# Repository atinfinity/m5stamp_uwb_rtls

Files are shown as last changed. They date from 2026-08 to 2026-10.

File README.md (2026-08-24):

# M5Stamp UWB RTLS



M5Stack Stamp UWB (Qorvo QM33120W) + Stamp C5による屋内2D RTLS(リアルタイム測位システム)。

> [!CAUTION]
> 本プロジェクトは**実機での動作確認をまだ行っていません**。データシート・公式ドキュメント・公式サンプルコードなどの公開情報をもとに実装しており、実機では動作しない・調整が必要となる可能性があります(ファームウェア、3Dプリントモデルの寸法などを含む)。

> [!NOTE]
> 本プロジェクトは**非公式の個人プロジェクト**です。M5Stack社・Qorvo社およびその関連企業とは一切関係ありません。

屋内UWB測位のイメージ(アンカー設置とタグ測位)

*屋内にアンカーを設置してタグを測位するイメージ。壁面・柱(高さ1.8〜2.5 m)の四隅にアンカーを設置し、タグが各アンカーへ順次[DS-TWR](docs/ds-twr-design.md)測距 → 得られた距離セットから最小二乗法で2D座標を推定する。配置設計の詳細は[docs/rtls-design.md](docs/rtls-design.md) §3.3を参照。*

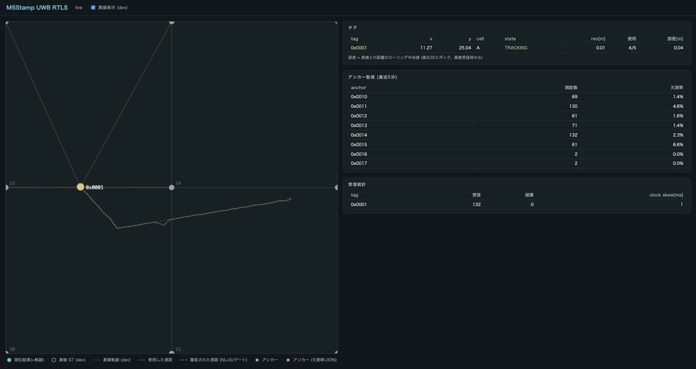
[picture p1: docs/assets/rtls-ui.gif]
RTLSフロアマップUI(仮想タグによるライブ動作)


*可視化UIの動作例(実機レス: 仮想タグ + シミュレータ)。**●** = 測位結果(実線 = 推定軌跡)、**○** = 真値GT(点線 = 真値軌跡、開発モード)、細実線 = 解算に使用した測距、**赤破線** = 外れ値除去/ゲートで棄却された測距(NLoS)。右側は監視パネル(アンカー別欠測率・受信統計)。凡例は画面下部に常時表示される。*

- 設計書: [docs/rtls-design.md](docs/rtls-design.md)(基本設計)ほか[docs/](docs/)配下
  - 測位サーバー(A案): [server-design.md](docs/server-design.md) / タグ上計算(B案): [tag-design.md](docs/tag-design.md)
  - 測距方式: [DS-TWR](docs/ds-twr-design.md)(採用)/ [SS-TWR](docs/ss-twr-design.md)(予備)/ [TDoA](docs/tdoa-design.md)(将来)
- ハードウェア: [docs/hardware.md](docs/hardware.md)(想定ハードウェアリスト・組み立て図)/ [hardware/cad/](hardware/cad/README.md)(アンカー取付具・タグ用ケースの3Dプリントモデル)
- ファームウェア: [firmware/](firmware/)(Step 1: DS-TWR 1対1計測 — Issue [#1](https://github.com/atinfinity/m5stamp_uwb_rtls/issues/1))
- 測位サーバー: [server/](server/)(実機レスで開発可能 — Issue [#3](https://github.com/atinfinity/m5stamp_uwb_rtls/issues/3))
- 開発ガイド: [環境構築](docs/development.md) / [構成カスタマイズ(アンカー・タグ)](docs/configuration.md) / [測位アルゴリズム開発](docs/algorithm-guide.md) / [アプリケーション開発](docs/application-guide.md)([examples/](examples/)にサンプルあり)

## クイックスタート(実機不要)

パッケージ管理は[uv](https://docs.astral.sh/uv/)を使用(`brew install uv`)。詳細な環境構築手順は **[docs/development.md](docs/development.md)** を参照。

```bash
uv sync --all-extras   # .venv 作成 + 依存インストール (dev グループ含む)

# テスト (解算・セル・e2e 回帰: シミュレータ→リプレイで CEP50 ≤ 0.30 m を検証)
uv run pytest

# 合成データ生成 → リプレイ
uv run python tools/simulate.py --config server/config.yaml --duration-s 120 \
    --out logs/sim_ranges.jsonl --truth logs/sim_truth.jsonl
uv run python -m server.replay logs/sim_ranges.jsonl --out logs/positions.jsonl
```

## ライブ実行(仮想タグでend-to-end)

サーバーと仮想タグは起動したまま動き続けるので、ターミナルを分けて実行する([docs/development.md](docs/development.md) §4):

```bash
mosquitto &                                          # MQTT ブローカー (brew install mosquitto)
uv run python -m server.app --config server/config.yaml   # 測位サーバー + Web UI (ターミナル 1)
uv run python tools/virtual_tag.py                        # 仮想タグ 3 台 (ターミナル 2)
```

ブラウザでhttp://localhost:8000 — フロアマップにタグ位置・軌跡・セルハンドオーバーがリアルタイム表示される。実機タグが用意できたらvirtual_tagを実機に差し替えるだけで同じ経路が動く。

## 実機作業(要ハードウェア)

Step 1のDS-TWR実測手順は[firmware/README.md](firmware/README.md)を参照。実測値の反映先はIssue [#1](https://github.com/atinfinity/m5stamp_uwb_rtls/issues/1)のチェックリストにまとめてある。

## 用語集(ドキュメント頻出の略語)

| 用語 | 意味 |
|---|---|
| CEP50 / CEP95 | 測位誤差の中央値 / 95パーセンタイル(Circular Error Probable)。「CEP50 ≤ 0.30 m」= 半数の測位が誤差30 cm以内 |
| LoS / NLoS | 見通しあり / 見通し外(Line of Sight)。遮蔽があるとUWBの測距値は伸びる方向に狂う |
| TWR(SS- / DS-) | Two-Way Ranging。電波の往復時間から1対1の距離を測る方式。SS = 片側往復、DS = 両側往復 |
| TDoA | Time Difference of Arrival。複数アンカーの受信時刻差から測位する方式(将来方式) |
| TDMA | 時分割多元接続。タグごとに送信時間帯(スロット)を割り当てて衝突を防ぐ |
| DOP | 精度劣化指数(Dilution of Precision)。アンカー配置の幾何が悪いほど誤差が拡大する |
| CFO | キャリア周波数オフセット(クロックずれ)。SS-TWRの成否を左右する([ss-twr-design.md](docs/ss-twr-design.md) §2.2) |
| GT | Ground Truth(真値)。シミュレータが出力する正解位置。UIでは ○ と点線で表示 |
| IRLS | 反復再重み付け最小二乗。C++ ソルバーがscipyの代わりに使う近似解法 |

## ライセンス

[Apache License 2.0](LICENSE)

ファームウェアのビルド時に取得される[M5Stamp-UWBライブラリ](https://github.com/m5stack/M5Stamp-UWB)(MIT。同梱のQorvo QM33120WドライバはQorvo独自ライセンス)など、依存ライブラリはそれぞれのライセンスに従う。

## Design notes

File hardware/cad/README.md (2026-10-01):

# 3D CADモデル(アンカー取付具・タグ用ケース)

[docs/hardware.md](../../docs/hardware.md)のハードウェアリストにある「アンカー取付具」「タグ用ケース」の3Dプリント用モデル。OpenSCADのパラメトリックソースと、書き出し済みSTLを置いている。

> **注意**: ボード寸法・背面FPCコネクタ/IPEXの位置は公式ドキュメントの寸法図([Stamp-C5 DIP](https://docs.m5stack.com/en/core/Stamp-C5_DIP) / [Stamp UWB F](https://docs.m5stack.com/en/stamp/stamp_uwb_f)の Model Size)から読み取った値(C5: 17.6×19.06×3.36 mm、うちUSB-C突き出し1.06 mm / UWB F: 幅12.02×長さ11.53×2.82 mm)。**実機でのフィット確認は未実施**。C5はDIP版付属のピンヘッダを**はんだ付けしない**前提(付けると収まらない)。印刷後に合わなければ`common.scad`の`tol`(片側クリアランス)や各パラメータを調整すること。

## ファイル

| ファイル | 内容 |
|---|---|
| `common.scad` | ボード公称寸法・公差などの共通パラメータ |
| `anchor_mount.scad` | アンカー取付具(壁面・柱用Lブラケット) |
| `tag_case.scad` | タグ用ケース(本体 + フタ。`part`で切替) |
| `stl/*.stl` | 書き出し済みSTL(`anchor_mount` / `tag_case_body` / `tag_case_lid`) |
| `Makefile` | STLとdocs用プレビューPNGの再生成 |

## 設計の要点

**アンカー取付具**(`anchor_mount.scad`)

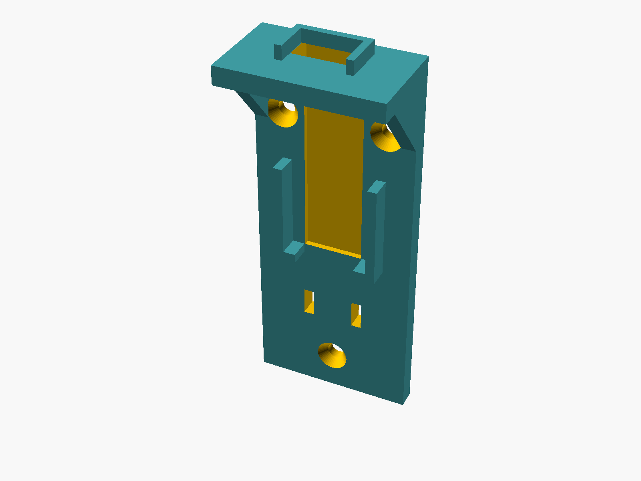
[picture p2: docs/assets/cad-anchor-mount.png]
アンカー取付具3Dモデル


- 垂直プレートを皿ネジM3×3本で壁・柱に固定。プレート前面のポケットにC5、上部棚の上面ポケットにUWB Fを置く(固定は薄手の両面テープを想定)
- アンカーはWi-Fiを使わないため、C5付属のWi-Fiアンテナは取り付けなくてよい(取付具にも収納場所はない)
- UWB Fの**アンテナ端は棚の前縁(壁と反対側)を向き、周囲に樹脂・壁が無い**(基本設計 §3.3の「金属・壁から離して突き出す」要求に対応)
- FPCはプレート前面の溝 → 棚のスリット経由で両ボードの背面コネクタへ(ボードは部品面が表)
- USB給電ケーブルは下方へ引き出し、ケーブルタイ用スリットで張力止め

**タグ用ケース**(`tag_case.scad`)

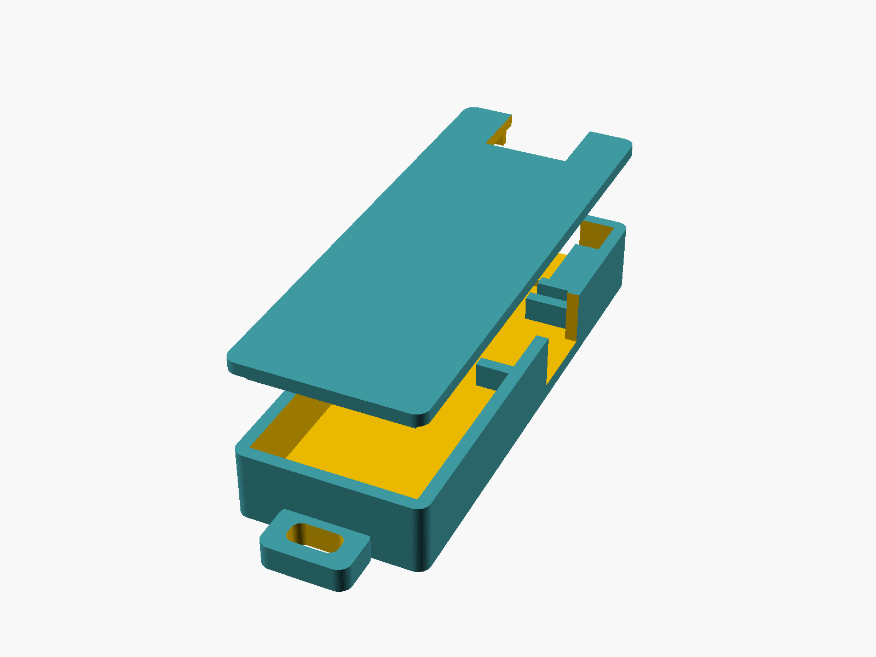
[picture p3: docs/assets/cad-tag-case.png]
タグ用ケース3Dモデル(本体とフタ)


- 内部は長手方向にLiPo | C5 | FPC折り返し部 | UWB F。両ボードとも部品面を上にして置き、背面FPCコネクタは床の凹みに収まる
- C5はUSB-Cを+x側壁に突き当てて置く(VBAT/GNDパッドの列がバッテリー側を向く)。C5の背面FPCコネクタはUSB-Cと反対の端寄りにあり、ケーブルはその端へ出るため、-x側の空きで立ち上げてC5の上を渡し、折り返し部で床に下ろしてUWB Fのコネクタへ差す
- UWB F側の床溝はアンテナ部の下まで延ばさない(公式の注意: FPCをPCBアンテナの下に通さない)
- UWB Fの**アンテナ端はケース端・フタの開口(アンテナ窓)で樹脂に覆われない**
- C5のUSB-Cは側壁スロットから充電・書き込み可能。バッテリー端にストラップループ
- C5同梱のWi-Fi用FPCアンテナ(14.3×5.3 mm、IPEX-1)は**フタ裏の凹み(C5の上、+x寄り)に貼る**。C5の上を渡るFPCケーブル・UWB F・LiPoから離して配置し、ケーブル(50 mm)はキャビティ内で余らせる
- フタはスカートによる摩擦嵌合。LiPo寸法は`bat`パラメータ(既定25.5×37×5.2 mm = [docs/hardware.md](../../docs/hardware.md) §1.4の候補例 DPTL-DTP502535 400 mAh)で変更

## 印刷設定の目安

- PLA / PETG、レイヤー0.2 mm、インフィル20% 程度
- 向き: 取付具は背面(壁側)をベッドへ、ケース本体は底面、フタは天面をベッドへ → **いずれもサポート不要**

## 再生成

macOSで[OpenSCAD](https://openscad.org/)をインストール(`brew install --cask openscad`)して:

```bash
cd hardware/cad
make          # stl/ と docs/assets/cad-*.png を再生成
# OpenSCAD のパスが違う場合: make OPENSCAD=/path/to/OpenSCAD
```

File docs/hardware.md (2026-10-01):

# ハードウェアガイド(想定ハードウェアリスト・組み立て)

本システムで想定しているハードウェアの一覧と、ノード(アンカー・タグ)の組み立て方をまとめる。設計上の根拠(選定理由・BOM概算・配置設計)は基本設計[rtls-design.md](rtls-design.md) §3を参照。

数量は**タグ1台 + アンカー1台**の最小構成(DS-TWR 1対1測距 = [firmware/README.md](../firmware/README.md) Step 1相当)で記載する。2D測位では1セルあたりアンカー4台が標準(解算だけなら3台が下限)。実運用の数量(アンカー8〜12 + タグ2〜5)と価格概算は[rtls-design.md](rtls-design.md) §3.1〜3.3を参照。

## 1. 想定ハードウェアリスト

アンカー・タグはどちらも**M5Stamp C5 + M5Stamp UWB F**の同一ユニットで、ファームウェアと電源だけが異なる。

### 1.1 アンカー用(1台分)

| 品目 | 用途 | 数量 | 備考 |
|---|---|---|---|
| [M5Stamp C5](https://shop.m5stack.com/products/m5stampc5-module-esp32-c5)(ESP32-C5) | メインMCU | 1 | アンカーはWi-Fi接続不要(UWB応答専用) |
| [M5Stamp UWB F](https://shop.m5stack.com/products/m5stamp-uwb-module-with-fpc-qm33120w)(Qorvo QM33120W、FPC版) | UWB測距モジュール | 1 | 0.5mm-12P FPCケーブル付属。[無印版](https://shop.m5stack.com/products/m5stamp-uwb-module-qm33120w)(キャスタレーション実装)は量産フェーズ向けで、プロトタイプはFPC版を推奨 |
| USB ACアダプタ + USB-Cケーブル | 常時給電 | 1 | モバイルバッテリーでも可 |
| アンカー取付具 | 壁面・柱への設置 | 1 | 3Dプリント(モデルは[hardware/cad/](../hardware/cad/)、§4参照)。アンテナ部を遮らない形状 |

### 1.2 タグ用(1台分)

| 品目 | 用途 | 数量 | 備考 |
|---|---|---|---|
| [M5Stamp C5](https://shop.m5stack.com/products/m5stampc5-module-esp32-c5)(ESP32-C5) | メインMCU + Wi-Fiテレメトリ | 1 | Wi-Fi 6(2.4/5 GHz)対応。SGM40567充電IC・電池端子内蔵 |
| [M5Stamp UWB F](https://shop.m5stack.com/products/m5stamp-uwb-module-with-fpc-qm33120w)(Qorvo QM33120W、FPC版) | UWB測距モジュール | 1 | 同上(FPCケーブル付属) |
| LiPoバッテリー3.7 V 400〜1000 mAh | 電源 | 1 | Stamp C5のVBAT/GNDパッドにはんだ付け。充電はUSB-C経由 |
| タグ用ケース | 装着用筐体 | 1 | 3Dプリント(モデルは[hardware/cad/](../hardware/cad/)、§4参照)。アンテナ部を遮らない形状 |

### 1.3 共通(システム全体で)

| 品目 | 用途 | 数量 | 備考 |
|---|---|---|---|
| PC(常設ならRaspberry Piも可) | 測位サーバー(Mosquitto + Python解算/可視化) | 1 | |
| Wi-Fi AP(2.4/5 GHz) | タグ→サーバーのテレメトリ経路 | 1 | 既設流用可。アンカーはWi-Fi不要 |
| レーザー距離計 | アンカー座標の測量・校正 | 1 | 推奨(±3 cm以内で座標登録するため) |

### 1.4 購入時の注意

- **国内での入手先**: スイッチサイエンスで[M5Stamp UWBモジュール(FPCコネクタ、FPCケーブル付き)M5STACK-S017-F](https://www.switch-science.com/products/11375)と[M5StampC5 DIP M5STACK-S016-DIP](https://www.switch-science.com/products/11352)が扱われており、本ドキュメントの想定構成と一致する。アンカー・タグとも同一ユニットなので、両方をノード台数分そろえる。
- **Stamp C5「DIP」版のピンヘッダ**: DIP版には2.54mm-7Pピンヘッダ2本が付属するが、UWB FとはFPCで直結するため**はんだ付けは不要**。§4の3Dプリントモデルはヘッダなしの公称寸法で作っているので、ヘッダを付けるとケース・取付具に収まらない可能性がある。
- **Wi-Fi用外付けアンテナ**: Stamp C5のWi-Fiは付属アンテナ(FPCアンテナ、2.4/5 GHz、IPEX-1、14.3×5.3 mm、ケーブル長50 mm。[公式ドキュメント](https://docs.m5stack.com/en/core/Stamp-C5)参照)をIPEX-1コネクタにつないで使う。Stamp C5に同梱されているので別途購入は不要。タグはWi-Fiテレメトリに必須(アンカーはWi-Fi不要)。タグ用ケースではフタ裏の凹みに貼る(§4.2)。
- **LiPoバッテリーは別途必要**(タグのみ)。Stamp C5の充電電流は約200 mAなので、1C充電で200 mA以上を受け入れられる容量(目安400 mAh以上)を選ぶ。候補例(いずれもDATA POWER TECHNOLOGY製、JST PH 2ピン、保護回路付き。2026年10月時点で千石電商に在庫あり。購入時に在庫を確認):
  - [DTP502535(PHR) 400mAh](https://www.sengoku.co.jp/mod/sgk_cart/detail.php?code=EEHD-4YZL)(25×36×5 mm、10 g以下)— §4のタグ用ケースの既定寸法(`bat`)で収まる。推奨
  - [DTP603048(PHR) 860mAh](https://www.sengoku.co.jp/mod/sgk_cart/detail.php?code=EEHD-4YZM)(30×49×6 mm、18 g以下)— 長時間向け。タグ用ケースは`bat`を変更して再生成する(幅約5 mm・長さ約12 mm大きくなる)

  スイッチサイエンスの同型400mAh品([3118](https://www.switch-science.com/products/3118))は2026年10月時点で品切れ。

  Stamp C5にバッテリー用コネクタはなく、2.54 mmピッチのパッド列の**VBAT(+)とGND(−)**に配線する([公式ピン配置図](https://docs.m5stack.com/en/core/Stamp-C5_DIP)。部品面を上・USB-Cを手前にして左列の上から3V3 / G1 / G2 / G3 / **VBAT** / USB_5V / **GND**)。JST PHコネクタ付きの電池をそのまま使うなら、[JST PH 2ピン付きワイヤ](https://switch-science.com/catalog/2215)をパッドにはんだ付けして中継する。電池側の極性(赤=+)も挿す前に確認すること。§4のタグ用ケースはLiPo寸法を`bat`パラメータで変更できる。

## 2. 組み立て図

Stamp C5とStamp UWB Fは、UWB F付属の**0.5mm-12P FPCケーブル1本**で直結する。FPCにSPI 5線+制御2線+電源がまとまっており、Stamp C5背面FPCコネクタのピン割当が公式サンプルの想定(SCK=G12, MISO=G26, MOSI=G27, CS=G11, RST=G25, IRQ=G0, WAKEUP=G24, GP7=G23)と一致しているため、**はんだ付け・配線作業は不要**。

### 2.1 アンカーノード

アンカーノード組み立て図(1台分)

### 2.2 タグノード

タグノード組み立て図(1台分)

## 3. 組み立て手順

1. **FPC接続**: Stamp C5背面とStamp UWB FのFPCコネクタに付属ケーブルを挿し、コネクタのロックを閉じる(アンカー・タグ共通)。**ケーブルの向きを誤るとモジュールを破損するおそれがある**(製品ページの注意事項)ため、公式の接続図で向きを確認してから挿す。なお、UWB FのFPCピン配置はStamp-S3/S3Aとは互換性がない(Stamp C5とは一致する)。
2. **Wi-Fiアンテナ接続**(タグ): Stamp C5のIPEX-1コネクタに付属アンテナを接続する。
3. **電源接続**:
   - アンカー: USB ACアダプタまたはモバイルバッテリーからUSB Type-Cで常時給電。
   - タグ: LiPoバッテリーをStamp C5のVBAT/GNDパッドへ接続(§1.4。充電はUSB-C経由)。開発初期はUSB給電でよい(下記「開発初期の給電」参照)。
4. **ファームウェア書き込み**: USB-CでPCに接続し、[firmware/](../firmware/)の手順でanchor / tagを書き込む。
5. **筐体・設置**: ケース・取付具(§4の3Dプリントモデル)に収める。以下のアンテナ取り扱いに注意する。

### 開発初期の給電

ケースに組み込む前の開発初期は、アンカー・タグともUSB Type-Cから給電すればよい。LiPoのはんだ付けはケースへの組み込み時([#49](https://github.com/atinfinity/m5stamp_uwb_rtls/issues/49))まで後回しにできる。

- **PCのUSB**: 給電とシリアルログ取得を兼ねられる。[firmware/README.md](../firmware/README.md) Step 1のDS-TWR 1対1測距では、ログを取る側をPCにつなぐ。
- **モバイルバッテリー**: PCから離して置くノード(アンカーや、距離を変えながら測るタグ)に使う。
  - **低電流での自動電源オフに注意**。多くの製品は出力がおおむね50〜100 mA以下になると数十秒〜数分で給電を止める。UWB Fの消費電流は公式値で受信側(アンカー)約58 mA、発信側(タグ)約5 mA(C5側は未確認)のため、省電力設定次第では自動オフの条件に入りうる。「低電流モード」「IoTモード」付きの製品を選ぶか、アンカーのように据え置くノードはUSB ACアダプタにする。測距が途中で止まったら、まず給電断を疑う。
- **電源ノイズ**: UWB Fは公式に「高PSRRのLDO、またはリップル12 mVpp以内の電源」を求めている。USBの5VはC5上で3.3Vに変換してからUWB Fに供給されるが、その変換回路の特性は未確認。測距値のばらつきが大きいときは、USB ACアダプタやPCのUSBに替えて比べ、電源が原因かを切り分ける。
- LiPoを取り付けた後は、USBとLiPoを同時につないでよい(C5の充電IC SGM40567がUSB接続時にLiPoを充電する)。

### アンテナ取り扱いの注意(重要)

- **アンテナ端が金属・壁から離れるよう突き出して取り付ける。金属板への直付けは禁止**(公式ドキュメントの要求)。
- 机上での実験時も、アンテナ端が金属・机面に近づかないよう治具等で浮かせる([firmware/README.md](../firmware/README.md) Step 1参照)。
- アンカーの設置高さ・配置(高さ1.8〜2.5 m、セル四隅、座標測量)は[rtls-design.md](rtls-design.md) §3.3を参照。

## 4. 3Dプリントモデル(アンカー取付具・タグ用ケース)

OpenSCADソースとSTLを **[hardware/cad/](../hardware/cad/)** に置いている(パラメータ調整・再生成の方法は同ディレクトリの[README](../hardware/cad/README.md)を参照)。公称寸法ベースのv1モデルのため、印刷後に実機でフィット確認し`tol`等を調整すること。

### 4.1 アンカー取付具

アンカー取付具3Dモデル

壁面・柱用のLブラケット([anchor_mount.scad](../hardware/cad/anchor_mount.scad) / [STL](../hardware/cad/stl/anchor_mount.stl))。皿ネジM3×3本で固定し、前面ポケットにC5、上部棚にUWB Fを置く。UWB Fのアンテナ端は棚の前縁(壁と反対側)を向き、「金属・壁から離して突き出す」要求(§3アンテナ注意・[rtls-design.md](rtls-design.md) §3.3)を満たす。FPCはプレート前面の溝と棚のスリットを通す。

### 4.2 タグ用ケース

タグ用ケース3Dモデル(本体とフタ)

本体 + 摩擦嵌合フタの2部品([tag_case.scad](../hardware/cad/tag_case.scad) / STL: [本体](../hardware/cad/stl/tag_case_body.stl)・[フタ](../hardware/cad/stl/tag_case_lid.stl))。内部はLiPo | C5 | FPC折り返し部 | UWB Fの順で、アンテナ端はケース端とフタの開口(アンテナ窓)により樹脂で覆われない。FPCケーブルはC5の上を渡して折り返し部で床に下ろす(経路の詳細は[hardware/cad/README.md](../hardware/cad/README.md))。USB-Cは側壁スロットから充電・書き込み可能で、バッテリー端にストラップループ付き。C5のWi-Fi用FPCアンテナはフタ裏の凹み(C5の上、+x寄り)に貼る。LiPo寸法は`bat`パラメータで変更できる(既定は§1.4の400 mAh品)。

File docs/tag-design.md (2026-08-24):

# タグ上測位詳細設計書(B案: タグ上計算)

- 作成日: 2026-08-15
- ステータス: ドラフト(実装前レビュー用)
- 上位文書: [rtls-design.md](rtls-design.md)(基本設計 §5の「B案: タグ上計算」の詳細設計)
- 関連文書: [server-design.md](server-design.md)(A案。解算アルゴリズムは本書と共通仕様)

## 1. スコープと位置づけ

本書は、**タグ(ESP32-C5)上で測距から座標解算までを完結**させる構成の詳細設計を定める。基本設計 §5の比較で標準構成はA案(サーバー計算)としたため、B案は次の用途を主対象とする。

| 想定用途 | 説明 |
|---|---|
| **自律移動体搭載** | ロボット・AGVがタグを搭載し、自己位置を低レイテンシで直接利用する(サーバー往復 +20〜100 msを排除) |
| サーバーレス運用 | 可視化・記録が不要で、座標を外部システム(ROS等)へ直接渡すだけの構成 |
| ネットワーク断耐性 | Wi-Fiが不安定な環境でも測位自体は継続する必要がある場合 |

**設計方針: A案と同一の解算仕様(§4)をC++ に移植し、A案に劣る点(デバッグ性・チューニング性)を「生距離の並行送信」と「OTA更新」で緩和する。** 解算アルゴリズムの仕様はserver-design.md §5を正とし、本書ではESP32実装に固有の差分のみ規定する。

## 2. システム構成と動作モード

```mermaid
flowchart LR
    subgraph tag["タグ (Stamp C5 + UWB F)"]
        RNG["ranging<br/>TDMA スロット測距"]
        SOL["solver<br/>補正→LSQ→外れ値除去→カルマン"]
        CFG["config_store<br/>アンカー座標・セル表 (NVS)"]
        OUT["output<br/>座標出力の抽象層"]
        RNG --> SOL
        CFG --> SOL
        SOL --> OUT
    end
    OUT -- "① MQTT position" --> BR["MQTT ブローカー"]
    OUT -- "② UART (ROS 等)" --> HOST["搭載ホスト<br/>(ロボット制御器)"]
    RNG -. "生距離も並行 publish<br/>(debug_ranges 有効時)" .-> BR
    BR -- "config/anchors (retained)" --> CFG
    BR -- "OTA 通知" --> tag
```

| モード | 出力 | 用途 |
|---|---|---|
| `HYBRID`(既定) | MQTTへposition **と生距離の両方**をpublish | 開発・チューニング期。サーバー側リプレイ(A案 §8)をそのまま使える |
| `STANDALONE` | UART(またはUDPユニキャスト)へpositionのみ | ロボット搭載。Wi-Fiなしでも測位継続 |
| `QUIET` | MQTTへpositionのみ | 帯域・電力を絞る本番運用 |

モードはNVS設定で切替(ビルド不要)。**HYBRIDを既定とし、B案の最大の弱点「座標しか見えず誤差原因を追えない」を運用で回避する。**

## 3. ファームウェア構成(PlatformIO)

```
firmware/tag/
├── platformio.ini           # env:tag (esp32-c5) / env:native (ホストテスト用)
├── src/
│   ├── main.cpp             # 起動・タスク生成
│   ├── ranging.cpp/.h       # TDMA スロット管理・アンカー巡回測距
│   ├── net.cpp/.h           # Wi-Fi / SNTP / MQTT / OTA
│   ├── config_store.cpp/.h  # NVS 永続化と config/anchors 受信反映
│   └── output.cpp/.h        # position の出力先抽象化 (MQTT/UART/UDP)
├── lib/rtls_solver/         # ★解算ライブラリ(ハード非依存・ヘッダオンリー)
│   ├── geometry.hpp         # 高低差補正・線形化LSQ・Gauss-Newton
│   ├── outlier.hpp          # ゲーティング・leave-one-out
│   ├── kalman.hpp           # CV モデル 2D カルマン (4状態、固定サイズ行列)
│   └── pipeline.hpp         # §4 のパイプライン統合
└── test/                    # env:native で動く solver 単体テスト
```

**`rtls_solver`はArduino APIに依存させない**(素のC++17、`float`固定サイズ配列のみ)。これにより:

- PlatformIOの`env:native`でホストPC上の単体テストが回る(実機不要)
- A案のシミュレータ出力(ranges JSONL)をホストで流し込み、**Python実装との解算結果一致試験**ができる(§8)

### FreeRTOSタスク構成

| タスク | 優先度 | 周期/契機 | 役割 |
|---|---|---|---|
| `ranging_task` | 高 | TDMAスロット到来 | アンカー巡回DS-TWR → RangeSet生成 → solver呼出し → outputへ渡す |
| `net_task` | 中 | イベント駆動 | MQTT送受信、SNTP再同期(**5分毎・スルー補正+ドリフト率補正**、rtls-design.md §4.9)、OTA受付 |
| `monitor_task` | 低 | 1 s | ヒープ・測距成功率・スロットずれの統計、LED表示 |

solverは`ranging_task`内で同期実行する(実測目標 < 5 ms、§7)。キュー渡しにしないことでスロット内で解算まで完結し、座標のタイムスタンプが単純になる。

## 4. 解算パイプライン(C++ 移植仕様)

処理段構成・パラメータ・状態機械(INIT/TRACKING/COASTING/STALE/LOST)は**server-design.md §5と同一**。ESP32実装での差分のみ示す。

| 段 | A案(Python) | B案(C++)の実装 |
|---|---|---|
| ① 検証 | pydantic | 不要(自プロセス内でRangeSetを生成するため。okフラグ確認のみ) |
| ② 高低差補正 | 同一式 | 同一式(`sqrtf`) |
| ③ ゲーティング | 同一 | 同一 |
| ④ 線形化LSQ | `numpy.linalg.lstsq` | 正規方程式`AᵀA x = Aᵀb`を**2×2の手解き**(逆行列公式)。条件数チェック(detが小さい=共線配置なら解算失敗扱い) |
| ⑤ リファイン | `scipy.least_squares` (soft_l1) | **Gauss-Newton最大5反復** + Huber重み(δ=0.3 m)。2×2正規方程式の反復なので軽量。発散(ステップ > 1 m)時は線形解を採用 |
| ⑥ 外れ値除去 | 最悪1距離除外・1回 | 同一 |
| ⑦ カルマン | numpy | 4×4固定サイズ行列をベタ書き(行列ライブラリ不使用)。`float`で十分(座標50 m / 分解能cm) |

**数値仕様**: 全計算`float`(単精度)。距離二乗の桁(最大55² ≈ 3000)でもfloatの7桁精度でcm分解能を維持できるが、線形化LSQの右辺`(x_i²−x_1²)`等は**座標をフロア中心原点に平行移動してから計算**し桁落ちを防ぐ。

## 5. アンカー座標・セル表の配布(config_store)

B案固有の課題: A案ではサーバーだけが持っていたアンカー座標・セル定義を**全タグが持つ**必要がある。

- サーバー(または管理PCの配布スクリプト)が`rtls/config/anchors`に**retained + version付き**で全体設定をpublishする:

```json
{"version": 3,
 "tag_height_m": 1.0,
 "anchors": {"0x0010": {"x": 0.0, "y": 0.0, "z": 2.2, "bias_mm": -35}, "...": {}},
 "cells":   {"A": {"rect": [0,0,25,25], "anchors": ["0x0010","0x0011","0x0013","0x0014"]}}}
```

- タグは起動時と受信時にversionを比較し、新しければ**NVSに保存して即反映**。以後はWi-Fi断でもNVSの設定で動作継続(STANDALONEモードの前提)。
- 12アンカー + 8セルでJSON約2 KB、NVS使用量は問題にならない。パース失敗時は旧設定を維持。
- **セル判定・ハンドオーバーはタグ自身が実行**(アルゴリズムはserver-design.md §6と同一のヒステリシス)。サーバーからのアンカーリスト配信(`rtls/tag/{id}/anchors`)は不要になり、A案とのトピック互換のため受信しても無視する。

## 6. TDMAスロット内の処理シーケンス

基本設計 §4.4のスーパーフレーム(500 ms、スロット90 ms)の中で解算まで行う。

```mermaid
sequenceDiagram
    participant S as ranging_task
    participant U as UWB (QM33120W)
    participant K as solver
    participant O as output
    Note over S: SNTP 時刻で自スロット開始を検出
    loop 担当アンカー 4 台
        S->>U: requestDSRange(anchor_i)
        U-->>S: 距離 or タイムアウト(必要なら1回リトライ)
    end
    S->>K: RangeSet(4距離, t_ms)
    K->>K: 補正→ゲート→LSQ→GN→外れ値→カルマン
    K-->>S: Position (x, y, state, residual)
    S->>K: セル判定(ヒステリシス)→次スロットの巡回リスト更新
    S->>O: Position 出力
    par HYBRID モード時
        O->>O: MQTT: position + ranges を publish(net_task キュー経由)
    and STANDALONE モード時
        O->>O: UART: バイナリフレーム送出 (< 1 ms)
    end
```

### スロット内時間予算(90 ms、実測で確定させる)

| 処理 | 予算 |
|---|---|
| DS-TWR × 4(リトライ1回込み) | ~60 ms(1回5〜10 ms想定 — 基本設計ロードマップStep 1で実測) |
| アンカー間ギャップ × 3 | ~6 ms(`kDsInterAnchorGapMs` = 2 ms。Step 1で最小値を実測) |
| 解算(§4パイプライン) | < 5 ms(目標。240 MHzで数十 µsオーダーの見込み) |
| 出力(UART即時 / MQTTはキュー投入のみ) | < 1 ms |
| ガード余裕 | 残り ~25 ms |

MQTTの実送信は`net_task`が非同期に行い、**スロット時間をWi-Fiの遅延で食わない**。

## 7. UART出力仕様(STANDALONE / ロボット搭載向け)

115200 bps、バイナリフレーム(リトルエンディアン):

| オフセット | 型 | 内容 |
|---|---|---|
| 0 | uint8×2 | ヘッダ`0xB5 0x50` |
| 2 | uint8 | tag_id |
| 3 | uint8 | state (0=INIT,1=TRACKING,2=COASTING,3=STALE,4=LOST) |
| 4 | uint32 | t_ms(SNTP同期時刻の下位32bit) |
| 8 | float×4 | x_m, y_m, vx_ms, vy_ms |
| 24 | float | residual_m |
| 28 | uint8 | n_used |
| 29 | uint8 | checksum(0〜28のXOR) |

30バイト固定。2 Hzなら帯域は無視できる。ROS側はシリアルノードでこのフレームを`PoseWithCovarianceStamped`に変換する想定(residualから共分散を組み立てる)。

## 8. チューニング・デバッグ戦略(B案の弱点への対策)

| A案に劣る点 | 本設計での緩和策 |
|---|---|
| アルゴリズム変更のたびに書き込みが必要 | **OTA更新**(`esp_https_ota`、`net_task`がMQTTの更新通知で起動)。全タグへ一括配信 |
| 誤差原因(どの距離が狂ったか)を追えない | **HYBRIDモード**で生距離を並行publish → A案のrecorder/replayがそのまま使える |
| パラメータ試行錯誤が遅い | `tuning`パラメータ(gate、residual_gate、σ 類)を**NVS + MQTT `rtls/config/tuning`(retained, version付き)** で配布し、書き込み不要で変更 |
| 解算実装がPythonと乖離するリスク | `rtls_solver`を`env:native`でビルドし、**同一ranges入力に対するPython実装との一致試験**(許容差1 cm)をCI的に実行 |

## 9. リソース見積もり

| 項目 | 見積もり | 備考 |
|---|---|---|
| solverコード + 状態 | < 10 KB RAM | 4×4行列float数個 + 履歴なし |
| config(12アンカー + セル表) | ~4 KB RAM / ~2 KB NVS | |
| Wi-Fi + MQTT + TLSなし | ~50 KB RAM | ESP32標準スタック |
| 合計 | 384 KB SRAMに対し余裕 | PSRAM不要 |
| 解算CPU時間 | 数十 µs〜1 ms /エポック | 240 MHz、FPUあり |
| 消費電力への影響 | 解算分は無視できる(支配項はUWB測距とWi-Fi) | 基本設計 §7のタグ電池リスクと同じ |

## 10. テスト計画

1. **ホスト単体テスト(`env:native`、実機不要)**: server-design.md §13の1. と同一ケース(合成ジオメトリ、NLoS注入、軌跡追従、縮退配置)をC++ 側でも実行。
2. **Python一致試験**: A案シミュレータのranges JSONLをホストビルドのsolverに入力し、Python実装のpositionsと突き合わせる。許容差: **中央値 ≤ 1 cm・p99 ≤ 2 cm・最大 ≤ 10 cm**(外れ値除去が発火するエポックはscipy soft_l1とIRLS Gauss-Newtonの反復差がcm級で現れるため。実測: 中央値0.0 mm / p99 0.34 mm / 最大16.9 mm、状態一致100%)。**以後、アルゴリズム変更は必ず両実装同時に行う**ことをルール化。
3. **実機タイミング試験**: スロット内の各処理時間(測距×4、解算、出力)を`esp_timer`で計測し、§6の時間予算表を実測値で更新。90 msに収まらない場合はリトライ回数かアンカー数を調整。
4. **断線試験**: Wi-Fi AP停止 → STANDALONE動作(UART出力継続)→ 復帰後のMQTT再接続とconfig version追従を確認。
5. **受入基準**: A案と同一(CEP50 ≤ 0.30 m等)+ UART出力レイテンシ(測距完了→フレーム送出)p95 < 10 ms。

## 11. A案との使い分け・移行

- **開発は常にA案の環境(シミュレータ・リプレイ・可視化)で先行**し、確定したアルゴリズム・パラメータをB案へ移植する流れとする(§8の一致試験が橋渡し)。
- タグFWはA案構成でもB案構成でも**測距・TDMA部分(`ranging.cpp`)は共通**。差分は「solverを積むか」「何をpublishするか」のみで、ビルドフラグ`-DENABLE_ONBOARD_SOLVER`で切り替える。
- 運用上の推奨: 人・資産の追跡はA案、ロボット搭載タグのみB案(HYBRIDモード)、という**混在構成**が可能。B案タグの生距離もサーバーに届くため、フロア全体の監視・記録はA案側に一元化できる。

## 12. 実装順序

1. `rtls_solver`(ヘッダオンリー)+ `env:native`単体テスト — A案 §15の2. のPython実装と並走
2. Python一致試験(§10の2.)の整備
3. `ranging.cpp`のTDMA化(基本設計Step 3と共通作業)
4. `config_store` + `rtls/config/#`配布フロー
5. `output`(MQTT HYBRID → UART)+ 実機タイミング試験
6. OTA・`rtls/config/tuning`反映 — 運用開始後のチューニングループ確立

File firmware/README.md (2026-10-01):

# ファームウェア

| 対象 | env | 内容 |
|---|---|---|
| `tag`(本番) | `tag` | アンカー巡回 + TDMA + Wi-Fi/MQTT(Step 2/3、Issue [#6](https://github.com/atinfinity/m5stamp_uwb_rtls/issues/6)) |
| `tag`(計測) | `tag_step1` | 1対1 DS-TWR + CSV出力(Step 1、Issue [#1](https://github.com/atinfinity/m5stamp_uwb_rtls/issues/1)) |
| `tag`(計測・SS) | `tag_step1_ss` | 1対1 SS-TWR検証(Issue [#14](https://github.com/atinfinity/m5stamp_uwb_rtls/issues/14)) |
| `anchor` | `anchor` | DS-TWR応答専用 |
| `anchor`(SS) | `anchor_ss` | SS-TWR応答(検証用) |
| `tdoa_poc` | `blink_tx` / `listener` | TDoA PoC: 周期ブリンク送信 / RXタイムスタンプ計測(Issue [#16](https://github.com/atinfinity/m5stamp_uwb_rtls/issues/16)) |

Arduino非依存ロジック(TDMAスロット判定・MQTTペイロード生成/解析)は`lib/rtls_common/`にあり、
`./test_native/run.sh`でホスト上の単体テストが実行できる(CIでも実行)。

## 本番モード(env:tag)

Wi-Fi / MQTT / SNTPの接続先は`firmware/tag/platformio.ini`の`build_flags`で指定する
(`WIFI_SSID` / `WIFI_PASS` / `MQTT_HOST`。SNTPは既定でMQTT_HOSTのchronyを使用 — 基本設計 §4.9)。

```bash
cd firmware/tag
pio run -e tag -t upload          # 本番モード
pio run -e tag_step1 -t upload    # Step 1 計測モード
```

動作: SNTP同期後、自スロット(アドレスから決まる90 ms窓、スーパーフレーム500 ms)で
担当アンカー4台へ順次DS-TWR → `rtls/tag/{addr}/ranges`へpublish。
`rtls/tag/{addr}/anchors`(retained)を受信すると担当リストを差し替える(セルハンドオーバー)。

---

# Step 1: DS-TWR 1対1実測

Issue [#1](https://github.com/atinfinity/m5stamp_uwb_rtls/issues/1) / 設計: [ds-twr-design.md](../docs/ds-twr-design.md) §6

## ハードウェア準備

- M5Stamp C5 + Stamp UWB Fを**2セット**。各セットは付属の0.5mm-12P FPCケーブルで直結(ピン割当は自動で`rtls_common.h`と一致)。組み立ての詳細は[docs/hardware.md](../docs/hardware.md)を参照
- 両ノードUSB-CでPCへ接続(タグ側は計測ログの採取にシリアルを使う)
- アンテナ端が金属・机面に近づかないよう治具等で浮かせる(基本設計 §3.3)

## ビルドと書き込み

ESP32-C5のArduinoサポートはpioarduino版platformを使用(platformio.ini設定済み)。

platformとライブラリはバージョンを固定している(platform 55.03.311 = Arduino core 3.3.11、M5Stamp-UWB v0.1.1)。`stable`の最新版はPlatformIO Core 6.2.0以上が必要なため、更新する場合はCoreも上げてから全envのビルドとStep 1の再計測で確認すること。

```bash
# アンカー (addr 0x0010)
cd firmware/anchor
pio run -t upload

# タグ計測モード (addr 0x0001 → anchor 0x0010 へ 50ms 間隔で測距)
cd ../tag
pio run -e tag_step1 -t upload
```

アドレス・測距間隔は各`platformio.ini`の`build_flags`(`NODE_ADDR` / `TARGET_ANCHOR` / `RANGE_INTERVAL_MS`)で変更する。

> **注**: board定義は汎用の`esp32-c5-devkitc-1`を使用している。書き込みに失敗する場合は
> `pio device list`でポートを確認し、`upload_port`を明示すること。

## 計測手順(ds-twr-design.md §6の1. と2.)

1. 既知距離(レーザー距離計で測定)にタグ・アンカーを設置(高さを揃える)
2. タグのシリアルをcapture.pyで採取:

```bash
uv run --with pyserial python tools/step1/capture.py --port /dev/tty.usbmodemXXXX \
    --true-dist-m 5.000 --count 1000 --out logs/dist5m.csv
```

3. 距離を変えて繰り返し(1 / 5 / 10 / 20 / 40 m)
4. 解析:

```bash
uv run python tools/step1/analyze.py logs/dist*.csv
```

出力(成功率、bias、σ、交換時間p50/p95/p99)をIssue [#1](https://github.com/atinfinity/m5stamp_uwb_rtls/issues/1)に記録し、以下を更新する:

- `bias_mm`校正値 → server設計 §10のconfig.yamlへ
- 交換時間p95 → 基本設計 §4.4のTDMAスロット幅
- `rtls_common.h`のタイミング定数 — アンカーの応答遅延はライブラリ設定`responseTxDelayUus`に
  代入される定数`kDsResponseTxDelayUus`で決まる。3000→1500 µsに詰める実験は、この定数を
  変更して同手順で比較する

### アンカー間ギャップの計測(4アンカー巡回、Issue [#43](https://github.com/atinfinity/m5stamp_uwb_rtls/issues/43))

アンカーを4台(`0x0010`〜`0x0013`)起動し、タグの`platformio.ini`で`TARGET_ANCHOR`の代わりに
`-DTARGET_ANCHORS=0x0010,0x0011,0x0012,0x0013 -DRANGE_INTERVAL_MS=200 -DINTER_ANCHOR_GAP_MS=<ms>`
を指定してビルド・書き込む。ギャップを0 / 2 / 5 / 20 msで振り、同じcapture.pyで採取する:

```bash
uv run --with pyserial python tools/step1/capture.py --port /dev/tty.usbmodemXXXX \
    --true-dist-m 5.000 --count 2000 --out logs/gap2ms.csv    # 4アンカー × 500サイクル
uv run python tools/step1/analyze.py logs/gap*.csv            # アンカー別成功率 + サイクル時間p50/p95
```

成功率を落とさない最小ギャップを`rtls_common.h`の`kDsInterAnchorGapMs`に反映する
(`docs/reports/step1-ds-twr-report.md` §2b)。アンカー側シリアルの`ignored=`は他アンカー宛Pollの
受信数で、4台構成では`ok`の約3倍になるのが正常。

## SS-TWR検証(Issue [#14](https://github.com/atinfinity/m5stamp_uwb_rtls/issues/14)、ss-twr-design.md §4/§6)

DS-TWRの対照試験として、**同じ設置・同じ距離**でenvをSSに替えて同手順を繰り返す:

```bash
cd firmware/anchor && pio run -e anchor_ss -t upload      # アンカーを SS 応答に
cd ../tag && pio run -e tag_step1_ss -t upload            # タグを SS 計測に
# capture.py / analyze.py は共通 (mode は CSV メタデータから自動判別)
uv run python tools/step1/analyze.py logs/ds_dist5m.csv logs/ss_dist5m.csv   # DS/SS を並べて比較
```

判定(3条件すべて満たしたらSS-TWRを予備方式として有効化):

| # | 条件 | 見方 |
|---|---|---|
| ① | σ ≤ 15 cm・バイアス ≤ 10 cm | **CFO補償の有無がここで判明**。補償なしならm級誤差が出て即不成立(ss-twr-design.md §2.2) |
| ② | 交換時間がDS比30% 以上短い | analyze.pyのp50を比較 |
| ③ | リプレイでCEP50 ≤ 30 cm維持 | Step 2以降のログで確認 |

- biasは方式ごとに異なりうるため、**DS/SS別々に校正値を記録**する
- 温度依存(始動直後vs 30分後)もss-twr-design.md §6の1. に従い両方式で採取する
- 不成立の場合は実測値をss-twr-design.mdに追記してIssue [#14](https://github.com/atinfinity/m5stamp_uwb_rtls/issues/14)をclose

## TDoA PoC(Issue [#16](https://github.com/atinfinity/m5stamp_uwb_rtls/issues/16)、tdoa-design.md §6)

将来方式TDoAのゲート条件を検証する。公開APIにRXタイムスタンプが無いため、
listener FWは同梱`qm33120w_sdk`の`dwt_readrxtimestamp()`を直叩きする
(40 bit、1 tick ≈ 15.65 ps、~17.2 sで周回)。

**PoC-1(2ノード): タイムスタンプ取得可否**

```bash
cd firmware/tdoa_poc
pio run -e blink_tx -t upload    # ノード1: 100ms 毎にブリンク送信 (addr 0x00F0)
pio run -e listener -t upload    # ノード2: 受信 + "src,seq,rx_ticks" を CSV 出力
```

判定: listenerの`rx_ticks`がブリンクごとに**単調増加**していれば取得成功
(増加しない/常に同値なら`receiveFrame()`実装がレジスタを上書きしており、ライブラリ改造が必要)。

**PoC-2(3ノード): 2アンカー無線同期**

blink_tx 1台 + listener 2台(それぞれPCにシリアル接続しCSVを採取)で:

```bash
uv run python tools/tdoa/sync_analysis.py anchorA.csv anchorB.csv
# → クロック offset/drift 推定と残留 σ。判定: σ < 2 ns (≈ 60 cm 相当, tdoa-design.md §6 の 2.)
# タグ模擬の blink_tx (addr を 0x0001 に変更) を追加した場合:
uv run python tools/tdoa/sync_analysis.py anchorA.csv anchorB.csv --tag-src 0x0001
```

解析ロジックは`--selftest`(合成クロック)で実機なしで検証済み。
結果は成立/不成立にかかわらず[tdoa-design.md](../docs/tdoa-design.md) §3に実測値を記録する。

## タグCSV出力仕様

```
seq,anchor,ok,d_mm,elapsed_ms,exchange_us,cycle_us,err
```

- `seq`: サイクル通し番号(複数アンカー巡回では同一サイクルの全行で共通)
- `anchor`: 相手アンカーのショートアドレス
- `exchange_us`: `requestDSRange()`呼出し全体の実測時間(ホストSPI処理込み)。スロット設計はこちらを使う
- `elapsed_ms`: ライブラリが報告する所要時間
- `cycle_us`: サイクル全体(全アンカー + ギャップ)の所要時間。サイクル最後のアンカー行にのみ入る
- `#`で始まる行はメタデータ/サマリ

旧形式(`seq,ok,d_mm,elapsed_ms,exchange_us,err`、1対1のみ)のCSVもanalyze.pyはそのまま読める。

## 実測レポートテンプレート

各検証の記録様式は[docs/reports/](../docs/reports/)にある(コピーして記入):
[Step 1 DS-TWR](../docs/reports/step1-ds-twr-report.md) /
[SS-TWR対照](../docs/reports/ss-twr-report.md) /
[TDoA PoC](../docs/reports/tdoa-poc-report.md)

## B案: タグ上計算(env:tagに統合, Issue [#28](https://github.com/atinfinity/m5stamp_uwb_rtls/issues/28))

本番モードのタグは`rtls/config/anchors`・`rtls/config/tuning`を受信すると
**タグ上解算(rtls_solver)とオンボードセル選択**が有効になる。設定はNVSに
永続化され、Wi-Fi断・再起動後も解算を継続する。設定未受信の間はranges送信のみ
(A案互換)で動作する。

**設定の配布** (サーバー側PCから):

```bash
uv run python tools/publish_config.py    # server/config.yaml → rtls/config/# へ retained 配布
```

**動作モード** (NVS永続。タグのUSBシリアルにコマンドを送って切替):

| コマンド | モード | 出力 |
|---|---|---|
| `mode HYBRID` | 既定 | ranges + positionをMQTT (A案サーバーと併用可、リプレイ資産も残る) |
| `mode QUIET` | 本番 | positionのみMQTT |
| `mode STANDALONE` | ロボット搭載 | UART (Serial1, 115200)へ30 byteバイナリフレームのみ(tag-design.md §7) |
| `status` | — | 現在のモード・設定バージョン・ソルバー状態を表示 |

- タグ側positionには`"src":"tag"`が付く(サーバー解算のpositionと区別)
- SNTP未同期時は500 ms周期のフリーランで測距する(単一タグ前提のフォールバック)
- UARTピンは`RTLS_UART_TX/RX`ビルドフラグで変更可

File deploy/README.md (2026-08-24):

# 常設デプロイ(Docker Compose)

MQTTブローカー(Mosquitto)と測位サーバー + Web UIを一括起動する。
Raspberry Pi等での常設運用を想定(server-design.md §2)。

```bash
cd deploy
docker compose up -d --build
```

- Web UI: http://localhost:8000
- MQTT: ホストの1883番(アンカー/タグ/仮想タグはここへ接続)
- 設定: `server/config.yaml`を読み取り専用でマウント(`mqtt.host`はコンテナ内で
  `--mqtt-host mosquitto`により自動上書き)。変更後は`docker compose restart server`
- 生距離ログ: named volume `rtls-logs`に日次JSONLで蓄積
  (`docker compose cp server:/app/logs ./logs-export`で取り出し)

動作確認(ホスト側から仮想タグを流す):

```bash
uv run python tools/virtual_tag.py     # localhost:1883 → コンテナ内サーバーが解算
```

停止: `docker compose down`(ログvolumeは保持。消す場合は`down -v`)

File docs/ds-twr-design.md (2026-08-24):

# DS-TWR測距方式詳細設計書

- 作成日: 2026-08-15
- ステータス: ドラフト(実装前レビュー用)
- 上位文書: [rtls-design.md](rtls-design.md) §2(**採用方式**)
- 関連文書: [ss-twr-design.md](ss-twr-design.md)(予備方式)、[tdoa-design.md](tdoa-design.md)(将来方式)

## 1. 位置づけ

DS-TWR(Double-Sided Two-Way Ranging)は本システムの**標準測距方式**。本書はその原理、公式ライブラリでの実装仕様、タイミング設計、誤差予算を定める。

## 2. 測距原理

### 2.1 メッセージ交換(4メッセージ方式: Poll / Response / Final / Result)

```mermaid
sequenceDiagram
    participant T as タグ (Initiator)
    participant A as アンカー (Responder)
    Note over T: t1: Poll 送信
    T->>A: ① Poll
    Note over A: t2: Poll 受信
    Note over A: t3: Response 送信(遅延 T_reply1)
    A->>T: ② Response
    Note over T: t4: Response 受信
    Note over T: t5: Final 送信(遅延 T_reply2)
    T->>A: ③ Final(t1, t4, t5 を搭載)
    Note over A: t6: Final 受信
    Note over A: 全タイムスタンプが揃い ToF → 距離を計算
    A->>T: ④ Result(距離 mm を搭載)
    Note over T: Result 受信で requestDSRange() が返る
```

ToFの計算は**アンカー側**で行い、距離はResultフレームでタグへ返す。公式ライブラリの`requestDSRange()`はResultを受信して初めて成功を返すため、1交換の所要時間・エアタイムにはResultの送受信も含まれる(§3.3の`resultRxAfterFinalTxDelayUus`、`resultRepeatCount`)。

### 2.2 ToF計算式

タグ側往復`T_round1 = t4 − t1`、アンカー側応答遅延`T_reply1 = t3 − t2`、アンカー側往復`T_round2 = t6 − t3`、タグ側応答遅延`T_reply2 = t5 − t4`として:

```
ToF = (T_round1 × T_round2 − T_reply1 × T_reply2)
      ─────────────────────────────────────────────
      (T_round1 + T_round2 + T_reply1 + T_reply2)

距離 d = c × ToF   (c = 299,792,458 m/s。1 ns ≈ 30 cm)
```

この計算はアンカーが行い(t1, t4, t5はFinalで受け取る)、得られた距離をResultでタグへ通知する。

### 2.3 クロックドリフト誤差の相殺(DS-TWRを採用する理由)

タグ・アンカーの水晶に周波数偏差e_T, e_A(各 ±20 ppm程度)があっても、上式は**両側の往復を掛け合わせる対称形**のため、1次のドリフト誤差が相殺される。残留誤差は近似的に

```
err ≈ ToF × (e_T + e_A) / 2      (例: ToF 100 ns × 40 ppm / 2 = 2 ps → 距離換算 ≈ 0.6 mm)
```

と無視できる。SS-TWRと違って応答遅延T_replyにドリフトが乗らないため、**µs級のホスト処理遅延があっても精度が保たれる**。これがホストMCU(Arduinoループ)経由で制御する本構成にDS-TWRが適する本質的な理由である。

## 3. ライブラリ実装仕様

### 3.1 使用API

| 役割 | API | 備考 |
|---|---|---|
| タグ | `requestDSRange(M5Stamp_UWBDSRangeConfig)` → `M5Stamp_UWBDSRangeResult` | ブロッキング呼出し(Poll送信 → Result受信まで)。結果に距離(mm/m、Resultフレーム経由)・シーケンス番号・成否 |
| アンカー | `respondDSRange(M5Stamp_UWBDSRangeConfig)` → `M5Stamp_UWBDSResponderResult` | ループで呼び続け、自局宛Pollに応答。ToF計算とResult送信まで担当し、結果にも距離が入る |

### 3.2 フレーム・アドレス設定

- PAN ID `0xDECA`、アドレス体系は基本設計 §4.2(アンカー`0x0010`〜、タグ`0x0001`〜)。
- タグは測距のたびに`DSRangeConfig`の相手アドレスを巡回リストの次のアンカーに差し替えて`requestDSRange()`を呼ぶ(基本設計 §4.4)。
- PHY設定は既定(Channel 9、BPRF)。全ノードで統一し、変更時は全ノード一斉更新とする。

### 3.3 タイミングパラメータ(公式サンプル準拠 → Step 1実測で確定)

| パラメータ(ライブラリ設定名 / 本プロジェクトの定数名) | 初期値 | 説明 |
|---|---|---|
| `responseTxDelayUus` / `kDsResponseTxDelayUus`(アンカー) | 3000 µs | Poll受信 → Response送信の遅延。ホストSPI往復を吸収できる下限を実測で探る(サンプルは1500〜3000 µs) |
| `finalTxDelayUus` / `kDsFinalTxDelayUus`(タグ) | 1800 µs | Response受信 → Final送信の遅延 |
| `rxTimeoutUus` / `kDsRxTimeoutUus` | 3000 µs | 各受信待ちの上限 |
| `hostTimeoutMs` / `kDsHostTimeoutMs` | 100 ms | `requestDSRange()`全体の上限 |
| `resultRxAfterFinalTxDelayUus` / `kDsResultRxAfterFinalTxDelayUus`(タグ) | 500 µs | Final送信 → Result受信待ち開始までの遅延 |
| `resultRepeatCount` / `kDsResultRepeatCount`(アンカー) | 1 回 | アンカー→タグのResultフレーム再送回数。ライブラリ既定は3だが、タグは最初のResultで次アンカーのPollへ移るため余分な再送は次の交換と衝突する。公式`DS_TWR_MULTI_ANCHOR`例に合わせて1 |
| `resultRepeatGapMs` / `kDsResultRepeatGapMs` | 3 ms | Result再送間隔(再送1回では未使用) |
| — / `kDsInterAnchorGapMs`(タグ) | 2 ms | 巡回中のアンカー切替ギャップ。前アンカーがTX→RXに戻る猶予(公式例は20 ms。4台 × 20 msではスロット予算を超えるため、Step 1で最小値を実測) |
| 1交換の所要時間(見込み) | 5〜10 ms | ロードマップStep 1で実測し、TDMAスロット設計(基本設計 §4.4)を確定する |

現在の確定値は`firmware/lib/rtls_common/rtls_common.h`の`kDs*`定数を正とする(この定数がライブラリ設定の各フィールドへ代入される)。

**遅延パラメータの方針**: 短くするほどエアタイムは減るが、ホスト(Arduinoループ+SPI)の応答ジッタでタイムアウト率が上がる。Step 1で「成功率99% を保てる最小値」を求め、`rtls_common`の共有ヘッダに定数として固定する。

### 3.4 リトライとエラー処理

- 1アンカーにつき失敗時リトライ1回(乱数バックオフ1〜5 ms)。それでも失敗なら当該サイクルは欠測(基本設計 §4.4)。
- アンカー側の`RangeFrameMismatch`は「他アンカー宛のPollを受信した」事象で、多アンカー環境では毎サイクル発生する正常動作。統計では`ignored`として`err`と区別する(公式`DS_TWR_MULTI_ANCHOR`例と同じ扱い)。
- `lastError()`の種別(タイムアウト / CRC / チップ異常)をタグの統計に集計し、MQTT統計(A案 §12)へ流す。チップ異常が連続する場合は`hardReset()` → `begin()`で復帰を試みる。

## 4. 誤差予算と対策

| 誤差要因 | 大きさ(目安) | 対策 |
|---|---|---|
| 測距ノイズ(LoS) | σ ≈ 5〜10 cm(仕様誤差0.14 m) | カルマンフィルタで平滑化(server-design.md §5) |
| アンテナ遅延オフセット | 数十cm(個体差) | ノード別`bias_mm`校正(基本設計 §6) |
| クロックドリフト | < 1 mm(§2.3で相殺) | 対策不要 — DS-TWRの利点 |
| NLoS(遮蔽・マルチパス) | +0.3〜数m(伸びる方向) | 残差ベース外れ値除去 + ゲーティング(server-design.md §5) |
| 温度による遅延変動 | 数cm | 定期再校正(季節単位)で十分 |
| アンカー座標誤差 | 設置測量に依存 | ±3 cm以内で測量(基本設計 §3.3) |

## 5. TDMAとの統合

基本設計 §4.4のスロット(90 ms)内で4アンカー × (1交換 + リトライ)を実行する。本方式固有の考慮:

- **交換中の割込み耐性**: DS-TWRは4メッセージが揃って1測距。他タグの電波はアドレス不一致で無視されるが、交換中の衝突はFinalまたはResultの喪失として現れる。リトライで吸収し、スロット同期(±10 ms、基本設計 §4.9)で衝突自体を稀にする。
- **アンカー側は常時`respondDSRange()`ループ**であり、どのタグのPollにも(自局宛なら)応答する。アンカーにスロットの概念は不要 — タグ側の規律だけでTDMAが成立する。

## 6. テスト計画(ロードマップStep 1に対応)

1. **静的精度**: 既知距離1 / 5 / 10 / 20 / 40 m(LoS)で各1000回測距。平均誤差(→ bias校正値)と σ を記録。受入: 校正後 |平均誤差| ≤ 5 cm、σ ≤ 10 cm。
2. **タイミング実測**: 1交換の所要時間分布(p50/p95/p99)と、`response_delay`を3000 → 1500 µsへ詰めた際の成功率変化。TDMAスロット幅の根拠データとする。
3. **成功率vs距離**: 5 m刻みで成功率を測り、実効レンジ(成功率95% を保てる距離)を求める。セル寸法(15〜25 m)の妥当性を確認。
4. **干渉試験**: 2タグが同時に同一アンカーへPollする最悪ケースを意図的に作り、失敗がタイムアウトとして安全に現れる(誤距離が出ない)ことを確認。
5. **アンカー間ギャップ**: アンカー4台を巡回し、`kDsInterAnchorGapMs` を 0 / 2 / 5 / 20 msで振って成功率とサイクル時間(p95)を測る(`tag_step1`の`TARGET_ANCHORS`指定)。成功率を落とさない最小値を採用し、4アンカー分のサイクルp95がスロット有効幅90 msに収まることを確認する。

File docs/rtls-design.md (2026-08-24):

# M5Stamp UWB屋内RTLS測位システム設計書

- 作成日: 2026-08-15
- ステータス: ドラフト(実装前レビュー用)

## 1. システム概要

M5Stack Stamp UWB(Qorvo QM33120W搭載)を用いて、屋内フロア(20〜50 m規模)で移動タグの2D位置をリアルタイムに推定するRTLS(Real-Time Locating System)を構築する。

### 要件

| 項目 | 目標値 |
|---|---|
| 測位エリア | 屋内20〜50 m四方(単一フロア、2D) |
| タグ数 | 2〜5台(同時測位) |
| 測位精度 | 実用30 cm程度(見通し時。DS-TWRの測距誤差は約0.14 m) |
| 更新レート | タグあたり1〜2 Hz(初期目標。チューニングで向上余地あり) |
| アンカー数 | 8〜12台(セル分割、1セルあたり4台を標準。解算の下限は3台) |
| 出力 | 各タグの(x, y)座標。PC上でリアルタイム可視化 |

### 前提となる調査結果

- Stamp UWBは**SPI接続の測距モジュールで単体動作不可**。ホストMCUが必須で、公式ライブラリ([m5stack/M5Stamp-UWB](https://github.com/m5stack/M5Stamp-UWB))のデフォルトホストはM5Stamp C5(ESP32-C5)。
- 公式ライブラリはArduino用で、提供サンプルは**SS-TWR / DS-TWRの1対1測距**(`SS_TWR_TAG/ANCHOR`, `DS_TWR_TAG/ANCHOR`)と、**1タグ × Nアンカーの巡回DS-TWR**(`DS_TWR_MULTI_ANCHOR` / `DS_TWR_MULTI_ANCHOR_TAG`、2026-08-24追加)。巡回測距の作法(Result再送1回・アンカー間ギャップ)はこれに倣う(ds-twr-design.md §3.3)。マルチタグのTDMAスケジューリング・セル管理・測位解算・TDoAは**未提供のため本設計で自作**する。
- 主要API: `requestRange()` / `respondRange()`(SS-TWR)、`requestDSRange()` / `respondDSRange()`(DS-TWR)。測距コンフィグでPAN ID・自局/相手局ショートアドレスを指定でき、結果構造体から距離(mm/m)・シーケンス番号・成否を取得できる。→ **相手アドレスを切り替えながら複数アンカーへ順次測距する方式が素直に実装可能**。
- 仕様(公式ドキュメント): UWB Channel 9(中心7987.2 MHz)、IEEE 802.15.4-2020 / 802.15.4z-2020 BPRF、DS-TWR測距誤差約0.14 m、見通し最大約55 m、データレート850 kbps / 6.81 Mbps。

## 2. 測位方式の選定

**採用: DS-TWR(Double-Sided Two-Way Ranging)+ 最小二乗マルチラテレーション(三辺測量)**

| 方式 | 概要 | 判定 | 理由 |
|---|---|---|---|
| **DS-TWR** | タグ⇔アンカー間で往復2回のメッセージ交換によりToFを測定 | ✅ 採用 | クロックドリフトの影響を相殺でき精度が高い(~0.14 m)。公式サンプルあり。アンカー間の時刻同期不要 |
| SS-TWR | 往復1回の簡易版 | △ 予備 | エアタイムは短いがクロックオフセットの影響で精度が落ちる。エアタイム逼迫時の代替として温存 |
| TDoA | タグは1回ブリンク送信、複数アンカーの受信時刻差から測位 | ❌ 不採用 | タグ側は省電力・多タグに強いが、**アンカー間のナノ秒級クロック同期(有線同期または無線同期プロトコル)が必要**で、公式ライブラリに機能がなく開発規模が跳ね上がる。タグ2〜5台ならTWRで十分 |

タグ主導で各アンカーに順次DS-TWRを行い、得られた距離セット {d₁…dₙ} から2D座標を最小二乗法で解く。

→ 方式別の詳細設計: **[ds-twr-design.md](ds-twr-design.md)**(採用)/ **[ss-twr-design.md](ss-twr-design.md)**(予備・切替条件)/ **[tdoa-design.md](tdoa-design.md)**(将来・実現条件)

## 3. ハードウェア構成

### 3.1 ノード構成(アンカー・タグ共通の基本ユニット)

**M5Stamp C5 + M5Stamp UWB F(FPC版)を付属の0.5mm-12P FPCケーブルで直結**する。

- Stamp C5の背面FPCコネクタ(G23, G0, G24, G25, G26, G27, G11, G12)と、公式サンプルのピン割当(SCK=G12, MISO=G26, MOSI=G27, CS=G11, RST=G25, IRQ=G0, WAKEUP=G24, GP7=G23)が一致しており、**はんだ付け不要で公式サンプルがそのまま動く、メーカー想定の組み合わせ**。
- 無印版Stamp UWB(キャスタレーション実装)は量産・独自基板化フェーズ向け。プロトタイプではFPC版を推奨。

**接続関係図:**

```mermaid
flowchart LR
    subgraph tagnode["タグノード ×2〜5"]
        LIPO["LiPo 3.7V<br/>500〜1000 mAh"]
        C5T["M5Stamp C5<br/>(ESP32-C5)"]
        UWBT["Stamp UWB F<br/>(QM33120W)"]
        LIPO -- "BAT 端子<br/>(SGM40567 充電IC 内蔵)" --> C5T
        C5T <-- "0.5mm-12P FPC ケーブル<br/>SPI: SCK=G12, MISO=G26,<br/>MOSI=G27, CS=G11<br/>制御: RST=G25, IRQ=G0" --> UWBT
    end
    subgraph anchornode["アンカーノード ×8〜12"]
        AC["USB AC アダプタ /<br/>モバイルバッテリー"]
        C5A["M5Stamp C5<br/>(ESP32-C5)"]
        UWBA["Stamp UWB F<br/>(QM33120W)"]
        AC -- "USB Type-C 5V" --> C5A
        C5A <-- "0.5mm-12P FPC ケーブル<br/>(ピン割当はタグと同一)" --> UWBA
    end
    UWBT <-. "UWB Ch9 7.9872 GHz<br/>DS-TWR 測距" .-> UWBA
    C5T -. "Wi-Fi 2.4/5 GHz<br/>(MQTT テレメトリ)" .-> AP["Wi-Fi AP"]
    AP --- PC["PC(測位サーバー)<br/>Mosquitto + Python 解算/可視化"]
```

FPCケーブル1本でSPI 5線+制御2線+電源がまとまるため、ノード側の配線作業は「FPCを挿すだけ」。アンカーはWi-Fi接続不要(§4.3)なので、給電とUWB応答のみのスタンドアロン動作。

| 役割 | 構成 | 電源 |
|---|---|---|
| アンカー(8〜12台) | Stamp C5 + Stamp UWB F | USB Type-C給電(USB ACアダプタまたはモバイルバッテリー常時給電) |
| タグ(2〜5台) | Stamp C5 + Stamp UWB F | 3.7 V LiPoバッテリー(Stamp C5はSGM40567充電IC内蔵、電池端子あり) |
| サーバー | PC 1台(常設ならRaspberry Piでも可) | — |
| ネットワーク | 2.4/5 GHz Wi-Fi AP(既設流用可) | — |

### 3.2 BOM(概算)

| 品目 | 単価(USD) | 数量 | 小計 |
|---|---|---|---|
| M5Stamp UWB F(FPCケーブル付属) | $24.50 | 13〜17 | $319〜417 |
| M5StampC5 | $6.50 | 13〜17 | $85〜111 |
| タグ用LiPoバッテリー(3.7 V 500〜1000 mAh) | ~$5 | 2〜5 | ~$25 |
| タグ用ケース、アンカー取付具(3Dプリント等) | — | 一式 | ~$50 |
| USB ACアダプタ+ケーブル(アンカー用) | ~$5 | 8〜12 | ~$60 |
| **合計** | | | **約 $540〜660** |

数量 = アンカー8〜12 + タグ2〜5。予備を1〜2セット追加推奨。校正用にレーザー距離計(アンカー座標の測量に使用)があると良い。

### 3.3 アンカー配置設計

50×50 mを一度にカバーせず、**15〜25 m四方のセルに分割**し、セルごとに4台のアンカーを矩形の四隅に配置する。隣接セルとはアンカーを共有(辺上のアンカーは両セルに属する)。

```
50m フロアの例(●=アンカー、9台で4セル):
●----------●----------●
|  セル A   |  セル B   |
|          |          |
●----------●----------●
|  セル C   |  セル D   |
|          |          |
●----------●----------●
```

配置の指針:

- **高さ1.8〜2.5 m**に統一して壁面・柱に設置(人体・什器による遮蔽を減らす)。2D測位ではアンカー高さとタグ高さの差が水平距離誤差になるため、タグの想定高さ(例: 人の腰 ~1.0 m)との高低差補正を解算時に行う(√(d² − Δz²)で水平距離化)。
- タグから見て**アンカーが一方向に偏らない**こと(DOP悪化を防ぐ)。セル内のどこでも4台への見通しが確保できる位置を選ぶ。
- **アンテナ部を遮らない**: 公式ドキュメントの要求どおり、アンテナ端が金属・壁から離れるよう突き出して取り付ける。金属板への直付けは禁止。
- 各アンカーの設置座標はレーザー距離計で測量し、±3 cm以内でサーバーの設定ファイルに登録する(アンカー座標誤差はそのまま測位誤差になる)。

### 3.4 電波環境

- UWB Channel 9(7.9872 GHz)とWi-Fi(2.4/5 GHz)は周波数帯が離れており干渉しない。テレメトリに5 GHz Wi-Fi(ESP32-C5はWi-Fi 6対応)を使えば2.4 GHzの混雑も回避できる。
- **日本国内での利用**: UWB 7.25〜9.0 GHz帯は干渉回避機能なしで屋内利用可能な帯域でありCh9はこの範囲内。ただし**本製品は2026-08-14リリース直後のため、技適(工事設計認証)の取得状況を購入前に必ず確認すること**(未取得の場合、実験目的でも「技適未取得機器の実験等特例制度」の届出が必要)。

## 4. ソフトウェア構成

### 4.1 全体アーキテクチャ

```mermaid
flowchart TB
    subgraph floor["フロア(UWB Channel 9)"]
        TAG["タグ FW ×2〜5<br/>Stamp C5 + UWB F"]
        A1["アンカー FW ×8〜12<br/>Stamp C5 + UWB F<br/>(応答専用・座標を持たない)"]
    end
    TAG <-- "DS-TWR 測距<br/>(担当セルの4台へ順次)" --> A1
    TAG -- "Wi-Fi / MQTT publish<br/>rtls/tag/{id}/ranges" --> BR["MQTT ブローカー<br/>(Mosquitto)"]
    BR -- "アンカーリスト配信 (retained)<br/>rtls/tag/{id}/anchors" --> TAG
    subgraph server["測位サーバー(Python)"]
        ENG["解算エンジン<br/>高低差補正 → 外れ値除去<br/>→ 最小二乗測位 → カルマンフィルタ"]
        CFG["config.yaml<br/>アンカー座標・セル・タグ定義"]
        VIZ["可視化サーバー<br/>FastAPI + WebSocket"]
    end
    BR -- "subscribe" --> ENG
    CFG --> ENG
    ENG -- "rtls/tag/{id}/position" --> BR
    ENG --> VIZ
    VIZ --> UI["ブラウザ<br/>フロアマップ / 軌跡 / 測位品質"]
```

リポジトリ構成(現状の全体像は[development.md](development.md) §6を参照):

```
m5stamp_uwb_rtls/
├── docs/rtls-design.md          # 本書
├── firmware/
│   ├── anchor/  tag/            # アンカー / タグ FW (PlatformIO)
│   ├── lib/rtls_common/         # アドレス表・スロット定義の共有ヘッダ
│   └── lib/rtls_solver/         # B案 C++ ソルバー (tag-design.md)
├── server/
│   ├── positioning/             # 解算エンジン (numpy/scipy)
│   ├── web/                     # Web ダッシュボード (FastAPI + Canvas UI)
│   └── config.yaml              # アンカー座標・セル・タグ定義
└── tools/                       # シミュレータ・仮想タグ・Step 1 計測ツール
```

開発環境はPlatformIO(Arduinoフレームワーク、`board = esp32-c5`系)+ 公式M5Stamp-UWBライブラリ。

### 4.2 アドレス体系

| 種別 | 値 |
|---|---|
| PAN ID | 0xDECA(全ノード共通) |
| アンカー | 0x0010〜0x001B(最大12台。下位4 bit = アンカー番号) |
| タグ | 0x0001〜0x0005 |

アドレスと設置座標の対応はサーバーの`config.yaml`で一元管理。FWにはアドレスのみ書き込む(ビルドフラグ`-DNODE_ADDR=0x0011`で個体差し替え)。

### 4.3 アンカーFW

役割は「自分宛の測距要求に応答するだけ」。座標も状態も持たない、最も単純なノード。

- `begin()`後、ループで`respondDSRange()`を呼び続ける(自局アドレス宛のDS-TWR要求に応答)。
- Wi-Fiは不要(オプションで死活監視用にMQTTへheartbeatをpublishしても良い)。
- 公式`DS_TWR_ANCHOR`サンプルがほぼそのまま流用できる。

### 4.4 タグFWとマルチタグTDMAスケジューリング

タグは「スロットが来たら、担当セルのアンカー4台へ順次DS-TWR → 距離セットをMQTTでpublish」を繰り返す。

**TDMAスーパーフレーム設計(タグ5台・更新2 Hz):**

```
スーパーフレーム 500 ms
├─ スロット1 (0〜90ms)    : タグ 0x0001 が測距
├─ スロット2 (100〜190ms) : タグ 0x0002 が測距
├─ ...
└─ スロット5 (400〜490ms) : タグ 0x0005 が測距
     各スロット内: アンカー4台 × (DS-TWR 1回 ≈ 5〜10 ms + 失敗時リトライ1回) + アンカー間ギャップ 3 × 2 ms
     スロット間ガードタイム 10 ms
```

- **時刻同期**: ナノ秒精度は不要(UWBの測距自体は同期不要)。スロット境界を守れる**±10 ms程度**で十分なので、タグはWi-Fi経由の**SNTP同期**を使い、`(現在時刻ms) mod 500`で自スロットを判定する。ESP32のSNTPはLAN内なら数ms精度が出るため成立する。同期方式の選定と運用設計は **§4.9**に定める。
- **フォールバック**: スロット外でアンカーが別タグに応答中でも、DS-TWRはアドレス指定型なので混信は「タイムアウト」として現れるだけ。タイムアウト時は乱数バックオフ後に1回だけリトライし、それでも失敗したアンカーは当該サイクルでは欠測扱いにする(3距離あれば解算可能)。
- タグ2〜3台で運用する場合はスロットを150〜200 msに広げ、更新レートを上げられる。

**アンカー選択ロジック(セル対応):**

1. タグはサーバーから現在の担当アンカーリスト(4〜6台)をMQTTのretainedメッセージで受け取る(`rtls/tag/<id>/anchors`)。
2. 通常はリスト先頭4台に測距。あるアンカーの連続失敗数が閾値(例: 5回)を超えたら、リスト内の予備アンカーに入れ替える。
3. **セルのハンドオーバーはサーバー主導**: 解算した位置がセル境界に近づいたら、サーバーが隣接セルのアンカーリストを配信し直す。タグ側は受信したリストに従うだけにして、FWのロジックを薄く保つ。

### 4.5 測位アルゴリズム(サーバー側解算エンジン)

1. **高低差補正**: 斜距離dを水平距離 √(d² − Δz²)に変換(Δz = アンカー高 − タグ想定高)。
2. **外れ値除去**: NLoS(遮蔽)による距離の**伸び**が主誤差。前回位置から物理的にあり得ない距離(移動速度上限超え)や、最小二乗の残差が大きい距離を除外して再解算する(4距離中1つ除外しても3距離で解ける)。
3. **最小二乗マルチラテレーション**: 距離方程式を線形化して`numpy.linalg.lstsq`、または`scipy.optimize.least_squares`で非線形解法。3距離以上で解算、2距離以下のサイクルは欠測としてフィルタの予測値で補間。
4. **平滑化**: 等速直線運動モデルの**2Dカルマンフィルタ**(状態[x, y, vx, vy])。実装を軽くしたい初期段階は指数移動平均でも可。

### 4.6 テレメトリ伝送方式の選定(MQTTと代替案)

タグ→サーバーの距離データ伝送と、サーバー→タグのアンカーリスト配信(下り)には以下の選択肢がある。

| 方式 | 仕組み | 長所 | 短所 | 向くケース |
|---|---|---|---|---|
| **MQTT** ✅ 採用 | ブローカー経由のpub/sub | 下り配信がretainedメッセージで自然に書ける。ロガー・可視化など**購読者を後から追加**できる。ESP32実績豊富(PubSubClient / esp-mqtt) | ブローカー(Mosquitto)を1プロセス常駐させる必要 | 本システムの標準構成 |
| WebSocket直結 | タグ→FastAPIへ常時接続 | ブローカー不要でサーバー1プロセスに集約。双方向なので下り配信も可 | 再接続・複数購読者・メッセージ保持をすべて自作。データ記録も自前 | 構成要素を極小化したい小規模構成 |
| HTTP POST | 測距サイクルごとにRESTで送信 | 最も単純。デバッグがcurlで済む | **下り(アンカーリスト)がポーリングになる**。接続オーバーヘッドが毎回かかる | 下り不要な1セル・固定アンカー構成 |
| 生UDP | JSON/バイナリをUDP datagramで送信 | 最軽量・最低遅延。欠測を許容する測距データと相性が良い | 到達保証なし。下り経路・タグ死活管理を自作。将来のNAT越え不可 | 更新レート最優先のチューニング段階 |
| ESP-NOW + ブリッジ | タグ→受信専用ESP32(PCにUSBシリアル接続)へWi-Fi APなしで直送 | **Wi-Fiインフラ不要**。接続確立が不要で低遅延・低電力 | ブリッジノードの製作が必要。50m級では中継配置の検討も必要。下り配信も自作 | 会場にWi-Fiを用意できない現場 |
| UWBバックホール | ライブラリの`sendFrame()`/`receiveFrame()`で距離データをUWBフレーム送信し、PC接続のリスナーノードで回収 | タグからWi-Fiを排除でき省電力。無線がUWBのみで完結 | **測距用エアタイムを圧迫**しTDMA設計が複雑化。リスナー+シリアルブリッジ自作。帯域小 | タグ電池持ちが最優先で更新レートを落とせる場合 |
| BLE | タグ→BLEゲートウェイ | 省電力 | 50mフロアでは到達距離・ローミングが厳しく、ゲートウェイ多数が必要 | ❌ 本用途には不適 |

**MQTTを採用する決め手**は、(1)セルハンドオーバーに必須の下り配信(§4.4)がretainedメッセージでそのまま実現できること、(2)生距離の記録・再解析(§5 A案の利点)が「ロガーを1購読者追加」で済むこと。代替として有力なのは、ブローカーも省きたい小規模構成での**WebSocket直結**と、Wi-Fiインフラが用意できない現場での**ESP-NOW + シリアルブリッジ**。いずれもタグFWの送信層を差し替えるだけで移行できるよう、FW内では「距離セットの生成」と「送信」を分離しておく。

### 4.7 MQTTトピック・メッセージ設計

| トピック | 方向 | 内容 |
|---|---|---|
| `rtls/tag/<id>/ranges` | タグ → サーバー | 1サイクル分の距離セット |
| `rtls/tag/<id>/anchors` | サーバー → タグ(retained) | 担当アンカーリスト |
| `rtls/tag/<id>/position` | サーバー → 可視化/外部 | 解算済み座標 |
| `rtls/anchor/<id>/status` | アンカー → サーバー | heartbeat(オプション) |

`ranges`ペイロード例:

```json
{"tag":"0x0001","seq":1234,"t_ms":1755212345678,
 "ranges":[{"a":"0x0010","d_mm":5234,"ok":true},
           {"a":"0x0011","d_mm":7810,"ok":true},
           {"a":"0x0012","d_mm":3120,"ok":true},
           {"a":"0x0013","d_mm":0,"ok":false}]}
```

`position`ペイロード例:

```json
{"tag":"0x0001","t_ms":1755212345690,"x_m":12.34,"y_m":8.76,
 "quality":{"n_anchors":3,"residual_m":0.08},"cell":"A"}
```

### 4.8 可視化

PythonサーバーにFastAPI + WebSocketを同居させ、ブラウザでフロア図(SVG/Canvas)上にタグをリアルタイム描画する。開発初期はmatplotlibのライブプロットでも十分。表示項目: タグ位置と軌跡、使用アンカー、残差(測位品質)、欠測アンカーの警告。

### 4.9 時刻同期設計

**要件整理** — 必要な精度は用途で大きく異なる:

| 用途 | 必要精度 | 備考 |
|---|---|---|
| UWB測距そのもの(DS-TWR) | **同期不要** | 往復時間差で解くため。DS-TWRを選んだ利点そのもの |
| TDMAスロット境界の遵守 | ±10 ms程度 | ガードタイム10 msを守れればよい |
| 測距データのタイムスタンプ(カルマンdt、鮮度判定、タグ間整合) | ~10 ms | 歩行2 m/s × 10 ms = 2 cmで、測距誤差0.14 mに対し十分小さい |

**ナノ秒級の同期は一切不要で、ms級で足りる。** その前提での方式比較:

| 方式 | 精度 | 判定 | 理由 |
|---|---|---|---|
| **SNTP(LAN内NTPサーバー)** | LAN内1〜5 ms | ✅ 採用 | 測位サーバーのホストにchronyを立て、タグはそこへ同期。ESP32標準機能で実装コストほぼゼロ |
| サーバー受信時刻で代用(`recv_ms`) | 10〜100 ms | ❌ | タグ側同期が不要になる代わりにWi-Fi+ブローカーのジッタがそのまま時刻誤差になり、dtが乱れカルマンに悪影響。スロット判定にも使えない |
| Wi-Fi TSF(同一APのビーコン時刻) | µs級 | △ 将来枠 | `esp_wifi_get_tsf_time()`で同一AP配下のタグが µs級共有クロックを持てる。スロット精度を詰めたくなった時のアップグレード。日時そのもの(壁時計時刻)は得られないためSNTPと併用になる |
| PTP(IEEE 1588) | sub-µs | ❌ | ハードウェアタイムスタンプはEthernet前提で、Wi-Fi接続のESP32-C5では精度が出ず過剰 |
| UWBフレーム同期(アンカービーコン基準) | ns級 | ❌ | TDoAへ移行する場合に初めて必要。TWR構成では不要 |

**採用設計(SNTPを軸に3点):**

1. **測位サーバーのホストにchronyを同居**させ、タグはLAN内でそこへ同期する。インターネットNTPには出さない(精度もオフライン耐性もLAN完結が上)。
2. **再同期は5分毎、補正は時刻を一気に合わせるステップ補正ではなく徐々に合わせるスルー補正(slew)** とする。5分毎にするのは、ESP32の水晶が ±20 ppm程度あり、15分放置すると最大 ~18 msドリフトして ±10 msのスロット予算を食い潰すため(5分なら最大 ~6 ms。前回同期とのずれからドリフト率を一次推定して補正すれば ~2 msに抑えられる)。ステップ補正を避けるのは、時刻が飛ぶとスロット判定`(t mod 500)`が瞬間的に他タグのスロットへ跳ぶため。
3. **サーバー側で`recv_ms − t_ms`の分布を常時監視**し(server-design.md §12)、特定タグだけ分布が偏ったら同期異常としてUIに警告する。同期の監視まで含めて運用設計とする。

## 5. 測位計算の配置: サーバー計算vsタグ上計算

| 観点 | A案: サーバー計算(タグは距離のみ送信) | B案: タグ上計算(座標を送信) |
|---|---|---|
| アルゴリズム改善 | ◎ Pythonで外れ値除去・フィルタを再起動なしに試行錯誤できる。**生距離ログが残るため後からアルゴリズムを差し替えて再解析可能** | △ FW書き換え+全タグへのOTA/書き込みが毎回必要 |
| デバッグ性 | ◎ 距離の生値・残差・除外判定をすべて観測できる | △ 座標しか見えず、誤差の原因(どのアンカーの距離が狂ったか)を追えない |
| レイテンシ | ○ Wi-Fi+ブローカー経由で +10〜50 ms(可視化用途では無視できる) | ◎ タグ内で完結 |
| タグ消費電力 | ○ どちらもWi-Fi送信は必要。ペイロード差は誤差レベル | ○ 解算の計算負荷はESP32-C5には軽微 |
| スタンドアロン性 | △ サーバー必須 | ◎ タグ単体で自位置を利用可(ロボット搭載など) |
| セル管理・マルチタグ協調 | ◎ アンカーリスト配信・ハンドオーバーと同じ場所に集約できる | △ 全アンカー座標を各タグに配布・更新する仕組みが別途必要 |
| スケーラビリティ | ◎ タグ追加はサーバー設定のみ | △ タグごとに設定書き込み |

**推奨: A案(サーバー計算)。** 本システムの難所は解算アルゴリズムのチューニング(NLoS対策・フィルタ)であり、そこをPython側に置けるA案は開発効率で圧倒的に有利になる。中規模エリアで必須になるセル管理・ハンドオーバーもサーバー主導設計(§4.4)と整合する。B案はタグが自律移動体(ロボット)に載り、タグ自身が座標を必要とする場合の将来拡張として位置づける。その場合も「距離は必ずMQTTにも流す」設計にしておけば移行できる。

→ **A案の詳細設計は[server-design.md](server-design.md)、B案の詳細設計は[tag-design.md](tag-design.md)を参照。**

## 6. キャリブレーションと精度対策

1. **アンテナ遅延校正**: 既知距離(例: 正確に5.000 m)にタグ・アンカーを置いて多数回測距し、オフセット(実測 − 真値)をノードごとに求める。QM33120Wのアンテナ遅延レジスタで補正するか、簡易にはサーバー側でノード別バイアス表(`config.yaml`)として引き算する。全アンカー×代表タグの組で実施。
2. **アンカー座標測量**: レーザー距離計で基準点からの距離を測り座標化。±3 cm目標。
3. **NLoS対策**: 人体・金属什器による遮蔽では距離が**伸びる**方向に誤差が出る。§4.5の残差ベース外れ値除去に加え、恒常的に遮蔽されるエリアがあればアンカー増設・位置変更で対処。
4. **静的テスト → 動的テスト**: 既知座標のグリッド上にタグを静置して誤差マップを作成(受入基準: 見通し環境でCEP50 ≤ 30 cm)、その後歩行試験で軌跡の滑らかさとハンドオーバーを確認。

## 7. リスクと制約

| リスク | 影響 | 対策 |
|---|---|---|
| **技適未取得の可能性**(2026-08-14発売直後) | 日本国内で電波を出せない | 購入前に技適番号を確認。未取得なら特例制度の届出を行い実験室内で使用 |
| 公式ライブラリが新しく実績が薄い | API変更・不具合 | バージョンを固定(library.jsonのタグ指定)。1対1測距の動作検証を最初のマイルストーンにする |
| DS-TWRのエアタイム逼迫(タグ・アンカー増加時) | 更新レート低下 | 本設計の上限はタグ5台×2 Hz程度。それ以上はスロット延長で更新レートを犠牲にするか、TDoA化(大規模改修)を検討 |
| SNTP同期のずれによるスロット衝突 | 測距失敗率上昇 | ガードタイム10 ms+乱数バックオフリトライで吸収。失敗率をサーバーで監視 |
| NLoSが多い環境(棚・金属壁) | 精度劣化 | アンカー密度を上げる(セルを小さくする)。誤差マップで問題エリアを特定 |
| タグの電池持ち | 運用性 | DS-TWR+Wi-Fi常時接続では実測が必要。短ければ測距間隔の動的調整(静止検出でレート低下)、Wi-Fi送信のバッチ化を検討 |

## 8. 実装ロードマップ

1. **Step 1 — 1対1測距検証(まずここから)**: 公式`DS_TWR_TAG/ANCHOR`サンプルを2ノードで動かし、既知距離での誤差・成功率・1回の測距所要時間を実測する。**この実測値で §4.4のスロット設計を確定させる。**
2. **Step 2 — 1タグ × 4アンカー2D測位**: タグFWにアンカー巡回を実装、MQTT送信、サーバーで最小二乗解算+可視化。1セル(〜20 m四方)で精度評価。
3. **Step 3 — マルチタグTDMA**: SNTPスロット同期を実装し、タグ2〜5台での測距成功率・更新レートを評価。
4. **Step 4 — 中規模展開**: セル分割・アンカーリスト配信・ハンドオーバーを実装し、フロア全域で試験。誤差マップ作成と校正。

## 9. 補足: 市販タグ(AirTag等)との相互運用性

**AirTagなどの市販トラッカーは本システムのタグとして扱えない。** 同じUWBでも、測距が成立するには両端が同じ測距プロトコルを話す必要がある。本設計のアンカーはM5Stamp-UWBライブラリ独自のTWRフレームで応答するが、市販トラッカーはこれに応答しない。

- AirTagのUWB測距(Precision Finding)は**Apple独自プロトコルで、U1/U2チップ搭載iPhoneとの間でのみ**動作する。セッション確立はFind Myネットワークの暗号化BLE交換で行われ、サードパーティのアンカーがAirTagとTWRセッションを張る手段は公開されていない。
- プライバシー保護のためBLE識別子も約15分ごとにローテーションし、個体の継続追跡はできない(意図的な設計)。
- TileなどBLEのみのトラッカーはUWBを持たず、RSSIによる近接判定程度しかできない(30 cm級測位は不可能)。

市販デバイスを絡めたい場合の選択肢:

| 選択肢 | 実現性 | 内容 |
|---|---|---|
| **本設計のまま自作タグ** | ◎ | Stamp C5 + UWB F(~$31/台)。プロトコルを完全に制御でき、AirTagより安い |
| Androidスマホをタグ化 | △ 大規模開発 | UWB搭載Android(Pixel Pro / Galaxy Ultra等)はFiRa標準の測距APIを公開している。ただしアンカー側に**FiRaプロファイル(BLE帯域外セッション確立含む)の実装**が必要で、公式ライブラリの範囲を大きく超える。QM33120W自体はFiRa対応チップなので不可能ではない、という位置づけ |
| iPhoneと連携 | △ 方向が逆 | Apple Nearby Interactionはサードパーティ製アクセサリとの測距をサポートし、QorvoがDW3xxx向け対応SDKを提供している。ただし「iPhoneが自分の位置からアクセサリを測る」構図であり、複数アンカーでiPhoneを常時測位するRTLSには設計上向かない |
| 市販RTLS専用タグ | △ 別システム | Qorvo DWM3001系などの市販RTLSタグはベンダー独自プロトコル(またはFiRa)で動作し、本システムのアンカーとは相互運用できない。採用するならアンカー含めベンダーのシステム一式へ乗り換える判断になる |

コンシューマ向けUWBトラッカーはエコシステム内(AirTag ⇔ iPhone、Galaxy SmartTag ⇔ Galaxy)に閉じており、汎用RTLSのタグとしては開放されていない。追跡対象に取り付ける用途では**自作タグが最も確実で安価**、というのが本設計の前提。

## 参考リンク

- 製品ドキュメント: https://docs.m5stack.com/en/stamp/Stamp_UWB
- 公式ライブラリ: https://github.com/m5stack/M5Stamp-UWB
- Stamp UWB F(FPC版・$24.50): https://shop.m5stack.com/products/m5stamp-uwb-module-with-fpc-qm33120w
- M5StampC5($6.50): https://shop.m5stack.com/products/m5stampc5-module-esp32-c5
- Stamp C5ドキュメント: https://docs.m5stack.com/en/core/Stamp-C5

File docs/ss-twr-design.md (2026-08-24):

# SS-TWR測距方式詳細設計書

- 作成日: 2026-08-15
- ステータス: ドラフト(実装前レビュー用)
- 上位文書: [rtls-design.md](rtls-design.md) §2(**予備方式** — エアタイム逼迫時の代替)
- 関連文書: [ds-twr-design.md](ds-twr-design.md)(採用方式)、[tdoa-design.md](tdoa-design.md)(将来方式)

## 1. 位置づけ

SS-TWR(Single-Sided Two-Way Ranging)は2メッセージで完結する軽量なTWR。**標準方式はDS-TWR**とし、SS-TWRは次の条件で切り替える予備方式として設計しておく。

- タグ数・更新レートを上げて**UWBエアタイムが逼迫**した場合(交換時間 ≈ 2/3に短縮)
- タグの電池持ちを優先し、送受信回数を減らしたい場合

**切替の前提条件(§4)を満たすことを実測で確認できるまで、本方式は投入しない。**

## 2. 測距原理

### 2.1 メッセージ交換(2メッセージ方式)

```mermaid
sequenceDiagram
    participant T as タグ (Initiator)
    participant A as アンカー (Responder)
    Note over T: t1: Poll 送信
    T->>A: ① Poll
    Note over A: t2: Poll 受信
    Note over A: t3: Response 送信(遅延 T_reply)
    A->>T: ② Response(t2, t3 を搭載)
    Note over T: t4: Response 受信 → ToF 計算
```

### 2.2 ToF計算式と本質的弱点

```
ToF = (T_round − T_reply) / 2        T_round = t4 − t1, T_reply = t3 − t2
```

タグとアンカーのクロック偏差の差 Δe(= e_T − e_A)があると、T_replyの計測が両ノードで食い違い、誤差が**応答遅延に比例して**乗る:

```
err ≈ Δe × T_reply / 2
```

具体値: 各水晶 ±20 ppm(最悪 Δe = 40 ppm)、T_reply = 3000 µsのとき

```
err ≈ 40e-6 × 3000 µs / 2 = 60 ns  →  距離誤差 ≈ 18 m(!)
```

**つまり補償なしのSS-TWRは、本構成のようにホスト遅延でT_replyがms級になる場合、実用にならない。** 成立させるには次のいずれかが必須:

1. **クロックオフセット補償(CFO補正)**: QM33120Wは受信キャリアからクロック偏差比を推定できる(IEEE 802.15.4z系デバイスの標準機能)。Response受信時の偏差推定値で`T_reply`を補正すれば、残留誤差はcm〜dm級に落ちる。**公式ライブラリの`requestRange()`が内部でこれを行うかは未確認 — 切替前提条件①として実測で検証する(§4)。**
2. **T_replyの最小化**: 補償が使えない場合、T_replyを µs級(チップ内自動応答)まで詰める必要があるが、ホストMCU経由の本構成では現実的でない。

## 3. ライブラリ実装仕様

| 役割 | API | 備考 |
|---|---|---|
| タグ | `requestRange(M5Stamp_UWBRangeConfig)` → `M5Stamp_UWBRangeResult` | 公式サンプル`SS_TWR_TAG`準拠 |
| アンカー | `respondRange(M5Stamp_UWBRangeConfig)` → `M5Stamp_UWBResponderResult` | `SS_TWR_ANCHOR`準拠 |

- アドレス・PAN・PHY設定、リトライ方針、TDMA統合は**DS-TWR設計(ds-twr-design.md §3.2, §3.4, §5)と同一**。タグの巡回ループで呼ぶ関数が`requestDSRange` → `requestRange`に変わるだけにする(`ranging.cpp`内で方式をビルドフラグではなく**設定値**で切替可能にし、フィールドでA/B比較できるようにする)。
- タイミング初期値: `responseTxDelayUus`(定数`kSsResponseTxDelayUus`)3000 µs、RXタイムアウト(`kSsRxTimeoutUus`)4500 µs(公式サンプル準拠。確定値は`rtls_common.h`の`kSs*`定数を正とする)。

## 4. DS-TWRからの切替判断

| # | 前提条件(すべて実測で確認) | 検証方法 |
|---|---|---|
| ① | ライブラリのSS-TWRがクロックオフセット補償を行い、静的誤差が**σ ≤ 15 cm・バイアス ≤ 10 cm**に収まる | §6の1. の静的試験をDS-TWRと並べて実施 |
| ② | SS-TWRの1交換所要時間がDS-TWR比で**30% 以上短い** | §6の2. タイミング実測 |
| ③ | 精度低下がシステム要件(CEP50 ≤ 30 cm)を壊さない | 同一ログ・リプレイでA案パイプラインのCEPを比較 |

判断基準の目安: **タグ×更新レートの積が「5台 × 2 Hz」を超える拡張**(例: 5台 × 4 Hz、10台 × 2 Hz)を求められた時に検証を開始する。それ以下ならDS-TWRのまま。

## 5. エアタイム比較(切替の効果見積もり)

| 項目 | DS-TWR | SS-TWR | 備考 |
|---|---|---|---|
| メッセージ数/測距 | 4(Poll / Response / Final / Result) | 2(Poll / Response) | DS側は距離をアンカーが計算しResultで返す(ds-twr-design.md §2.1) |
| 1交換の所要時間 | ~T(実測、5〜10 ms見込み) | ~0.5〜0.6T(実測で置換) | FinalとResultの送信・受信待ちが消える。SSはResponseに載ったt2, t3からタグ側で計算する |
| スロット幅(4アンカー+リトライ) | 90 ms | ~60 ms | スーパーフレーム500 msなら**8タグ**まで、またはタグ5台のまま **~3 Hz**に向上 |
| タグ送信回数/測距 | 2回 | 1回 | 電池持ちに寄与 |

## 6. テスト計画

1. **静的精度(DS-TWRと対照)**: 既知距離1 / 5 / 10 / 20 mで各1000回、DS-TWRと同条件で測距し、バイアス・σ・温度依存(始動直後vs 30分後)を比較。クロックオフセット補償の有無はここで判明する(補償なしならm級誤差が出る)。
2. **タイミング実測**: 1交換のp50/p95を計測し、§5の短縮率を実測値に置き換える。
3. **方式切替試験**: 運用中に設定変更(`rtls/config/tuning`経由)でDS→SSを切り替え、解算パイプライン(A案)が`bias_mm`再校正だけで追従できることを確認(方式ごとにバイアスが異なる可能性があるため、**biasテーブルは方式別に持つ**)。

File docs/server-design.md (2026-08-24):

# 測位サーバー詳細設計書(A案: サーバー計算)

- 作成日: 2026-08-15
- ステータス: ドラフト(実装前レビュー用)
- 上位文書: [rtls-design.md](rtls-design.md)(基本設計 §5で採用した「A案: サーバー計算」の詳細設計)

## 1. スコープと責務

本書は、タグからMQTTで届く**生距離セット**を入力とし、**フィルタ済み2D座標**と**アンカーリスト配信(セルハンドオーバー)** を出力する測位サーバーの詳細設計を定める。

| 責務 | 内容 |
|---|---|
| 距離データ受信 | `rtls/tag/{id}/ranges`の購読、スキーマ検証、鮮度チェック |
| 解算 | 高低差補正 → ゲーティング → 最小二乗測位 → 残差ベース外れ値除去 → カルマンフィルタ |
| セル管理 | タグ位置からセルを判定し、担当アンカーリストをretained配信(ヒステリシス付き) |
| 記録・再生 | 生距離のJSONL記録と、記録からのオフライン再解析(リプレイ) |
| 可視化・API | WebSocketによるリアルタイム配信、RESTによる状態参照 |
| 監視 | タグ死活(STALE/LOST)、アンカー欠測率、解算品質の集計 |

**非スコープ**: ファームウェア、MQTTブローカー自体の運用設計、認証・マルチテナント。

## 2. 技術スタックと動作環境

| 項目 | 選定 | 理由 |
|---|---|---|
| 言語 / ランタイム | Python 3.12+、単一プロセスasyncio | タグ5台×2Hz = 最大10 msg/sと負荷が軽く、プロセス分割は不要 |
| MQTTクライアント | aiomqtt | asyncioネイティブ。再接続ループを自前で書ける |
| 数値計算 | numpy / scipy | 線形化LSQと`scipy.optimize.least_squares` |
| 設定・検証 | pydantic v2 + YAML | `config.yaml`と受信JSONのスキーマ検証を同じ機構で行う |
| Web / 可視化 | FastAPI + uvicorn、WebSocket | 解算プロセスに同居させ、追加ブローカー不要 |
| 配布 | venv + `pip install -e .`(常設時はDocker ComposeでMosquittoと同梱) | |
| 時刻同期基盤 | **chrony(NTPサーバー)をサーバーホストに同居** | タグのSNTP同期先(rtls-design.md §4.9)。インターネットNTP非依存でLAN完結 |

## 3. モジュール構成

```
server/
├── app.py                  # エントリポイント: 各タスクの起動・停止
├── config.py               # config.yaml の読込・pydantic 検証
├── models.py               # RangeSet / Position / TagState 等のデータ型
├── mqtt_io.py              # aiomqtt の購読/publish ラッパ(再接続込み)
├── positioning/
│   ├── pipeline.py         # タグごとの解算パイプライン(本書 §5)
│   ├── geometry.py         # 高低差補正・線形化LSQ・非線形リファイン
│   ├── outlier.py          # ゲーティングと leave-one-out 除去
│   └── kalman.py           # 等速モデル 2D カルマンフィルタ
├── cells.py                # セル判定・ハンドオーバー(ヒステリシス)
├── recorder.py             # 生距離 JSONL 記録
├── replay.py               # 記録の再生(MQTT を介さず pipeline へ直接投入)
├── monitor.py              # タグ死活・アンカー欠測率の集計
├── web/
│   ├── api.py              # FastAPI: REST + WebSocket
│   └── static/             # フロアマップ UI (単一 HTML + Canvas)
└── config.yaml
```

```mermaid
flowchart LR
    BR["MQTT ブローカー"] -- "ranges (subscribe)" --> IO["mqtt_io"]
    IO --> REC["recorder<br/>(JSONL 追記)"]
    IO --> PL["pipeline ×タグ数<br/>(タグごとに独立インスタンス)"]
    CFG["config.py<br/>config.yaml"] --> PL
    CFG --> CELLS
    PL --> KF["kalman"]
    PL --> CELLS["cells<br/>セル判定・ハンドオーバー"]
    CELLS -- "anchors (retained publish)" --> IO
    PL -- "position (publish)" --> IO
    PL --> HUB["web/api<br/>WebSocket ハブ"]
    MON["monitor"] --> HUB
    PL --> MON
    HUB --> UI["ブラウザ UI"]
    RP["replay.py"] -. "オフライン投入" .-> PL
```

設計原則: **pipelineはMQTTを知らない**(入出力は`models.py`の型のみ)。これによりreplay・単体テストがMQTTなしで動く。

## 4. データモデル(models.py)

```python
@dataclass(frozen=True)
class Range:
    anchor: int          # ショートアドレス (例 0x0010)
    d_mm: int            # 斜距離。ok=False のとき無効
    ok: bool

@dataclass(frozen=True)
class RangeSet:          # rtls/tag/{id}/ranges 1件に対応
    tag: int
    seq: int
    t_ms: int            # タグ側タイムスタンプ (SNTP 同期済み)
    recv_ms: int         # サーバー受信時刻
    ranges: tuple[Range, ...]

@dataclass(frozen=True)
class Position:          # rtls/tag/{id}/position 1件に対応
    tag: int
    t_ms: int
    x_m: float
    y_m: float
    vx_ms: float
    vy_ms: float
    n_used: int          # 解算に使った距離数
    residual_m: float    # 使用距離の RMS 残差
    cell: str
    state: TagTrackState # TRACKING / COASTING

class TagTrackState(Enum):
    INIT = auto()        # フィルタ未初期化
    TRACKING = auto()    # 通常追尾
    COASTING = auto()    # 当該エポック欠測、予測のみで出力
    STALE = auto()       # stale_sec 以上更新なし(UI 警告)
    LOST = auto()        # lost_sec 以上更新なし(UI 非表示)
```

## 5. 解算パイプライン(positioning/pipeline.py)

タグごとに1インスタンス。`process(rs: RangeSet) -> Position | None`を同期関数として実装する(1呼び出し < 1 ms想定、asyncioをブロックしない)。

```mermaid
flowchart TB
    IN["RangeSet 受信"] --> V["① 検証<br/>スキーマ / seq 重複・逆行 / 鮮度"]
    V --> H["② 高低差補正<br/>斜距離 → 水平距離"]
    H --> G["③ ゲーティング<br/>予測位置からあり得ない距離を棄却"]
    G --> N{"有効距離 ≥ 3 ?"}
    N -- "No" --> CO["COASTING: カルマン予測のみ出力"]
    N -- "Yes" --> LSQ["④ 線形化 LSQ で初期解"]
    LSQ --> REF["⑤ 非線形リファイン<br/>(soft_l1 損失)"]
    REF --> R{"最大残差 > residual_gate<br/>かつ有効距離 ≥ 4 ?"}
    R -- "Yes" --> LOO["⑥ 最悪距離を除外して再解算<br/>(1回のみ)"]
    LOO --> KF
    R -- "No" --> KF["⑦ カルマン更新"]
    CO --> OUT
    KF --> OUT["Position 出力"]
```

### ① 検証

- pydanticでJSONスキーマ検証。不正メッセージは破棄しカウンタ加算。
- `seq`が前回以下なら破棄(再送・順序逆転)。
- `recv_ms - t_ms > max_age_ms`(既定500 ms)なら破棄(滞留した古いデータでフィルタを汚さない)。

### ② 高低差補正(geometry.py)

アンカー高`z_a`、タグ想定高`z_t`(configで指定、既定1.0 m)として、斜距離dを水平距離に変換:

```
r = sqrt(max(d² − (z_a − z_t)², 0))    # 根号内が負なら r=0 とし当該距離は棄却
```

### ③ ゲーティング(outlier.py)

カルマンが初期化済みのとき、予測位置`p̂`から各アンカーへの予測距離`r̂_i`を計算し、

```
|r_i − r̂_i| > v_max × Δt + gate_margin_m   →  棄却
```

既定: `v_max = 2.0 m/s`(歩行想定)、`gate_margin_m = 0.6 m`(測距ノイズ3σ + 予測誤差の余裕)。INIT中はゲーティングをスキップ。

### ④⑤ 最小二乗測位(geometry.py)

**初期解(線形化LSQ)**: アンカーi=1を基準にi=2..nについて

```
2(x_i − x_1)x + 2(y_i − y_1)y = (x_i² − x_1²) + (y_i² − y_1²) + (r_1² − r_i²)
```

を立て、`numpy.linalg.lstsq`で解く(n=3で一意、n≥4で過決定)。

**リファイン**: 初期解を出発点に`scipy.optimize.least_squares`で残差`f_i(p) = ‖p − a_i‖ − r_i`を最小化。`loss='soft_l1', f_scale=0.3`で軽度のNLoS伸びに対しロバスト化。収束しない場合は線形解をそのまま採用しフラグを立てる。

### ⑥ 残差ベース外れ値除去

リファイン後の最大絶対残差が`residual_gate_m`(既定0.5 m)を超え、かつ有効距離が4以上のとき、**最悪の1距離を除外して④⑤を1回だけ再実行**する。改善しなければ元の解を採用(無限ループ・過剰除去の防止)。NLoSは距離が「伸びる」方向に出るため、残差が正に大きい距離を優先的に疑う。

### ⑦ カルマンフィルタ(kalman.py)

等速直線運動(CV)モデル。状態`x = [x, y, vx, vy]ᵀ`。

- 遷移: `F(dt)`は標準CV。プロセスノイズは加速度白色雑音`σ_a = 1.0 m/s²`(人の歩行変化を吸収)から`Q(dt)`を構成。
- 観測: 解算座標`z = [x, y]`。観測ノイズ`R = diag(σ_m², σ_m²)`、`σ_m = max(0.15, residual_m)`として**解算品質が悪いエポックほど信頼を下げる**。
- dtはタグ側`t_ms`の差分から算出(サーバー受信ジッタの影響を受けない)。
- 欠測エポック(有効距離 < 3)はpredictのみでCOASTING出力。`stale_sec`(既定2 s)連続でSTALE、`lost_sec`(既定10 s)でLOSTとし共分散をリセット、次の解でINITからやり直す。

```mermaid
stateDiagram-v2
    [*] --> INIT
    INIT --> TRACKING : 解算成功(フィルタ初期化)
    TRACKING --> COASTING : エポック欠測(予測のみ)
    COASTING --> TRACKING : 解算成功
    TRACKING --> STALE : 2 s 更新なし
    COASTING --> STALE : 2 s 更新なし
    STALE --> TRACKING : 解算成功
    STALE --> LOST : 10 s 更新なし
    LOST --> INIT : 新しい RangeSet 到着
```

## 6. セル管理とハンドオーバー(cells.py)

- セルは軸平行矩形 + 担当アンカーリスト(4〜6台)として`config.yaml`に定義。
- 判定はカルマン出力座標に対して行う。**ヒステリシス**: 現セルの矩形を`handover_margin_m`(既定2.0 m)外側に拡張した領域を出るまで現セルを維持し、境界での配信フラッピングを防ぐ。
- セルが変わったときのみ`rtls/tag/{id}/anchors`を**retained**でpublish(タグ再起動時も最後のリストを受け取れる)。
- LOSTタグには全セル横断の「初期取得用リスト」(フロア中央寄りのアンカー)を配信し、再捕捉を助ける。

## 7. MQTT入出力(mqtt_io.py)

| トピック | 方向 | QoS | retain | 備考 |
|---|---|---|---|---|
| `rtls/tag/+/ranges` | 購読 | 0 | — | 欠測許容データ。QoS1の再送はかえって古いデータを運ぶため使わない |
| `rtls/tag/{id}/position` | publish | 0 | false | 外部連携用。UIはWebSocket経由が主 |
| `rtls/tag/{id}/anchors` | publish | 1 | **true** | ハンドオーバー指示。確実に届け、新規接続タグにも即配信 |
| `rtls/anchor/+/status` | 購読 | 0 | — | heartbeat(任意)。monitorへ転送 |

再接続: 指数バックオフ(1→2→…→30 s上限)で永続リトライ。切断中のrangesは捨てる(リアルタイム性優先)。

## 8. 記録とリプレイ(recorder.py / replay.py)

- **記録**: 受信したrangesを検証前の生JSONのまま`logs/ranges-YYYYMMDD.jsonl`に追記(1行1メッセージ、`recv_ms`を付加)。日次ローテーション。5タグ × 2 Hz ≈ 15 MB/日程度。
- **リプレイ**: `python -m server.replay logs/ranges-20260815.jsonl --config config.yaml --speed 0`で、MQTTを介さずpipelineに直接投入し`positions.jsonl`を出力。`--speed 0`は最速一括処理(パラメータチューニング用)、`--speed 1`は実時間再生(UI確認用)。
- これがA案の核となる利点: **アルゴリズム変更の評価は常に同一ログに対するリプレイで行い、実機再測定を不要にする。**

## 9. Web API・可視化(web/api.py)

| エンドポイント | 内容 |
|---|---|
| `GET /api/floor` | フロア定義(寸法、セル矩形、アンカー座標)— UI初期化用 |
| `GET /api/tags` | 全タグの最新Positionと追尾状態 |
| `GET /api/stats` | アンカー別測距成功率、タグ別更新レート、破棄カウンタ |
| `WS /ws` | Positionと統計のpush配信(下記スキーマ) |

WebSocket配信メッセージ(MQTTのpositionペイロードに`"type":"position"`を加えた形):

```json
{"type":"position","tag":"0x0001","t_ms":1755212345690,
 "x_m":12.34,"y_m":8.76,"vx_ms":0.51,"vy_ms":-0.12,
 "quality":{"n_anchors":4,"residual_m":0.03},
 "anchors_used":["0x0010","0x0011","0x0013","0x0014"],"anchors_rejected":[],
 "cell":"A","state":"TRACKING"}
```

UI(`web/static/`、単一HTML + Canvas):フロア平面図にアンカー(●)、セル境界、タグ(現在位置+直近30秒の軌跡)、状態色(TRACKING=通常 / COASTING・STALE=警告 / LOST=非表示+一覧に警告)。追加ライブラリなしの素のCanvas描画とする。

## 10. config.yamlスキーマ

```yaml
mqtt:
  host: 192.168.1.10
  port: 1883
floor:
  width_m: 50.0
  height_m: 50.0
  tag_height_m: 1.0          # 高低差補正のタグ想定高
anchors:                     # ショートアドレスは 16 進文字列
  "0x0010": { x: 0.0,  y: 0.0,  z: 2.2, bias_mm: -35 }   # bias_mm: 校正オフセット
  "0x0011": { x: 25.0, y: 0.0,  z: 2.2, bias_mm: 12 }
  # ...
cells:
  A: { rect: [0, 0, 25, 25],  anchors: ["0x0010","0x0011","0x0013","0x0014"] }
  B: { rect: [25, 0, 50, 25], anchors: ["0x0011","0x0012","0x0014","0x0015"] }
  # ...
tags: ["0x0001", "0x0002", "0x0003"]
tuning:
  max_age_ms: 500
  v_max_ms: 2.0
  gate_margin_m: 0.6
  residual_gate_m: 0.5
  sigma_a: 1.0               # プロセスノイズ (m/s²)
  sigma_m_floor: 0.15        # 観測ノイズ下限 (m)
  stale_sec: 2.0
  lost_sec: 10.0
  handover_margin_m: 2.0
```

起動時検証: 各セルのアンカーが`anchors`に存在すること、セル矩形がフロア内に収まること、タグ・アンカーのアドレス重複がないことをpydanticバリデータで検査し、不備は起動失敗にする。

## 11. 処理シーケンス

```mermaid
sequenceDiagram
    participant T as タグ FW
    participant B as MQTT ブローカー
    participant P as pipeline(タグ別)
    participant C as cells
    participant W as WebSocket UI
    T->>B: rtls/tag/1/ranges (QoS0)
    B->>P: RangeSet(検証・記録済み)
    P->>P: 高低差補正 → ゲーティング
    P->>P: LSQ → リファイン → 残差検査(必要なら1距離除外)
    P->>P: カルマン更新
    P->>B: rtls/tag/1/position
    P->>W: {"type":"position", ...}
    P->>C: 座標でセル判定(ヒステリシス)
    alt セル変更あり
        C->>B: rtls/tag/1/anchors (QoS1, retained)
        B->>T: 新アンカーリスト
    end
```

## 12. エラー処理・監視(monitor.py)

| 事象 | 検出 | 応答 |
|---|---|---|
| 不正JSON / スキーマ違反 | pydantic検証失敗 | 破棄、タグ別カウンタ加算(UIの /api/statsで参照できる) |
| 古いデータ | `recv_ms − t_ms > max_age_ms` | 破棄。多発時はSNTPずれ警告(タグ時刻とサーバー時刻の差を統計表示) |
| アンカー欠測率上昇 | 直近5分のok=false率 > 30% | UI警告(設置物による遮蔽・電源断の兆候) |
| タグ無応答 | STALE / LOST遷移 | UI警告 / 非表示。LOSTタグへ初期取得用アンカーリスト配信 |
| ブローカー切断 | aiomqtt例外 | 指数バックオフ再接続。UIにサーバー状態表示 |

## 13. テスト計画

1. **単体テスト(実機不要)**
   - `geometry`: 既知の合成ジオメトリ(真値座標+ノイズ付き距離)で誤差 < 数cmを検証。共線配置・n=3の縮退ケースを含める。
   - `outlier`: 1距離に +1〜3 mのNLoSバイアスを注入し、除去が働き解が復元されることを検証。
   - `kalman`: 直線・停止・折返し軌跡の合成データでRMS誤差とCOASTING挙動を検証。
   - `cells`: 境界往復でヒステリシスが働き、配信が1回に抑えられることを検証。
2. **合成シミュレータ**: 真値軌跡(歩行モデル)→ 距離生成(ガウスノイズ σ=0.05 m + 確率的NLoSバイアス + 欠測率)→ ranges JSONLを出力するツールを`tools/simulate.py`に置き、**実機なしでend-to-end(リプレイ経由)を回す**。
3. **リプレイ回帰**: 実機で採取したログを`tests/fixtures/`に保存し、パラメータ変更時のCEP50 / CEP95 / 軌跡RMSを比較するスクリプトで劣化を検知。
4. **受入基準**(基本設計 §6と同一): 見通し静置でCEP50 ≤ 0.30 m、歩行時に軌跡破綻(1エポックで2 m超のジャンプ)なし、ハンドオーバー時の位置飛びなし。

## 14. 性能・容量見積もり

| 項目 | 見積もり |
|---|---|
| 入力レート | 最大5タグ × 2 Hz = 10 msg/s |
| 解算1回の計算量 | 4×2のLSQ + 反復 ≈ 数百 µs(Pythonでも余裕) |
| 追加レイテンシ | 受信→position publishまでp95 < 10 ms目標(Wi-Fi/ブローカー分は別途 +10〜50 ms) |
| ログ容量 | ≈ 15 MB/日(JSONL、5タグ時)。30日で0.5 GB — ローテーションのみで十分 |
| 対応上限 | 本設計のまま20タグ × 5 Hz程度までスケール可(ボトルネックはUWBエアタイム側) |

## 15. 実装順序

1. `models.py` + `config.py` + 合成シミュレータ(§13の2.)— 実機なしで開発ループを確立
2. `geometry` / `outlier` / `kalman` + 単体テスト
3. `pipeline` + `replay` — シミュレータ出力でend-to-end検証
4. `mqtt_io` + `recorder` — 実機(基本設計ロードマップStep 2)と結合
5. `web/api` + UI
6. `cells`ハンドオーバー(基本設計Step 4と同期)

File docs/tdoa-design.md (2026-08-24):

# TDoA測位方式詳細設計書(将来方式)

- 作成日: 2026-08-15
- ステータス: ドラフト(**実現条件の設計** — 現行システムでは不採用)
- 上位文書: [rtls-design.md](rtls-design.md) §2(不採用理由)・§7(エアタイム逼迫リスク)
- 関連文書: [ds-twr-design.md](ds-twr-design.md)、[ss-twr-design.md](ss-twr-design.md)

## 1. 位置づけ

TDoA(Time Difference of Arrival)は基本設計 §2で**不採用**とした方式。本書は「不採用の根拠を技術的に固定する」ことと、「将来TWRの容量限界(タグ10台超・高更新レート・電池数年級)を超える要求が出た場合に、何を作れば実現できるか」を設計として残すことを目的とする。**実装の意思決定文書ではない。**

## 2. 測位原理

### 2.1 ブリンクと到達時刻差

タグは**1回の短いブリンク送信のみ**を行い、複数アンカーが受信時刻(RXタイムスタンプ)を記録する。アンカーi, jの受信時刻差から

```
c × (t_i − t_j) = ‖p − a_i‖ − ‖p − a_j‖
```

という**双曲線**が得られ、アンカー4台以上(2Dなら独立差3本)の交点としてタグ位置pを解く。

```mermaid
sequenceDiagram
    participant T as タグ
    participant A1 as アンカー1
    participant A2 as アンカー2
    participant A3 as アンカー3
    participant S as 測位サーバー
    T--)A1: ブリンク(1 送信を全アンカーが同時受信)
    T--)A2: 〃
    T--)A3: 〃
    A1->>S: (tag_id, seq, RXタイムスタンプ t1)
    A2->>S: (tag_id, seq, t2)
    A3->>S: (tag_id, seq, t3)
    S->>S: 同期補正 → 双曲線最小二乗 → カルマン
```

### 2.2 TWRとの本質的トレードオフ

| 観点 | TWR(現行) | TDoA |
|---|---|---|
| タグの送受信/測位 | 送2×4 + 受2×4(DS、4アンカー) | **送1・受0** |
| タグ電力 | mA級デューティ | µA級平均(電池が年単位) |
| 容量 | エアタイムで数十測位/秒 | ブリンク < 1 ms → **数百タグ**でも成立(ALOHA) |
| アンカー要件 | 応答するだけ(同期不要) | **ns級クロック同期 + 常時受信 + バックホール必須** |
| タグ側の複雑さ | 巡回・TDMAが必要 | ブリンクするだけ(乱数間隔) |
| 難しさの所在 | タグ側の規律 | **アンカー側のインフラ** |

要するにTDoAは「タグを極限まで単純・省電力にする代わりに、アンカーを高機能なインフラにする」方式。1 nsの同期誤差 = 30 cmの測位誤差なので、**アンカー間同期を ~1 nsに保つ仕組みが成立条件のすべて**である。

## 3. 成立条件(何を作れば実現できるか)

### 3.1 前提条件: RXタイムスタンプへのアクセス ★最大の障壁

公式ライブラリの公開API(`receiveFrame()`等)は**受信フレームのns級RXタイムスタンプを公開していない**。DW3720のレジスタ(RX_STAMP相当)には存在するため、同梱の`qm33120w_sdk`を直接叩く**ライブラリ拡張の自作**が必要になる。これが成立しない限りTDoAは始まらない — 着手時は最初にこの拡張のPoCを行う(§6)。

### 3.2 アンカー間クロック同期の方式比較

| 方式 | 精度 | 判定 | 内容 |
|---|---|---|---|
| **無線同期(リファレンスアンカー方式)** | ~1 ns級(文献実績) | ✅ 採用候補 | マスターアンカーが既知位置から周期ブリンク(例: 100 ms毎)を送信。各アンカーは「マスターブリンクの受信時刻」と「既知の伝搬遅延」から自クロックのオフセット+ドリフト率を推定し、タグブリンクのRX時刻を共通時間軸へ補正する。追加ハード不要 |
| 有線クロック分配 | < 1 ns | △ | 全アンカーへ同軸/ツイストペアでクロック配線。精度は最良だが配線工事がセル分割の利点を消す |
| Wi-Fi/NTP系 | ms〜µs | ❌ | 6桁足りない(1 ms = 300 km) |

**無線同期の設計骨子**: アンカー時計の状態(offset, drift)をアンカーごとにサーバー側で2状態カルマン推定する。マスターブリンク間隔100 ms・水晶 ±20 ppmのとき、区間中のドリフト誤差は20e-6 × 100 ms = 2 µs — これを**ドリフト率推定で補正**して残留 ~1 nsに抑えるのが成立ラインであり、水晶の短期安定度(温度変動)が実質的な精度上限を決める。TCXO搭載アンカーへの置換が必要になる可能性がある(実測で判断)。

### 3.3 システム構成(実現時)

```mermaid
flowchart TB
    subgraph floor["フロア"]
        TAG["タグ ×N<br/>乱数間隔ブリンクのみ<br/>(Wi-Fi 不要・µA 級)"]
        M["マスターアンカー<br/>周期同期ブリンク"]
        A["アンカー ×8〜12<br/>常時受信 + RX タイムスタンプ取得<br/>★拡張ライブラリ"]
    end
    TAG --)A: ブリンク
    M --)A: 同期ブリンク (100 ms 毎)
    A -- "有線 LAN 推奨<br/>(t_rx, tag_id, seq)" --> S["測位サーバー"]
    S --> SYNC["クロック補正<br/>(アンカー別 offset/drift カルマン)"]
    SYNC --> SOLVE["双曲線最小二乗<br/>(Chan 初期解 + Taylor 反復)"]
    SOLVE --> KF["タグ別カルマン<br/>(A案 §5 を流用)"]
```

現行構成からの主な変更点:

| 要素 | 現行(TWR) | TDoA化での変更 |
|---|---|---|
| タグFW | 巡回測距 + TDMA + Wi-Fi | **ブリンクのみ**(乱数間隔 = スロットレスALOHA。衝突は確率損失として許容) |
| アンカーFW | `respondDSRange()`ループ | 常時RX + タイムスタンプ即時報告。**Wi-Fiでは報告遅延ジッタが大きく、有線LAN(またはイーサネット付きホストへの換装)を推奨** |
| サーバー | 距離 → 三辺測量 | 受信時刻 → 同期補正 → 双曲線解算。カルマン以降(A案 §5 ⑦)は流用可 |
| 校正 | ノード別bias | アンカー別RX遅延校正 + マスター・各アンカー間の正確な測量(同期精度に直結) |

### 3.4 解算(サーバー側)

- 観測: 基準アンカー0との時刻差`Δt_i = t_i − t_0`(同期補正後)。
- 初期解: Chanの閉形式解、以後Taylor展開の反復最小二乗(残差 = 双曲線距離差)。幾何条件が悪い(アンカー凸包の外)と発散しやすいため、**セル内(凸包内)のみで解算**する制約はTWRと同じ。
- 外れ値・平滑化: A案 §5のゲーティング・leave-one-out・カルマンをそのまま適用(観測モデルだけ差し替え)。

## 4. 誤差予算(成立時の見込み)

| 要因 | 目安 | 備考 |
|---|---|---|
| 同期残留誤差 | 30 cm/ns → **~1 nsに抑えて30 cm** | 支配項。TCXO化で改善余地 |
| RXタイムスタンプ量子化 | ~15 ps(DW3xxx系) | 無視できる |
| NLoS | +0.3〜数m | TWRと同様、外れ値除去で対処 |
| 幾何(HDOP) | 凸包外で急劣化 | セル運用で回避 |

→ 総合で**30〜50 cm級**が現実的な出発点。TWR(校正後 ~15 cm級)より粗いことは織り込む。

## 5. 導入判断基準

次の**いずれか**が要求された時点で §6のPoCに着手する。それまではTWR系(DS→SS切替を含む)で引っ張る:

1. 同時タグ数 **> 20台**(SS-TWR化後のエアタイム上限を超える)
2. 更新レート **> 5 Hz**をフロア全域で要求
3. タグ電池寿命**年単位**が必須(ブリンクのみの µA級動作が必要)

## 6. 段階的PoC計画(着手する場合)

1. **RXタイムスタンプ取得のPoC** ★ゲート条件: `qm33120w_sdk`直叩きで`receiveFrame`相当の処理からns級RX時刻を取得できることを確認。不成立ならその時点でTDoA断念(または他社モジュール検討)を判断。
2. **2アンカー同期実験**: マスターブリンクで2アンカーのclock offset/driftを推定し、静止タグのブリンクで`Δt`の標準偏差を測定(目標 σ < 2 ns)。
3. **1セルTDoA**: 4アンカー + 有線バックホールで静的測位、CEP評価。
4. **判断**: TWR併存(タグ種別ごとに方式を選ぶハイブリッド)か全面移行かを、2〜3の実測で決める。

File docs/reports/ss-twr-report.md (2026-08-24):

# 実測レポート: SS-TWR対照試験(Issue [#14](https://github.com/atinfinity/m5stamp_uwb_rtls/issues/14))

> このファイルをコピーして記入する。DS-TWR(Step 1)と**同じ設置**で実施すること。
> 手順: [firmware/README.md](../../firmware/README.md)「SS-TWR検証」/ 設計: [ss-twr-design.md](../ss-twr-design.md) §4/§6

## 測定条件

| 項目 | 記入 |
|---|---|
| 実施日 / 実施者 | |
| Step 1(DS対照データ)のレポート | |
| FWコミット / env(`tag_step1_ss` + `anchor_ss`) | |
| 気温 / 通電からの経過時間 | |

## 1. 静的精度の対照(各距離1000回、DSと同条件)

| 真値[m] | 方式 | 成功率[%] | bias [cm] | σ [cm] |
|---|---|---|---|---|
| 1.000 | DS | | | |
| 1.000 | SS | | | |
| 5.000 | DS | | | |
| 5.000 | SS | | | |
| 10.000 | DS | | | |
| 10.000 | SS | | | |
| 20.000 | DS | | | |
| 20.000 | SS | | | |

```
(analyze.py で DS/SS を並べた生出力貼付欄)
```

温度依存(5 m固定):

| 条件 | DS bias/σ [cm] | SS bias/σ [cm] |
|---|---|---|
| 通電直後 | | |
| 30分後 | | |

## 2. 交換時間の対照

| 方式 | p50 [ms] | p95 [ms] | 短縮率(SS/DSのp50) |
|---|---|---|---|
| DS | | | — |
| SS | | | ______ %(目標: ≤ 70%) |

## 3. 判定(ss-twr-design.md §4の切替前提条件)

- [ ] ① σ ≤ 15 cmかつバイアス ≤ 10 cm(**CFO補償あり**と判断できる)
- [ ] ② 交換時間がDS比30% 以上短い
- [ ] ③ 同一ログ・リプレイでCEP50 ≤ 30 cmを維持(Step 2以降のログで確認)

**結論**: SS-TWRは成立 / 不成立(理由: )

## 転記先

- [ ] `docs/ss-twr-design.md` §2.2/§4 — CFO補償の有無と実測値を追記
- [ ] 成立の場合: 方式別biasテーブルの追加方針を決定(config拡張)
- [ ] Issue [#14](https://github.com/atinfinity/m5stamp_uwb_rtls/issues/14)のチェックリスト更新 → close

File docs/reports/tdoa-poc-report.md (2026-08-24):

# 実測レポート: TDoA PoC(Issue [#16](https://github.com/atinfinity/m5stamp_uwb_rtls/issues/16))

> このファイルをコピーして記入する。
> 手順: [firmware/README.md](../../firmware/README.md)「TDoA PoC」/ 設計: [tdoa-design.md](../tdoa-design.md) §6

## 測定条件

| 項目 | 記入 |
|---|---|
| 実施日 / 実施者 | |
| ノード構成(blink_tx / listenerの台数・アドレス・配置座標) | |
| FWコミット / ブリンク間隔 | |

## PoC-1: RXタイムスタンプ取得可否(2ノード)

- [ ] listenerが`src,seq,rx_ticks`を出力する
- [ ] `rx_ticks`がブリンクごとに**単調増加**している(周回 ~17.2 sを除く)
- [ ] seqの欠落率: ______ %(受信率の目安)

```
(listener 出力の先頭 20 行程度を貼付)
```

**PoC-1判定**: 成立 / 不成立(不成立の場合: 症状 = 同値が続く / 増加しない / その他: )

> 不成立の場合は`receiveFrame()`実装がタイムスタンプレジスタを上書きしている
> 可能性が高い。ライブラリ改造(受信直後の読出しをライブラリ内へ移す)の要否を判断する。

## PoC-2: 2アンカー無線同期(3ノード)

- 観測時間: ______ s / マスターブリンク共通受信: ______ 件

```
(sync_analysis.py の出力貼付)
クロック offset:
クロック drift :
残留 σ         :
```

- [ ] **σ < 2 ns**(≈ 60 cm相当、tdoa-design.md §6の2. の目標)
- σ が2〜10 nsの場合: TCXO化・ブリンク間隔短縮での改善余地を検討
- σ が桁で超過する場合: 水晶の短期安定度が支配的 → TDoA断念の根拠として記録

タグブリンク(任意、`--tag-src`):

- 補正後 Δt: 平均 ______ ns / σ ______ ns(≈ ______ cm)

**PoC-2判定**: 成立 / 不成立

## 転記先

- [ ] `docs/tdoa-design.md` §3(成立条件)へ実測値を追記(成立/不成立とも)
- [ ] 不成立の場合: §5(導入判断基準)に「断念」の記録と根拠を追記
- [ ] Issue [#16](https://github.com/atinfinity/m5stamp_uwb_rtls/issues/16)のチェックリスト更新 → close

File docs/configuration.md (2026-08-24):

# 構成カスタマイズガイド(アンカー・タグの台数と配置)

アンカー/タグの台数変更・アンカー配置の変更手順。**測位系の構成情報は
`server/config.yaml`に一元化**されており、サーバー・シミュレータ・仮想タグ・
リプレイはすべてここから追従する。ファームウェアに入るのは自ノードのアドレスだけ。

物理的な配置の設計指針(高さ・DOP・アンテナ取り回し)は基本設計
[rtls-design.md](rtls-design.md) §3.3、アドレス体系は §4.2を参照。

## 1. 座標系

- フロア左下が原点(0, 0)、x右・y上、単位[m]
- `floor.width_m` / `floor.height_m`がフロア寸法。セル矩形・アンカー座標はこの範囲内であること(起動時に検証され、不備は起動失敗になる)

## 2. アンカーを追加・移動する

`server/config.yaml`の2箇所を編集する:

```yaml
anchors:
  "0x0019": { x: 12.5, y: 50.0, z: 2.2, bias_mm: 0 }   # ① 追加 (実測座標を登録)
cells:
  C: { rect: [0, 25, 25, 50], anchors: ["0x0013", "0x0014", "0x0016", "0x0017", "0x0019"] }  # ② 担当セルへ組み込み
```

- **アドレス**: `0x0010`〜 の連番を使う(体系上12台 = `0x001B`まで。C++ ソルバーのテーブル上限は16)
- **座標**: レーザー距離計で測量した実座標(±3 cm目標)。`z`はアンカー高さ
- **bias_mm**: 校正オフセット(Step 1の実測で決定。未校正なら0)
- **セルへの登録**: アンカーは`cells`のどこかに入れて初めて測距に使われる。1セル4〜6台、
  最低3台(3台未満のセルは解算不可)。同じアンカーを複数セルで共有してよい
- 起動時検証: セルが未知のアンカーを参照 / 矩形がフロア外 / アドレス重複はエラーで起動しない

**ファームウェア側**: アンカーFWは自分のアドレスを知っているだけでよい。
1台ごとに`firmware/anchor/platformio.ini`の`-DNODE_ADDR=0x00XX`を書き換えて書き込む。

反映: サーバーを再起動するだけ。タグへの担当アンカー通知(ハンドオーバー)は
サーバーがretainedメッセージで自動配信する。

## 3. セル(分割)を変更する

- セルは軸平行矩形 + 担当アンカーリスト。フロア全域がどこかのセルに入るようにする
  (どのセルにも入らない座標は最近傍セルで補われるが、精度は落ちる)
- セル寸法の目安は15〜25 m四方(基本設計 §3.3)。境界のハンドオーバーには
  `tuning.handover_margin_m`(既定2 m)のヒステリシスが効く

小規模構成(1セル・アンカー4台)の例:

```yaml
floor: { width_m: 10.0, height_m: 10.0, tag_height_m: 1.0 }
anchors:
  "0x0010": { x: 0.0,  y: 0.0,  z: 2.0, bias_mm: 0 }
  "0x0011": { x: 10.0, y: 0.0,  z: 2.0, bias_mm: 0 }
  "0x0012": { x: 0.0,  y: 10.0, z: 2.0, bias_mm: 0 }
  "0x0013": { x: 10.0, y: 10.0, z: 2.0, bias_mm: 0 }
cells:
  A: { rect: [0, 0, 10, 10], anchors: ["0x0010", "0x0011", "0x0012", "0x0013"] }
tags: ["0x0001"]
```

## 4. タグを追加する

1. `config.yaml`の`tags`にアドレスを追加(`"0x0001"`〜`"0x0005"`)
2. タグFWを1台ごとに`-DNODE_ADDR=0x000X`でビルド・書き込み
   (`firmware/tag/platformio.ini`)

**5台が現行TDMA設計の上限**。スロット割当はアドレスから自動で決まる
(`firmware/lib/rtls_common/rtls_slots.h`: スーパーフレーム500 ms ÷ スロット100 ms)。
6台以上にするには次のいずれかが必要:

- スーパーフレームを伸ばす(`kSuperframeMs`を1000 msに → 10台 × 1 Hz)
- スロットを詰める(Step 1実測で交換時間を確認してから)
- SS-TWR化([ss-twr-design.md](ss-twr-design.md) — 8台 × 2 Hz相当)

逆にタグが2〜3台なら`kSlotPeriodMs`を150〜200 msに広げて更新レートを上げられる
(基本設計 §4.4)。**スロット定数を変えたら全タグを再書き込みし、
`firmware/test_native/run.sh`のスロットテストも更新する。**

## 5. 動作確認(実機レス)

変更後は仮想タグでそのまま検証できる(シミュレータはconfigの
タグ数・アンカー・セルに自動追従する):

```bash
uv run pytest tests/test_e2e_replay.py -s   # 変更後の構成で CEP を確認
uv run python -m server.app &               # + mosquitto + tools/virtual_tag.py
```

UI(http://localhost:8000)でアンカー配置とセル境界が意図どおりかを目視確認し、
アンカー監視パネルで全アンカーの測距が流れていることを確認する。

## 6. よくある失敗

| 症状 | 原因 |
|---|---|
| サーバーが起動しない(ValidationError) | セルが未登録アンカーを参照 / 矩形がフロア外 / アドレス重複 |
| 特定エリアでCOASTINGが多発 | そのセルの見通しアンカーが3台未満になっている。アンカー追加か配置変更 |
| セル境界で位置が飛ぶ | 隣接セルとアンカーを共有していない(基本設計 §3.3の共有配置にする) |
| 新タグの位置が出ない | `tags`への追加漏れ(サーバーは未知タグのrangesを破棄する)、またはFWの`NODE_ADDR`重複 |

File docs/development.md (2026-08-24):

# 開発環境構築手順

実機(M5Stamp C5 + Stamp UWB F)が無くても、測位サーバー・シミュレータ・ファームウェアのビルド検証まで全て動かせる。実機を使う手順は[firmware/README.md](../firmware/README.md)を参照。

## 1. 必要なツール

| ツール | 用途 | macOS | Ubuntu |
|---|---|---|---|
| [uv](https://docs.astral.sh/uv/) | Pythonパッケージ管理(必須) | `brew install uv` | `curl -LsSf https://astral.sh/uv/install.sh \| sh` |
| Mosquitto | MQTTブローカー(ライブ実行時) | `brew install mosquitto` | `sudo apt install mosquitto` |
| C++17コンパイラ | FW共通ロジックのネイティブテスト | `xcode-select --install` | `sudo apt install g++` |
| [PlatformIO](https://platformio.org/) | FWビルド(ESP32-C5) | `brew install platformio` | `uv tool install platformio` |
| ffmpeg | デモGIFの生成(任意) | `brew install ffmpeg` | `sudo apt install ffmpeg` |
| gh | Issue/PR操作(任意) | `brew install gh` | [cli.github.com](https://cli.github.com/) |

Python本体はuvが自動で用意する(`requires-python >= 3.12`。3.14で動作確認済み)。

## 2. セットアップ

```bash
git clone https://github.com/atinfinity/m5stamp_uwb_rtls.git
cd m5stamp_uwb_rtls
uv sync --all-extras     # .venv 作成 + 全依存 (mqtt/web extras + dev グループ)
```

## 3. テストを回す(CIと同じ内容)

```bash
uv run pytest                     # Python 全テスト (解算・セル・Web API・e2e 回帰・C++ 一致試験)
./firmware/test_native/run.sh     # FW 共通ロジック (スロット/JSON) + C++ ソルバーのホストテスト
pio run -d firmware/anchor        # アンカー FW の ESP32-C5 ビルド (実機不要、初回はツールチェーン取得で数分)
pio run -d firmware/tag           # タグ FW (本番 env:tag + 計測 env:tag_step1 の両方)
```

- `uv run pytest`には**C++ 一致試験**(`tests/test_cpp_parity.py`)が含まれ、`c++`コンパイラを使って
  `firmware/lib/rtls_solver`をビルド・実行する。Python実装とC++ 実装のどちらかだけを変更すると失敗する
  (tag-design.md §10の2. のルールをCIが強制)。

## 4. ライブ実行(仮想タグでend-to-end)

ターミナルを3つ使う:

```bash
# ① MQTT ブローカー
mosquitto

# ② 測位サーバー + Web UI
uv run python -m server.app --config server/config.yaml

# ③ 仮想タグ (シミュレータを実時間で MQTT へ流す)
uv run python tools/virtual_tag.py
```

ブラウザでhttp://localhost:8000を開くと、フロアマップにタグ位置・軌跡・真値(GT)・
棄却測距・監視パネルが表示される(凡例は画面下部)。

- タグ数・アンカー配置・チューニングは`server/config.yaml`で変更
- 仮想タグの劣化条件(NLoS率など)は`server/simulate.py`の`SimParams`を参照
- ポート競合時: `mosquitto -p 1899` + configの`mqtt.port`変更 + `--http-port 8099`

## 5. オフライン解析(シミュレータ → リプレイ)

```bash
uv run python tools/simulate.py --config server/config.yaml --duration-s 120 \
    --out logs/sim_ranges.jsonl --truth logs/sim_truth.jsonl
uv run python -m server.replay logs/sim_ranges.jsonl --out logs/positions.jsonl
```

チューニング(`config.yaml`の`tuning:`)を変えて同じJSONLをリプレイすれば、
実測なしでアルゴリズム変更を評価できる(server-design.md §8)。

## 6. リポジトリ構成の要点

```
docs/            設計書 (基本設計 rtls-design.md から辿れる)
server/          測位サーバー (Python) — pipeline は MQTT 非依存でテスト可能
firmware/
  anchor/ tag/   PlatformIO プロジェクト (ESP32-C5)
  lib/rtls_common/   ハード非依存の共有ロジック (TDMA スロット・ペイロード)
  lib/rtls_solver/   B案 C++ ソルバー (Python 実装と一致試験で同期)
  test_native/   ホストで走る C++ テスト
tools/           シミュレータ・仮想タグ・Step1 計測ツール
tests/           pytest (e2e 回帰・C++ 一致試験含む)
```

## 7. 開発フロー

1. Issueを立てる → `feature/...`ブランチを切る
2. 変更 + テスト(§3の4コマンドがローカルで通ること)
3. PRを作成 → CI(python / firmware-native / firmware ×2)がgreenになってからマージ
4. 解算アルゴリズムを触る場合は**PythonとC++ を必ず同時に変更**(一致試験が落ちる)

## トラブルシュート

| 症状 | 原因と対処 |
|---|---|
| ブラウザでUIが "disconnected" のまま | `uv sync --all-extras`を実行したか確認(WebSocketは`websockets`パッケージが必要。web extrasに含まれる) |
| `pio run`がboard不明で失敗 | pioarduino platformの取得失敗。ネットワークを確認して`pio run`を再実行(URLは各platformio.iniに記載) |
| 一致試験だけ失敗する | PythonかC++ の片側だけ解算を変更していないか確認。両方直すかrevertする |
| ポート1883/8000が使用中 | §4のポート変更手順を使う |

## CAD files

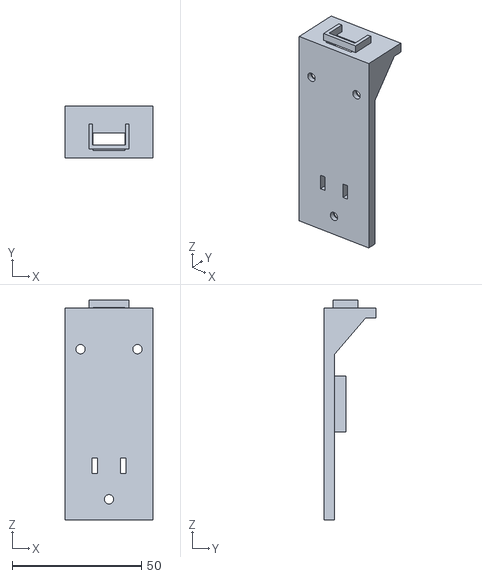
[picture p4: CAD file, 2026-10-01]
hardware/cad/stl/anchor_mount.stl
34.0 x 20.0 x 85.0

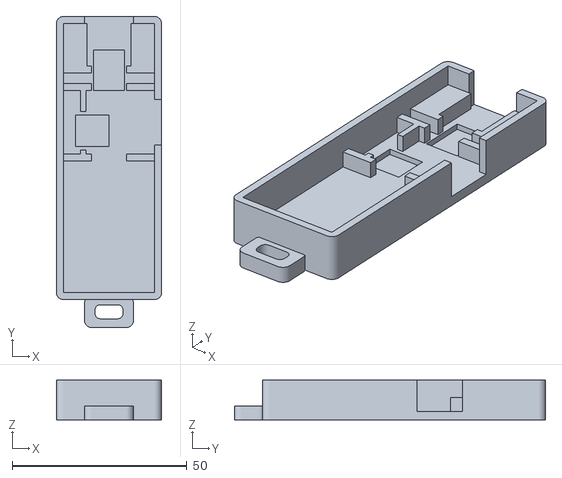
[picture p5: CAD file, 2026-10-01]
hardware/cad/stl/tag_case_body.stl
30.1 x 88.9 x 11.4

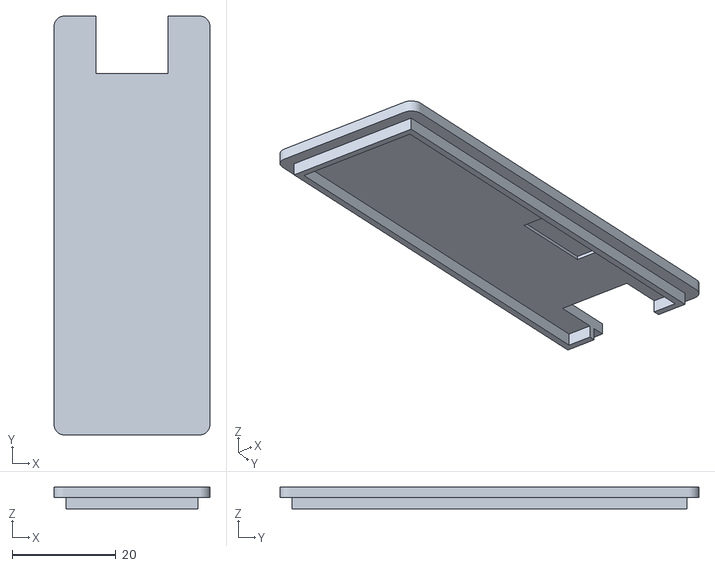
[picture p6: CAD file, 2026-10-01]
hardware/cad/stl/tag_case_lid.stl
30.1 x 80.9 x 4.20

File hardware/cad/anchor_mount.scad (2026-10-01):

// アンカー取付具(壁面・柱用 L ブラケット)
// - 垂直プレートを壁にネジ 3 本(皿 M3)で固定
// - プレート前面のポケットに M5Stamp C5、上部棚の上面ポケットに Stamp UWB F を置く
//   (固定は薄手の両面テープを想定)
// - UWB F のアンテナ端は棚の前縁側(壁と反対)を向き、前方に壁・部材が無い
// - FPC ケーブルはプレート前面の溝 → 棚のスリットを通して両ボードの背面コネクタへ
// 座標系は設置姿勢(y=0 が壁面、+y が壁から離れる向き、+z が上)
// 印刷時は背面(y=0 面)をベッドに向けて水平に寝かせる(サポート不要)

include <common.scad>

preview = false;  // true でプレビュー用に前面(ポケット側)をカメラへ向ける

plate_w = 34;    // プレート幅
plate_h = 78;    // プレート高さ
plate_t = 4;     // プレート厚
shelf_d = 20;    // 棚の奥行き(壁から)
shelf_t = 4;     // 棚厚
pock_wall = 2;   // C5 ポケット壁厚
pock_h = 4.5;    // C5 ポケット壁高さ
uwb_wall = 1.5;  // UWB ポケット壁厚
uwb_wall_h = 3;  // UWB ポケット壁高さ
chan_d = 1.2;    // FPC 溝深さ(C5 背面コネクタの突き出し 1.0 が収まる)

c5_px = c5_w + 2 * tol;   // C5 ポケット内寸(幅)
c5_pz = c5_l + 2 * tol;   // C5 ポケット内寸(高さ)
c5_z0 = 36;               // C5 ポケット下端の高さ
uwb_px = uwb_w + 2 * tol;
uwb_py = uwb_l + 2 * tol;
uwb_y0 = 5;               // UWB モジュール後端(壁側)の y 位置

module anchor_mount() {
    difference() {
        union() {
            // 垂直プレート
            cube_c([plate_w, plate_t, plate_h], cx = true);
            // 上部棚
            translate([0, 0, plate_h]) cube_c([plate_w, shelf_d, shelf_t], cx = true);
            // ガセット(棚の補強) x2
            for (sx = [-1, 1])
                translate([sx * plate_w / 2 - (sx < 0 ? 0 : 3), 0, 0])
                    gusset();
            // C5 ポケット壁(上辺なし・下辺は USB 用に中央が開く)
            translate([0, plate_t, 0]) c5_pocket_walls();
            // UWB ポケット壁(前辺なし = アンテナ側オープン)
            translate([0, 0, plate_h + shelf_t]) uwb_pocket_walls();
        }
        // ネジ穴(皿 M3): 下 1 + 上 2。ざぐりは前面(+y)側
        for (p = [[0, 8], [-11, 66], [11, 66]])
            translate([p[0], 0, p[1]]) rotate([-90, 0, 0]) screw_hole(plate_t);
        // FPC 溝(プレート前面、C5 ポケット床から上端まで)
        translate([-fpc_w / 2, plate_t - chan_d, c5_z0]) cube([fpc_w, chan_d + 0.1, plate_h - c5_z0 + 0.1]);
        // FPC スリット(棚を貫通し UWB モジュール後端の下へ。背面コネクタ全体が収まる奥行き)
        slit_y1 = uwb_y0 + tol + uwb_conn_l + 0.5;
        translate([-fpc_w / 2, plate_t - chan_d, plate_h - 0.1]) cube([fpc_w, slit_y1 - (plate_t - chan_d), shelf_t + 0.2]);
        // ケーブルタイ用スリット x2(USB ケーブルの張力止め)
        for (sx = [-1, 1])
            translate([sx * 5.5 - 1.1, -0.1, 18]) cube([2.2, plate_t + 0.2, 6]);
    }
}

// 中央下端揃えの cube
module cube_c(size, cx = false) {
    translate([cx ? -size[0] / 2 : 0, 0, 0]) cube(size);
}

module gusset() {
    rotate([90, 0, 90]) linear_extrude(3)
        polygon([[plate_t, plate_h], [16, plate_h], [plate_t, plate_h - 14]]);
}

module c5_pocket_walls() {
    ox = c5_px / 2 + pock_wall;    // 外周半幅
    usb_gap = 13;
    // 側壁
    for (sx = [-1, 1])
        translate([sx * c5_px / 2 - (sx < 0 ? pock_wall : 0), 0, c5_z0 - pock_wall])
            cube([pock_wall, pock_h, c5_pz + pock_wall]);
    // 下壁(中央 usb_gap を開ける)
    for (sx = [-1, 1])
        translate([sx < 0 ? -ox : usb_gap / 2, 0, c5_z0 - pock_wall])
            cube([ox - usb_gap / 2, pock_h, pock_wall]);
}

module uwb_pocket_walls() {
    // 後壁(壁側)
    translate([-uwb_px / 2 - uwb_wall, uwb_y0 - uwb_wall, 0])
        cube([uwb_px + 2 * uwb_wall, uwb_wall, uwb_wall_h]);
    // 側壁(後半のみ。前方 = アンテナ側はオープン)
    for (sx = [-1, 1])
        translate([sx * uwb_px / 2 - (sx < 0 ? uwb_wall : 0), uwb_y0 - uwb_wall, 0])
            cube([uwb_wall, 8 + uwb_wall, uwb_wall_h]);
}

if (preview) rotate([0, 0, 180]) anchor_mount();
else anchor_mount();

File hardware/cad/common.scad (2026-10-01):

// 共通パラメータ: M5Stamp C5 DIP / M5Stamp UWB F の寸法(mm)
// 出典: 公式ドキュメントの寸法図(Model Size)
//   docs.m5stack.com/en/core/Stamp-C5_DIP   (S016-DIP-Stamp-C5_DIP_model_size)
//   docs.m5stack.com/en/stamp/stamp_uwb_f    (S017-F-Stamp_UWB_F_model_size)
// ストア公称値(C5: 17.6 x 19.1 x 3.4 / UWB F: 11.5 x 12.0 x 2.8)とも一致。
// 部品内の位置(コネクタ等)は寸法図からの読み取り値(±0.3 程度)。
// 注意: 実機でのフィット確認は未実施。印刷後に確認し、tol を調整すること。
// C5 は DIP 版付属のピンヘッダをはんだ付けしない前提(付けると厚みが増して収まらない)。

// --- M5Stamp C5 DIP ---
// 座標 u: USB-C と反対の端(PCB 端)から USB-C 方向、v: VBAT 側の長辺から反対側の長辺方向(部品面から見る)
c5_w = 17.6;    // 幅(v 方向)
c5_l = 19.06;   // 長さ(u 方向)。PCB 18.0 + USB-C の突き出し 1.06
c5_t = 3.36;    // PCB 下面から部品面シールド上面まで
c5_conn_h = 1.0;            // 背面 FPC コネクタの PCB 下面からの突き出し
c5_conn_u = [1.7, 5.8];     // 背面 FPC コネクタの u 範囲。ケーブルは u=0 側(USB と反対の端)へ出る
c5_conn_v = [2.4, 10.3];    // 同 v 範囲(VBAT 側へ寄っている)
c5_ipex = [2.1, 13.3];      // 部品面の IPEX-1(Wi-Fi アンテナ)中心 [u, v]
c5_vbat_u = 11.6;           // VBAT パッド(v=1.05 の列)の u。GND は 16.75

// --- M5Stamp UWB F ---
// アンテナ(PCB アンテナ、シールドなし部分)は長さ方向の片端。FPC コネクタは反対端の背面
uwb_w = 12.02;  // 幅
uwb_l = 11.53;  // 長さ(片端がアンテナ部)
uwb_t = 1.62;   // PCB 下面からシールド上面まで
uwb_conn_h = 1.2;    // 背面 FPC コネクタの突き出し
uwb_conn_w = 8.0;    // 同 幅(幅方向中央)
uwb_conn_l = 3.8;    // 同 長さ(アンテナと反対端から)。ケーブルはこの端から出る
uwb_ant_l = 3.7;     // アンテナ部の長さ(アンテナ端から)。FPC をこの下に通さない(公式の注意)

// C5 同梱の Wi-Fi 用 FPC アンテナ(2.4/5 GHz、IPEX-1、ケーブル長 50 mm)
// 出典: docs.m5stack.com/en/core/Stamp-C5
wifi_ant_w = 14.3;  // 長さ
wifi_ant_h = 5.3;   // 幅

tol = 0.3;     // 片側クリアランス(ポケット寸法 = 部品寸法 + 2*tol)

fpc_w = 12.5;  // FPC 溝・スリットの幅(ケーブル幅 約 6.5 + コネクタ位置の振れ代)

$fn = 48;

// ざぐり付きネジ穴(皿ネジ M3 想定)。h = 板厚
module screw_hole(h, d = 3.6, head_d = 7, head_h = 2) {
    translate([0, 0, -0.1]) cylinder(d = d, h = h + 0.2);
    translate([0, 0, h - head_h]) cylinder(d1 = d, d2 = head_d, h = head_h + 0.1);
}

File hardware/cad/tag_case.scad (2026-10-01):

// タグ用ケース(本体 + 摩擦嵌合フタの 2 部品)
// 内部レイアウト(長手方向 +y): LiPo バッテリー | M5Stamp C5 | FPC 折り返し部 | Stamp UWB F
// - 両ボードとも部品面を上にして置く。背面 FPC コネクタは床の凹みに収まる
// - C5 は USB-C を +x 側壁に突き当て(側壁スロットから充電・書き込み)、VBAT/GND パッドの列が
//   バッテリー側を向く。背面 FPC コネクタのケーブルは -x 端へ出るので、-x 側の空きで立ち上げて
//   C5 の上を +y へ渡し、折り返し部で床に下ろして UWB F のコネクタへ差す
// - UWB F のアンテナ端はケース端の開口(アンテナ窓)に向き、樹脂で覆わない。床の溝は
//   アンテナ部の下まで延ばさない(FPC をアンテナ下に通さない: 公式の注意)
// - C5 の Wi-Fi 用 FPC アンテナはフタ裏の凹み(C5 の上、+x 寄り)に貼る。FPC ケーブル・UWB F・LiPo から離す
// - バッテリー端には ストラップループ
// 印刷: 本体は底面、フタは天面をベッドに向ける(どちらもサポート不要)
// part = "body" | "lid" | "preview"(本体 + 浮かせたフタ)

include <common.scad>

part = "preview";

bat = [25.5, 37, 5.2];  // LiPo 公称 [幅, 長さ, 厚み](例: DPTL-DTP502535 400 mAh)。要実測調整

wall = 2;       // 側壁厚
floor_t = 2.4;  // 底厚
cavity_d = 9;   // 内寸深さ
rib = 2;        // 仕切り壁厚
rail_h = 4;     // 仕切り・レール高さ
chan_d = 1.4;   // 床の FPC/配線溝の深さ
lid_t = 2;      // フタ厚
skirt_h = 2.2;  // フタのスカート(嵌合部)高さ
win_w = 14;     // アンテナ窓の幅
ant_d = 0.6;    // フタ裏の Wi-Fi アンテナ用凹みの深さ
bay = 3;        // FPC 折り返し部(C5 と UWB F の間でケーブルを床へ下ろす)の長さ
usb_w = 13;     // USB-C スロット幅(プラグのモールド部が通る幅)
stop_w = 1.5;   // C5 の -x 側ストッパー厚
uwb_ch_w = uwb_conn_w + 1;  // UWB 側の床溝の幅

iw = bat[0] + 2 * tol;                  // 内寸幅(バッテリー幅で決まる)
bat_l  = bat[1] + 2 * tol;
c5_zone  = c5_w + 2 * tol;              // C5 は長さ(19.06)を幅方向に置く → USB-C が +x 側壁を向く
uwb_zone = uwb_l + 2 * tol;

c5_y0  = bat_l + rib;                   // C5 ゾーン開始 y(内寸座標)
uwb_y0 = c5_y0 + c5_zone + rib + bay + rib;   // UWB ゾーン開始 y
il = uwb_y0 + uwb_zone;                 // 内寸長さ
ol = il + 2 * wall;
ow = iw + 2 * wall;
oh = floor_t + cavity_d;

c5_x0 = iw - (c5_l + 2 * tol);          // C5 ポケット -x 端(USB-C 側は側壁まで)
c5_u0 = c5_x0 + tol;                    // C5 の u=0(PCB 端)の x
c5_v0 = c5_y0 + tol;                    // C5 の v=0(VBAT 側の辺)の y

module rounded_box(size, r = 2) {
    hull() for (x = [r, size[0] - r], y = [r, size[1] - r])
        translate([x, y, 0]) cylinder(r = r, h = size[2]);
}

// 原点: 内寸の左下(x は中央揃えでなく壁内側)。外形は [-wall, -wall] から
module body() {
    difference() {
        union() {
            translate([-wall, -wall, 0]) rounded_box([ow, ol, oh]);
            // ストラップループ(バッテリー端の外側)
            translate([iw / 2 - 7, -wall - 8, 0]) loop_bar();
        }
        // キャビティ
        translate([0, 0, floor_t]) cube([iw, il, cavity_d + 0.1]);
        // C5 背面 FPC コネクタの凹み(-x 側の空きまで延ばし、ケーブルを床面近くで引き出せるようにする)
        translate([c5_x0 - 3, c5_v0 + c5_conn_v[0] - 0.5, floor_t - chan_d])
            cube([c5_u0 + c5_conn_u[1] + 0.5 - (c5_x0 - 3), c5_conn_v[1] - c5_conn_v[0] + 1, chan_d + 0.1]);
        // UWB 側の床溝(折り返し部 → UWB F 背面コネクタ。アンテナ部の下までは延ばさない)
        translate([iw / 2 - uwb_ch_w / 2, c5_y0 + c5_zone, floor_t - chan_d])
            cube([uwb_ch_w, uwb_y0 + tol + uwb_conn_l + 0.5 - (c5_y0 + c5_zone), chan_d + 0.1]);
        // USB-C スロット(+x 側壁、C5 の幅中央)
        translate([iw - 0.1, c5_v0 + c5_w / 2 - usb_w / 2, floor_t])
            cube([wall + 0.2, usb_w, cavity_d + 0.1]);
        // アンテナ窓(UWB 端の壁を全高で開口)
        translate([iw / 2 - win_w / 2, il - 0.1, floor_t])
            cube([win_w, wall + 0.2, cavity_d + 0.1]);
    }
    // 仕切り(側方スタブのみ。中央はバッテリー配線 / FPC の通り道)
    divider(bat_l, gap = 10);
    divider(c5_y0 + c5_zone, gap = 10);
    divider(uwb_y0 - rib, gap = uwb_ch_w + 1);
    // C5 の -x 側ストッパー(FPC の引き出し範囲を避けて 2 か所)
    c5_stop(c5_y0, c5_v0 + c5_conn_v[0] - 1.5);
    c5_stop(c5_v0 + c5_conn_v[1] + 1.5, c5_y0 + c5_zone);
    // UWB センタリングレール(→ ポケット 12.62)
    rails(uwb_y0, uwb_zone, (iw - (uwb_w + 2 * tol)) / 2);
}

module c5_stop(y0, y1) {
    translate([c5_x0 - stop_w, y0, floor_t]) cube([stop_w, y1 - y0, rail_h]);
}

module divider(y0, gap) {
    for (sx = [0, 1])
        translate([sx == 0 ? 0 : iw / 2 + gap / 2, y0, floor_t])
            cube([iw / 2 - gap / 2, rib, rail_h]);
}

module rails(y0, len, w) {
    for (sx = [0, 1])
        translate([sx == 0 ? 0 : iw - w, y0, floor_t])
            cube([w, len, rail_h]);
}

module loop_bar() {
    difference() {
        rounded_box([14, 9, 4], r = 2);
        translate([3, 2.5, -0.1]) rounded_box([8, 4, 4.2], r = 1.5);
    }
}

module lid() {
    difference() {
        union() {
            translate([-wall, -wall, oh]) rounded_box([ow, ol, lid_t]);
            // スカート(キャビティに摩擦嵌合)
            translate([0, 0, oh - skirt_h]) difference() {
                translate([tol, tol, 0]) cube([iw - 2 * tol, il - 2 * tol, skirt_h]);
                translate([tol + 1.2, tol + 1.2, -0.1]) cube([iw - 2 * tol - 2.4, il - 2 * tol - 2.4, skirt_h + 0.2]);
            }
        }
        // アンテナ窓(UWB アンテナ上面を開放。端の壁開口とつながる)
        translate([iw / 2 - win_w / 2, uwb_y0 + 3, oh - skirt_h - 0.1])
            cube([win_w, il - (uwb_y0 + 3) + wall + 0.1, skirt_h + lid_t + 0.2]);
        // Wi-Fi アンテナ用の凹み(フタ裏、C5 の上の +x 寄り。長辺を y 方向に置き、
        // C5 の上を渡る FPC ケーブル(幅中央付近)から離す)
        translate([iw - tol - 1.5 - (wifi_ant_h + 2 * tol),
                   c5_v0 + c5_w / 2 - (wifi_ant_w + 2 * tol) / 2, oh - 0.1])
            cube([wifi_ant_h + 2 * tol, wifi_ant_w + 2 * tol, ant_d + 0.1]);
        // USB スロット上の逃げ(フタを閉めたままケーブルを挿せる)
        translate([iw - 0.1, c5_v0 + c5_w / 2 - usb_w / 2, oh - skirt_h - 0.1])
            cube([wall + 0.2, usb_w, skirt_h + 0.1]);
    }
}

if (part == "body") body();
else if (part == "lid") lid();
else {
    body();
    translate([0, 0, 14]) lid();
}

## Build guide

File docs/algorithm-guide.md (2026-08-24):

# 測位アルゴリズム開発ガイド

解算パイプライン(補正・外れ値除去・ソルバー・フィルタ)を改良するためのガイド。
**実機は不要** — 開発ループはすべてシミュレータとリプレイで回る。

- 仕様の正: [server-design.md](server-design.md) §5(処理段)/ [tag-design.md](tag-design.md) §4(C++ 差分)
- 環境構築: [development.md](development.md)

## 1. アルゴリズムはどこにあるか

同じアルゴリズムが**2実装**ある。挙動を変える変更は必ず両方に入れる(§5)。

| 処理段 | Python (A案・正) | C++ (B案・タグ上) |
|---|---|---|
| 高低差補正 | `server/positioning/geometry.py` | `firmware/lib/rtls_solver/geometry.hpp` |
| ゲーティング | `server/positioning/outlier.py` | `firmware/lib/rtls_solver/outlier.hpp` |
| 最小二乗ソルバー | `geometry.py: solve_2d` | `geometry.hpp: solve2d` |
| カルマンフィルタ | `server/positioning/kalman.py` | `firmware/lib/rtls_solver/kalman.hpp` |
| パイプライン統合・状態機械・leave-one-out | `server/positioning/pipeline.py` | `firmware/lib/rtls_solver/pipeline.hpp` |
| チューニングパラメータ | `server/config.yaml`の`tuning:` | `pipeline.hpp: struct Tuning`(既定値を一致させる) |

**まずPythonで開発し、確定してからC++ へ移植する**のが基本フロー(tag-design.md §11)。

## 2. 開発ループ(シミュレータ → リプレイ → 評価)

すべて決定的(seed固定)なので、変更の効果を再現可能に比較できる。

```bash
# ① 合成データを一度だけ生成(真値付き)
uv run python tools/simulate.py --config server/config.yaml --duration-s 300 \
    --seed 42 --out logs/dev_ranges.jsonl --truth logs/dev_truth.jsonl

# ② アルゴリズムや config.yaml の tuning を変更

# ③ リプレイして評価
uv run python -m server.replay logs/dev_ranges.jsonl --out logs/dev_positions.jsonl
```

評価(CEPなど)はテストと同じ指標を使う。ワンライナー:

```bash
uv run python - <<'EOF'
import json, math
truth = {}
for l in open("logs/dev_truth.jsonl"):
    d = json.loads(l); truth[(d["tag"], d["t_ms"])] = (d["x"], d["y"])
errs = []
for l in open("logs/dev_positions.jsonl"):
    d = json.loads(l)
    if d["state"] != "TRACKING": continue
    t = truth.get((d["tag"], d["t_ms"]))
    if t: errs.append(math.hypot(d["x_m"]-t[0], d["y_m"]-t[1]))
errs.sort(); n = len(errs)
print(f"n={n} CEP50={errs[n//2]*100:.1f}cm CEP95={errs[int(n*.95)]*100:.1f}cm max={errs[-1]*100:.1f}cm")
EOF
```

劣悪条件での頑健性は`SimParams`を振って確認する(`tools/simulate.py --nlos-prob 0.2 --dropout-prob 0.1`等)。
チューニングのグリッド探索は **`tools/sweep.py`** で自動化できる
(`--param tuning.residual_gate_m=0.3,0.5,0.7`の直積を一括評価しCEP表を出力。真値なしの実測ログにも対応)。
テストスイートにも同じ回帰が入っている: `uv run pytest tests/test_e2e_replay.py -s`(CEPをprintする)。

## 3. 変更の種類別ガイド

### チューニングのみ(コード変更なし)

`server/config.yaml`の`tuning:`を変えてリプレイ。対象: ゲート幅(`v_max_ms`, `gate_margin_m`)、
外れ値閾値(`residual_gate_m`)、フィルタ雑音(`sigma_a`, `sigma_m_floor`)、状態遷移(`stale_sec`, `lost_sec`)。
確定値はC++ の`Tuning`既定値にも反映する。

### フィルタの変更(例: CAモデル、適応ノイズ)

`kalman.py`を変更 → `tests/test_kalman.py`を更新 → §2で効果を確認 → `kalman.hpp`へ移植。
インターフェース(`init/predict/update/state`)を保てばpipeline側は無変更で済む。

### ソルバーの変更(例: 重み付け変更、3D化)

`geometry.solve_2d`を変更。縮退検出(共線)と発散ガードを外さないこと。
C++ 側`solve2d`はscipyが使えないためIRLSで近似している — 反復条件を変えると一致試験の
乖離が広がるので、変更後に §5の許容値を実測し直す。

### 外れ値除去・状態機械の変更

`pipeline.py`の`_usable_ranges` / `_solve` / `process`。状態機械
(INIT/TRACKING/COASTING/STALE/LOST)を変える場合は`tests/test_pipeline.py`の
該当ケース(欠測・重複seq・鮮度・タグ再起動・LOST再捕捉)を必ず更新する。

### 観測モデル自体の変更(TDoA化など)

pipelineの入出力型(`RangeSet` → `Position`)を保てばサーバー側(MQTT/UI)は無変更で動く。
大規模変更は設計書([tdoa-design.md](tdoa-design.md)等)を先に更新する。

## 4. 品質ゲート(変更を出す前に)

```bash
uv run pytest                     # 単体 + e2e 回帰 + C++ 一致試験
./firmware/test_native/run.sh     # C++ 側の単体テスト
```

受入基準(server-design.md §13): 標準条件でCEP50 ≤ 0.30 m、TRACKING中の1エポック2 m超ジャンプなし、
NLoS 20% でもCEP50 ≤ 0.5 m。現状の実力はCEP50 ≈ 4–5 cmなので、**明確な理由なく悪化させない**。

## 5. Python / C++ 一致試験のルール

`tests/test_cpp_parity.py`が同一入力に対する両実装の出力を突き合わせる
(許容: 中央値 ≤ 1 cm・p99 ≤ 2 cm・最大 ≤ 10 cm・状態一致 ≥ 99%、tag-design.md §10の2.)。

- **片側だけ変更するとCIが落ちる**。これは仕様(意図的なガード)
- 正当な変更で許容値を超える場合: 両実装を修正 → 乖離を実測 → 妥当なら
  tag-design.md §10の2. の許容値とtestの閾値を実測値ベースで更新(コミットメッセージに根拠を書く)

## 6. 実測データでの開発(実機導入後)

サーバーは受信した生距離を`logs/ranges-YYYYMMDD.jsonl`に常時記録している(recorder)。
実測ログはそのまま §2のリプレイに入る — **アルゴリズム変更の評価に実機の再測定は不要**。
代表シーンのログを`tests/fixtures/`に置き、回帰テスト化するのがStep 2以降の運用
(server-design.md §13の3.)。アンカー別バイアス校正は`config.yaml`の`bias_mm`(基本設計 §6)。

## チェックリスト

- [ ] PythonとC++ の両方を変更した(または挙動に影響しないことを確認した)
- [ ] `uv run pytest`と`./firmware/test_native/run.sh`が通る
- [ ] 標準条件 + 劣悪条件(NLoS 20%)のリプレイでCEPが悪化していない
- [ ] チューニング既定値を変えた場合、config.yamlとC++ `Tuning`の両方を更新した
- [ ] 設計書と実装が乖離する変更は設計書側も更新した

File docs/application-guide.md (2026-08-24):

# アプリケーション開発ガイド(測位結果の利用)

測位結果(タグの座標)を使うアプリケーションを作るためのガイド。
**サーバー・タグに手を入れず、購読者を追加するだけ**で開発できる(A案設計の狙い、server-design.md §5)。
実機がなくても仮想タグ([development.md](development.md) §4)で全インターフェースが動く。

## 1. 取得インターフェースの選択

| インターフェース | 主な用途 | 特徴 |
|---|---|---|
| **MQTT** `rtls/tag/{addr}/position` | 機械間連携・常駐アプリ(推奨) | push型、購読者をいくつでも追加可、QoS0・retainなし |
| WebSocket `ws://<server>:8000/ws` | Web UI・ダッシュボード | position / stats(2秒毎)/ truth(開発時)の3種をpush |
| REST `GET /api/tags`ほか | スナップショット取得・ヘルスチェック | ポーリング型。`/api/floor`(アンカー・セル定義)、`/api/stats`(監視統計) |
| UARTバイナリ(B案) | ロボット搭載(ROS等) | タグ上計算の座標を30 byte固定フレームで直結。[tag-design.md](tag-design.md) §7 |

## 2. positionメッセージ仕様

トピック: `rtls/tag/{addr}/position`(例`rtls/tag/0x0001/position`)。ペイロード:

```json
{"tag": "0x0001", "t_ms": 1755212345690,
 "x_m": 12.34, "y_m": 8.76, "vx_ms": 0.51, "vy_ms": -0.12,
 "quality": {"n_anchors": 4, "residual_m": 0.03},
 "anchors_used": ["0x0010", "0x0011", "0x0013", "0x0014"],
 "anchors_rejected": [],
 "cell": "A", "state": "TRACKING"}
```

| フィールド | 意味 |
|---|---|
| `t_ms` | タグ側の測距時刻(SNTP同期済みUNIX ms)。**受信時刻ではなくこちらを使う** |
| `x_m`, `y_m` | フロア座標[m]。原点はフロア左下、x右・y上(`/api/floor`の寸法内) |
| `vx_ms`, `vy_ms` | カルマン推定速度[m/s] |
| `quality.n_anchors` | 解算に使った距離数(COASTINGでは0) |
| `quality.residual_m` | 解算のRMS残差[m] — 測位の信頼度指標 |
| `anchors_used` / `anchors_rejected` | 使用 / 棄却(NLoS・ゲート)されたアンカー |
| `cell` | 現在のセル(ヒステリシス付き判定) |
| `state` | 追尾状態(下表) |

### stateの扱い(重要)

| state | 意味 | アプリでの扱いの定石 |
|---|---|---|
| `TRACKING` | 通常追尾(このエポックで解算成功) | すべての用途に使用可 |
| `COASTING` | 当該エポック欠測、カルマン予測のみ | 表示は可。**トリガ(ジオフェンス等)には使わない** |
| `STALE` | 2秒以上解算なし | 警告表示。位置は古い予測 |
| `LOST` | 10秒以上解算なし | 非表示にし「所在不明」として扱う |

### 品質ゲートの定石

クリティカルな判定(入退場、衝突警告など)は`state == "TRACKING"`かつ
`residual_m`が閾値以下(目安0.5 m)のエポックだけで行う。
レイテンシ(測距からpositionのpublishまで)はWi-Fi + ブローカー + 解算で20〜60 ms程度の見積もり(server-design.md §14。実機では未計測)。

## 3. サンプルコード([examples/](../examples/))

どちらも仮想タグ環境でそのまま動作確認できる(実行例は各ファイル冒頭)。

- **[mqtt_subscriber.py](../examples/mqtt_subscriber.py)** — 最小の購読アプリ。
  positionを購読して整形表示するだけの雛形
- **[geofence.py](../examples/geofence.py)** — 領域入退場検知。
  「TRACKINGのみでトリガ」「品質ゲート」「退場ヒステリシス」というアプリ側の定石3点を実装した実例

```bash
# development.md §4 のスタック (mosquitto + server + virtual_tag) を起動した上で:
uv run python examples/mqtt_subscriber.py
uv run python examples/geofence.py --zone 0,0,25,25   # セル A への入退場を監視
```

ブラウザ側で使う場合(WebSocket)は`server/web/static/index.html`の
`connectWs()`がそのまま参考実装になる(`{"type":"position", ...}`をJSONで受ける)。

## 4. その他のトピック

| トピック | retain | 内容 |
|---|---|---|
| `rtls/tag/{addr}/ranges` | no | 生距離(アプリでは通常不要。独自解析やログ用) |
| `rtls/tag/{addr}/anchors` | **yes** | サーバー→タグの担当アンカー指示。**アプリは購読してよいがpublishしない** |
| `rtls/sim/truth` | no | 仮想タグの真値(開発時のみ流れる)。精度評価アプリに利用可 |

## 5. 作法と注意

- **`rtls/`名前空間へpublishしない**(購読のみ)。アプリ独自のトピックは別名前空間に置く
- positionはretainされないため、起動直後の初期状態は`GET /api/tags`で取得してから購読に切り替えるとよい(UIと同じパターン)
- タグの追加・アンカー配置変更はサーバーの`config.yaml`だけで完結する。アプリはアドレスをハードコードせず`/api/floor`の`tags`を参照する
- 座標系はフロアローカル[m]。建物図面等への変換(回転・平行移動)はアプリ側の責務
- 複数アプリの同時購読は自由(MQTTのpub/subがそのために選ばれている — 基本設計 §4.6)

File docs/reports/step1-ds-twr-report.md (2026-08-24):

# Step 1実測レポート: DS-TWR 1対1測距(Issue [#1](https://github.com/atinfinity/m5stamp_uwb_rtls/issues/1))

> このファイルをコピーして記入する(例: `docs/reports/2026-XX-XX-step1.md`)。
> 手順: [firmware/README.md](../../firmware/README.md)「Step 1」/ 設計: [ds-twr-design.md](../ds-twr-design.md) §6

## 測定条件

| 項目 | 記入 |
|---|---|
| 実施日 / 実施者 | |
| 場所(環境: 屋内/屋外、床材、周辺の金属) | |
| 技適確認(番号or特例届出) | |
| ハードウェア(ロット、アンテナ取付方法、高さ) | |
| FWコミット / タイミング設定(`kDsResponseTxDelayUus`等) | |
| 気温 / 通電からの経過時間 | |

## 1. 静的精度(各距離1000回)

`analyze.py`の出力を距離ごとに貼り付け:

| 真値[m] | 成功率[%] | 平均[m] | bias [cm] | σ [cm] | 備考 |
|---|---|---|---|---|---|
| 1.000 | | | | | |
| 5.000 | | | | | |
| 10.000 | | | | | |
| 20.000 | | | | | |
| 40.000 | | | | | |

```
(analyze.py の生出力貼付欄)
```

- [ ] 受入: 校正後 |平均誤差| ≤ 5 cm(全距離)
- [ ] 受入: σ ≤ 10 cm(全距離)
- [ ] biasの距離依存性の有無を確認した(あれば一次補正を検討)

## 2. タイミング実測

| 設定`kDsResponseTxDelayUus` | 成功率[%] | 交換時間p50 [ms] | p95 [ms] | p99 [ms] |
|---|---|---|---|---|
| 3000(既定) | | | | |
| 1500 | | | | |
| (最小探索値) | | | | |

- [ ] 「成功率99% を保てる最小値」を特定した: ______ µs

## 2b. アンカー間ギャップ(4アンカー巡回、ds-twr-design.md §6の5.)

`tag_step1`を`-DTARGET_ANCHORS=…`(4台)でビルドし、`INTER_ANCHOR_GAP_MS`を振る。`analyze.py`のアンカー別成功率とサイクル時間を転記:

| `INTER_ANCHOR_GAP_MS` | 成功率[%](全体 / 最悪アンカー) | `RangeFrameMismatch`件数 | サイクル時間p50 [ms] | p95 [ms] |
|---|---|---|---|---|
| 0 | | | | |
| 2(既定) | | | | |
| 5 | | | | |
| 20(公式例) | | | | |

- [ ] 成功率を落とさない最小ギャップ: ______ ms → `kDsInterAnchorGapMs`へ
- [ ] 4アンカー分のサイクルp95がスロット有効幅90 msに収まる(収まらない場合: リトライ回数かアンカー数を調整)

## 3. 成功率vs距離(実効レンジ)

| 距離[m] | 成功率[%] |
|---|---|
| 5 / 10 / 15 / 20 / 25 / 30 / 35 / 40 / 45 / 50 | |

- 実効レンジ(成功率95% 維持): ______ m → セル寸法15〜25 mの妥当性: OK / NG

## 4. 干渉試験

- [ ] 2タグ同時Pollで誤距離が出ない(全て失敗=タイムアウトになる)ことを確認

## 転記先(完了したらチェック)

- [ ] `firmware/lib/rtls_common/rtls_common.h` — DS-TWRタイミング定数を確定値へ
- [ ] `server/config.yaml` — アンカー別`bias_mm`
- [ ] `docs/ds-twr-design.md` §3.3 — タイミングパラメータ表を実測値へ
- [ ] `docs/rtls-design.md` §4.4 — TDMAスロット幅の根拠(交換時間p95)
- [ ] Issue [#1](https://github.com/atinfinity/m5stamp_uwb_rtls/issues/1)のチェックリスト更新 → close

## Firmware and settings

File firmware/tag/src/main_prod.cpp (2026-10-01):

// タグ FW 本番モード (Step 2/3 + B案タグ上計算, Issue #6/#28)
//
// 動作 (rtls-design.md §4.4, §4.9 / tag-design.md §2〜§7):
//   - Wi-Fi + SNTP (5 分毎スムーズ補正) で実時刻を持ち、TDMA スロットで測距
//   - rtls/config/anchors・rtls/config/tuning (retained, version 付き) を受信して
//     NVS へ永続化し、rtls_solver によるタグ上解算とオンボードセル選択を行う
//   - 動作モード (NVS 永続、シリアルコマンド "mode <M>" で切替):
//       HYBRID     … ranges + position を MQTT へ (既定。A案サーバーと併用可)
//       QUIET      … position のみ MQTT へ
//       STANDALONE … UART バイナリフレームのみ (tag-design.md §7)
//   - 設定未受信のうちは解算せず ranges 送信のみ (A案互換で動作)
//   - SNTP 未同期時は kSuperframeMs 周期のフリーラン (単一タグ前提のフォールバック)
//
// ビルド設定 (platformio.ini): WIFI_SSID / WIFI_PASS / MQTT_HOST / SNTP_SERVER /
//   NODE_ADDR / RTLS_UART_TX / RTLS_UART_RX
#include <Arduino.h>
#include <M5Stamp_UWB.h>
#include <PubSubClient.h>
#include <WiFi.h>
#include <esp_sntp.h>
#include <sys/time.h>

#include <rtls_common.h>
#include <rtls_config_msg.h>
#include <rtls_msg.h>
#include <rtls_slots.h>

#include <pipeline.hpp>  // rtls_solver

#include "config_store.h"

#ifndef NODE_ADDR
#define NODE_ADDR 0x0001
#endif
#ifndef WIFI_SSID
#define WIFI_SSID "rtls-ap"
#endif
#ifndef WIFI_PASS
#define WIFI_PASS "rtls-pass"
#endif
#ifndef MQTT_HOST
#define MQTT_HOST "192.168.1.10"
#endif
#ifndef MQTT_PORT
#define MQTT_PORT 1883
#endif
#ifndef SNTP_SERVER
#define SNTP_SERVER MQTT_HOST  // 既定: 測位サーバーホストの chrony (§4.9)
#endif
#ifndef RTLS_UART_TX
#define RTLS_UART_TX -1  // -1 = Serial1 の既定ピン
#endif
#ifndef RTLS_UART_RX
#define RTLS_UART_RX -1
#endif

static constexpr size_t kRangePerCycle   = 4;
static constexpr uint32_t kSntpIntervalMs = 5 * 60 * 1000;  // §4.9: 5 分毎

static M5Stamp_UWB uwb;
static WiFiClient wifiClient;
static PubSubClient mqtt(wifiClient);

// ---- 設定・解算状態 ----
static rtls::AnchorsConfig gCfg;      // rtls/config/anchors (パース済み)
static bool gCfgValid       = false;
static uint32_t gCfgVersion = 0;
static rtls::TuningDef gTuning;
static uint32_t gTuningVersion = 0;
static rtls_solver::TagPipeline* gPipeline = nullptr;
static int gCell = -1;                // オンボードセル (index, -1=未確定)
static cfgstore::Mode gMode = cfgstore::Mode::HYBRID;

// 設定未受信時の測距先 (A案互換: サーバーの anchors 配信 or 既定セル A)
static uint16_t fallbackList[rtls::kMaxCellAnchors] = {0x0010, 0x0011, 0x0013, 0x0014};
static size_t fallbackCount = 4;

static uint32_t seq        = 0;
static uint64_t lastSuperframe = 0;
static uint32_t lastFreerun    = 0;
static char topicRanges[40];
static char topicAnchors[40];
// 12 アンカー + 8 セルの anchors config (~2 KB) を受けられるサイズ (tag-design §5)
static char payload[2048];
static char serialLine[48];
static size_t serialLen = 0;

static uint64_t epochMs() {
    struct timeval tv;
    gettimeofday(&tv, nullptr);
    return (uint64_t)tv.tv_sec * 1000ULL + tv.tv_usec / 1000ULL;
}

static bool timeSynced() {
    return sntp_get_sync_status() != SNTP_SYNC_STATUS_RESET || epochMs() > 1600000000000ULL;
}

// ---- 設定の適用 (NVS 復元と MQTT 受信の共通経路) ----

static rtls_solver::Tuning toSolverTuning(const rtls::TuningDef& t) {
    rtls_solver::Tuning s;
    s.max_age_ms        = t.max_age_ms;
    s.v_max_ms          = t.v_max_ms;
    s.gate_margin_m     = t.gate_margin_m;
    s.residual_gate_m   = t.residual_gate_m;
    s.sigma_a           = t.sigma_a;
    s.sigma_m_floor     = t.sigma_m_floor;
    s.stale_sec         = t.stale_sec;
    s.lost_sec          = t.lost_sec;
    return s;
}

static void rebuildPipeline() {
    delete gPipeline;
    gPipeline = nullptr;
    if (!gCfgValid) return;
    rtls_solver::AnchorInfo table[rtls::kMaxCfgAnchors];
    for (int i = 0; i < gCfg.n_anchors; i++) {
        table[i] = {gCfg.anchors[i].addr, gCfg.anchors[i].x, gCfg.anchors[i].y,
                    gCfg.anchors[i].z, gCfg.anchors[i].bias_mm};
    }
    gPipeline = new rtls_solver::TagPipeline(table, gCfg.n_anchors, gCfg.tag_height_m,
                                             toSolverTuning(gTuning));
    gCell = -1;  // セルは次の解算で再判定
    Serial.printf("# solver ready: anchors=%d cells=%d cfg_v=%lu tune_v=%lu\n",
                  gCfg.n_anchors, gCfg.n_cells, (unsigned long)gCfgVersion,
                  (unsigned long)gTuningVersion);
}

static bool applyAnchorsJson(const char* json, bool persist) {
    static char buf[2048];
    strncpy(buf, json, sizeof(buf) - 1);
    buf[sizeof(buf) - 1] = '\0';
    rtls::stripJsonSpaces(buf);
    rtls::AnchorsConfig parsed;
    if (!rtls::parseAnchorsConfig(buf, &parsed)) {
        Serial.println("# anchors config parse failed — keeping previous");
        return false;
    }
    if (parsed.version <= gCfgVersion) {
        return false;  // 古い/同一バージョンは無視
    }
    gCfg = parsed;
    gCfgValid = true;
    gCfgVersion = parsed.version;
    if (persist) cfgstore::saveAnchors(json, parsed.version);
    rebuildPipeline();
    return true;
}

static bool applyTuningJson(const char* json, bool persist) {
    static char buf[384];
    strncpy(buf, json, sizeof(buf) - 1);
    buf[sizeof(buf) - 1] = '\0';
    rtls::stripJsonSpaces(buf);
    rtls::TuningDef t;
    uint32_t ver = 0;
    if (!rtls::parseTuningConfig(buf, &t, &ver) || ver <= gTuningVersion) {
        return false;
    }
    gTuning = t;
    gTuningVersion = ver;
    if (persist) cfgstore::saveTuning(json, ver);
    rebuildPipeline();
    return true;
}

// ---- MQTT ----

static void onMqttMessage(char* topic, byte* data, unsigned int len) {
    if (len >= sizeof(payload)) return;
    memcpy(payload, data, len);
    payload[len] = '\0';
    if (strcmp(topic, "rtls/config/anchors") == 0) {
        applyAnchorsJson(payload, /*persist=*/true);
    } else if (strcmp(topic, "rtls/config/tuning") == 0) {
        applyTuningJson(payload, /*persist=*/true);
    } else if (strcmp(topic, topicAnchors) == 0 && !gCfgValid) {
        // A案互換: 設定未受信のうちはサーバーの担当アンカー配信に従う (§5)
        uint16_t parsed[rtls::kMaxCellAnchors];
        size_t n = rtls::parseAnchorsJson(payload, parsed, rtls::kMaxCellAnchors);
        if (n >= 3) {
            memcpy(fallbackList, parsed, n * sizeof(uint16_t));
            fallbackCount = n;
        }
    }
}

static void connectWifi() {
    // STANDALONE で AP 不在でも測距を止めないよう、再試行は 30 秒に 1 回・
    // ブロッキング待ちは初回接続時のみとする
    static uint32_t lastTry = 0;
    static bool firstTry = true;
    if (WiFi.status() == WL_CONNECTED) return;
    uint32_t now = millis();
    if (!firstTry && now - lastTry < 30000) return;
    lastTry = now;
    WiFi.mode(WIFI_STA);
    WiFi.begin(WIFI_SSID, WIFI_PASS);
    if (firstTry) {
        for (int i = 0; i < 40 && WiFi.status() != WL_CONNECTED; i++) delay(250);
        firstTry = false;
        Serial.printf("# wifi %s\n",
                      WiFi.status() == WL_CONNECTED ? "connected" : "FAILED (retrying in bg)");
    }
}

static void connectMqtt() {
    if (mqtt.connected() || WiFi.status() != WL_CONNECTED) return;
    char clientId[24];
    snprintf(clientId, sizeof(clientId), "rtls-tag-%04X", (unsigned)NODE_ADDR);
    if (mqtt.connect(clientId)) {
        mqtt.subscribe("rtls/config/anchors", 1);
        mqtt.subscribe("rtls/config/tuning", 1);
        mqtt.subscribe(topicAnchors, 1);
        Serial.println("# mqtt connected");
    }
}

// ---- シリアルコマンド ("mode HYBRID|STANDALONE|QUIET" / "status") ----

static void handleSerialCommand(const char* line) {
    if (strncasecmp(line, "mode ", 5) == 0) {
        cfgstore::Mode m;
        if (cfgstore::parseMode(line + 5, &m)) {
            gMode = m;
            cfgstore::setMode(m);
            Serial.printf("# mode = %s (saved)\n", cfgstore::modeName(m));
        } else {
            Serial.println("# usage: mode HYBRID|STANDALONE|QUIET");
        }
    } else if (strcasecmp(line, "status") == 0) {
        Serial.printf("# mode=%s cfg_v=%lu tune_v=%lu solver=%d cell=%d synced=%d\n",
                      cfgstore::modeName(gMode), (unsigned long)gCfgVersion,
                      (unsigned long)gTuningVersion, gPipeline != nullptr, gCell,
                      (int)timeSynced());
    }
}

static void pollSerial() {
    while (Serial.available() > 0) {
        char c = (char)Serial.read();
        if (c == '\n' || c == '\r') {
            if (serialLen > 0) {
                serialLine[serialLen] = '\0';
                handleSerialCommand(serialLine);
                serialLen = 0;
            }
        } else if (serialLen < sizeof(serialLine) - 1) {
            serialLine[serialLen++] = c;
        }
    }
}

// ---- 測距サイクル (tag-design.md §6) ----

static const uint16_t* cycleAnchors(size_t* count) {
    if (gCfgValid && gCell >= 0 && gCell < gCfg.n_cells) {
        *count = (size_t)gCfg.cells[gCell].n_anchors;
        if (*count > kRangePerCycle) *count = kRangePerCycle;
        return gCfg.cells[gCell].anchors;
    }
    if (gCfgValid && gCfg.n_cells > 0) {
        // セル未確定: 先頭セル (捕捉用) から開始
        *count = (size_t)gCfg.cells[0].n_anchors;
        if (*count > kRangePerCycle) *count = kRangePerCycle;
        return gCfg.cells[0].anchors;
    }
    *count = fallbackCount < kRangePerCycle ? fallbackCount : kRangePerCycle;
    return fallbackList;
}

static void runRangingCycle(uint64_t cycle_t_ms) {
    size_t n = 0;
    const uint16_t* list = cycleAnchors(&n);
    rtls::RangeEntry entries[kRangePerCycle];
    rtls_solver::RangeMeas meas[kRangePerCycle];
    for (size_t i = 0; i < n; i++) {
        M5Stamp_UWBDSRangeConfig cfg = rtls::makeDsRangeConfig(NODE_ADDR, list[i]);
        M5Stamp_UWBDSRangeResult res = uwb.requestDSRange(cfg);
        if (!res.success) {
            delay(1 + (esp_random() % 5));  // 乱数バックオフ後 1 回だけリトライ (§4.4)
            res = uwb.requestDSRange(cfg);
        }
        entries[i] = {list[i], res.success ? res.distanceMm : 0, res.success};
        meas[i]    = {list[i], res.success ? res.distanceMm : 0, res.success};
        if (i + 1 < n && rtls::kDsInterAnchorGapMs > 0) {
            delay(rtls::kDsInterAnchorGapMs);  // 前アンカーが TX→RX に戻る猶予 (ds-twr-design.md §3.3)
        }
    }
    seq++;

    // ---- タグ上解算 (config 受信済みのときのみ) ----
    rtls_solver::PosOut pos;
    if (gPipeline != nullptr) {
        pos = gPipeline->process(seq, cycle_t_ms, cycle_t_ms, meas, (int)n);
        if (pos.valid && pos.state == rtls_solver::TrackState::TRACKING) {
            gCell = rtls::selectCell(gCfg.cells, gCfg.n_cells, pos.x, pos.y, gCell,
                                     gTuning.handover_margin_m);
        }
    }

    // ---- 出力 (モード別, tag-design.md §2) ----
    const bool sendRanges   = (gMode == cfgstore::Mode::HYBRID);
    const bool sendPosition = (gMode != cfgstore::Mode::STANDALONE);
    if (sendRanges && mqtt.connected()) {
        size_t len = rtls::buildRangesJson(payload, sizeof(payload), NODE_ADDR, seq,
                                           cycle_t_ms, entries, n);
        if (len > 0) mqtt.publish(topicRanges, payload);
    }
    if (pos.valid) {
        const char* state =
            pos.state == rtls_solver::TrackState::TRACKING   ? "TRACKING"
            : pos.state == rtls_solver::TrackState::COASTING ? "COASTING"
            : pos.state == rtls_solver::TrackState::STALE    ? "STALE"
                                                             : "LOST";
        const char* cell = (gCell >= 0) ? gCfg.cells[gCell].name : "";
        if (sendPosition && mqtt.connected()) {
            char posbuf[256];
            char topic[40];
            snprintf(topic, sizeof(topic), "rtls/tag/0x%04X/position", (unsigned)NODE_ADDR);
            if (rtls::buildPositionJson(posbuf, sizeof(posbuf), NODE_ADDR, pos.t_ms,
                                        pos.x, pos.y, pos.vx, pos.vy, pos.n_used,
                                        pos.rms, state, cell) > 0) {
                mqtt.publish(topic, posbuf);
            }
        }
        if (gMode == cfgstore::Mode::STANDALONE) {
            uint8_t frame[rtls::kUartFrameLen];
            uint8_t st = pos.state == rtls_solver::TrackState::TRACKING   ? 1
                         : pos.state == rtls_solver::TrackState::COASTING ? 2
                         : pos.state == rtls_solver::TrackState::STALE    ? 3
                                                                          : 0;
            rtls::buildUartFrame(frame, (uint8_t)(NODE_ADDR & 0xFF), st,
                                 (uint32_t)pos.t_ms, pos.x, pos.y, pos.vx, pos.vy,
                                 pos.rms, (uint8_t)pos.n_used);
            Serial1.write(frame, rtls::kUartFrameLen);
        }
    }
}

void setup() {
    Serial.begin(115200);
    Serial1.begin(115200, SERIAL_8N1, RTLS_UART_RX, RTLS_UART_TX);
    delay(1000);
    snprintf(topicRanges, sizeof(topicRanges), "rtls/tag/0x%04X/ranges", (unsigned)NODE_ADDR);
    snprintf(topicAnchors, sizeof(topicAnchors), "rtls/tag/0x%04X/anchors", (unsigned)NODE_ADDR);

    cfgstore::begin();
    gMode = cfgstore::mode();

    // NVS から設定を復元 (Wi-Fi 断・STANDALONE でも解算を継続できる)
    String json;
    uint32_t ver;
    if (cfgstore::loadTuning(&json, &ver)) {
        gTuningVersion = 0;  // 復元は無条件に適用
        applyTuningJson(json.c_str(), /*persist=*/false);
    }
    if (cfgstore::loadAnchors(&json, &ver)) {
        gCfgVersion = 0;
        applyAnchorsJson(json.c_str(), /*persist=*/false);
    }

    while (!uwb.begin(rtls::makeUwbConfig(), rtls::makePhyConfig())) {
        Serial.printf("# uwb begin failed: %s — retrying\n", uwb.lastErrorName());
        uwb.hardReset();
        delay(1000);
    }
    Serial.printf("# tag(prod) addr=0x%04X mode=%s solver=%d chip=%s\n",
                  (unsigned)NODE_ADDR, cfgstore::modeName(gMode), gPipeline != nullptr,
                  uwb.chipName());

    connectWifi();
    sntp_set_sync_mode(SNTP_SYNC_MODE_SMOOTH);  // §4.9: スムーズ補正
    sntp_set_sync_interval(kSntpIntervalMs);
    configTime(0, 0, SNTP_SERVER);

    mqtt.setServer(MQTT_HOST, MQTT_PORT);
    mqtt.setCallback(onMqttMessage);
    mqtt.setBufferSize(2048);  // anchors config が載るサイズ
    connectMqtt();
}

void loop() {
    pollSerial();
    connectWifi();
    connectMqtt();
    mqtt.loop();

    if (timeSynced()) {
        const uint64_t now  = epochMs();
        const int slot      = rtls::slotIndexForTag(NODE_ADDR, rtls::kTagAddrBase);
        const uint64_t frame = rtls::superframeIndex(now);
        if (rtls::inSlot(now, slot) && frame != lastSuperframe) {
            lastSuperframe = frame;
            runRangingCycle(now);
            return;
        }
        uint32_t wait = rtls::msUntilSlot(now, slot);
        delay(wait > 20 ? 20 : (wait > 0 ? wait : 1));
    } else {
        // SNTP 未同期: 単一タグ前提のフリーラン (スロット規律なし, STANDALONE 向け)
        uint32_t now = millis();
        if (now - lastFreerun >= rtls::kSuperframeMs) {
            lastFreerun = now;
            runRangingCycle(now);
        } else {
            delay(10);
        }
    }
}

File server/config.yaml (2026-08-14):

# RTLS 測位サーバー設定 (server-design.md §10)
# 50m フロア・9 アンカー・4 セルの基本設計 §3.3 の配置例。
mqtt:
  host: 127.0.0.1
  port: 1883
floor:
  width_m: 50.0
  height_m: 50.0
  tag_height_m: 1.0
anchors:
  "0x0010": { x: 0.0,  y: 0.0,  z: 2.2, bias_mm: 0 }
  "0x0011": { x: 25.0, y: 0.0,  z: 2.2, bias_mm: 0 }
  "0x0012": { x: 50.0, y: 0.0,  z: 2.2, bias_mm: 0 }
  "0x0013": { x: 0.0,  y: 25.0, z: 2.2, bias_mm: 0 }
  "0x0014": { x: 25.0, y: 25.0, z: 2.2, bias_mm: 0 }
  "0x0015": { x: 50.0, y: 25.0, z: 2.2, bias_mm: 0 }
  "0x0016": { x: 0.0,  y: 50.0, z: 2.2, bias_mm: 0 }
  "0x0017": { x: 25.0, y: 50.0, z: 2.2, bias_mm: 0 }
  "0x0018": { x: 50.0, y: 50.0, z: 2.2, bias_mm: 0 }
cells:
  A: { rect: [0, 0, 25, 25],   anchors: ["0x0010", "0x0011", "0x0013", "0x0014"] }
  B: { rect: [25, 0, 50, 25],  anchors: ["0x0011", "0x0012", "0x0014", "0x0015"] }
  C: { rect: [0, 25, 25, 50],  anchors: ["0x0013", "0x0014", "0x0016", "0x0017"] }
  D: { rect: [25, 25, 50, 50], anchors: ["0x0014", "0x0015", "0x0017", "0x0018"] }
tags: ["0x0001", "0x0002", "0x0003"]
tuning:
  max_age_ms: 500
  v_max_ms: 2.0
  gate_margin_m: 0.6
  residual_gate_m: 0.5
  sigma_a: 1.0
  sigma_m_floor: 0.15
  stale_sec: 2.0
  lost_sec: 10.0
  handover_margin_m: 2.0

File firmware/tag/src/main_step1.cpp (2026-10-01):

// タグ FW (Step 1: 計測モード, DS-TWR / SS-TWR 両対応)
// TARGET_ANCHORS のアンカーへ RANGE_INTERVAL_MS 間隔で巡回測距を行い、
// 1 行 1 測距の CSV をシリアルへ出力する。tools/step1/capture.py で採取する。
//
// 方式は build env で切替 (platformio.ini):
//   env:tag_step1     … DS-TWR (既定)
//   env:tag_step1_ss  … SS-TWR (-DUSE_SS_TWR)。CSV 形式は共通で、
//                       ヘッダ行の mode= により解析側 (analyze.py) が区別する。
// SS-TWR の検証観点 (CFO 補償の有無 = 静的誤差) は ss-twr-design.md §2.2/§6。
//
// 対象アンカー:
//   -DTARGET_ANCHOR=0x0010                  … 1 対 1 (従来どおり)
//   -DTARGET_ANCHORS=0x0010,0x0011,0x0012   … 複数アンカー巡回 (Issue #43)。
//                                              1 サイクルで全アンカーを順に測距する
//   -DINTER_ANCHOR_GAP_MS=2                 … アンカー切替ギャップ [ms]
//                                              (既定 rtls::kDsInterAnchorGapMs)
//
// CSV 列: seq,anchor,ok,d_mm,elapsed_ms,exchange_us,cycle_us,err
//   seq         サイクル通し番号 (同一サイクルの全アンカー行で共通)
//   anchor      相手アンカーのショートアドレス (0x0010 形式)
//   ok          1=成功 0=失敗
//   d_mm        測距距離 [mm](失敗時 0)
//   elapsed_ms  ライブラリ報告の所要時間 [ms]
//   exchange_us requestDSRange() 呼出し全体の実測時間 [µs](ホスト処理込み)
//   cycle_us    サイクル全体 (全アンカー + ギャップ) の所要時間 [µs]。
//               サイクル最後のアンカー行にのみ入り、それ以外は 0
//   err         失敗時のエラー名(成功時 "-")
//
// ds-twr-design.md §6 の 1./2./5.(静的精度・タイミング実測・アンカー間ギャップ)に対応。
#include <Arduino.h>
#include <M5Stamp_UWB.h>
#include <rtls_common.h>

#ifndef NODE_ADDR
#define NODE_ADDR 0x0001
#endif
#ifndef TARGET_ANCHOR
#define TARGET_ANCHOR 0x0010
#endif
#ifndef TARGET_ANCHORS
#define TARGET_ANCHORS TARGET_ANCHOR
#endif
#ifndef RANGE_INTERVAL_MS
#define RANGE_INTERVAL_MS 50
#endif
#ifndef INTER_ANCHOR_GAP_MS
#define INTER_ANCHOR_GAP_MS rtls::kDsInterAnchorGapMs
#endif

static M5Stamp_UWB uwb;

#ifdef USE_SS_TWR
#define RANGING_MODE "SS"
#else
#define RANGING_MODE "DS"
#endif

static const uint16_t kAnchors[]   = {TARGET_ANCHORS};
static const size_t kAnchorCount   = sizeof(kAnchors) / sizeof(kAnchors[0]);
static const uint32_t kGapMs       = INTER_ANCHOR_GAP_MS;

static uint32_t seq        = 0;
static uint32_t okCount    = 0;
static uint32_t errCount   = 0;
static uint32_t lastRange  = 0;
static uint32_t lastReport = 0;

static void initUwbOrHalt() {
    while (!uwb.begin(rtls::makeUwbConfig(), rtls::makePhyConfig())) {
        Serial.printf("# uwb begin failed: %s — retrying\n", uwb.lastErrorName());
        uwb.hardReset();
        delay(1000);
    }
    Serial.printf("# tag addr=0x%04X anchors=", (unsigned)NODE_ADDR);
    for (size_t i = 0; i < kAnchorCount; i++) {
        Serial.printf("%s0x%04X", i ? "," : "", (unsigned)kAnchors[i]);
    }
    Serial.printf(" gap_ms=%lu interval_ms=%d mode=%s chip=%s\n", (unsigned long)kGapMs,
                  (int)RANGE_INTERVAL_MS, RANGING_MODE, uwb.chipName());
    Serial.println("seq,anchor,ok,d_mm,elapsed_ms,exchange_us,cycle_us,err");
}

void setup() {
    Serial.begin(115200);
    delay(1000);
    initUwbOrHalt();
}

void loop() {
    uint32_t now = millis();
    if (now - lastRange < RANGE_INTERVAL_MS) {
        return;
    }
    lastRange = now;
    seq++;

    const uint32_t cycleT0 = micros();
    for (size_t i = 0; i < kAnchorCount; i++) {
        const uint16_t anchor = kAnchors[i];
        const uint32_t t0     = micros();
#ifdef USE_SS_TWR
        M5Stamp_UWBRangeResult res = uwb.requestRange(rtls::makeSsRangeConfig(NODE_ADDR, anchor));
#else
        M5Stamp_UWBDSRangeResult res = uwb.requestDSRange(rtls::makeDsRangeConfig(NODE_ADDR, anchor));
#endif
        const uint32_t exchangeUs = micros() - t0;
        const bool last           = (i + 1 == kAnchorCount);
        const uint32_t cycleUs    = last ? (micros() - cycleT0) : 0;

        if (res.success) {
            okCount++;
            Serial.printf("%lu,0x%04X,1,%ld,%lu,%lu,%lu,-\n", (unsigned long)seq, (unsigned)anchor,
                          (long)res.distanceMm, (unsigned long)res.elapsedMs,
                          (unsigned long)exchangeUs, (unsigned long)cycleUs);
        } else {
            errCount++;
            Serial.printf("%lu,0x%04X,0,0,%lu,%lu,%lu,%s\n", (unsigned long)seq, (unsigned)anchor,
                          (unsigned long)res.elapsedMs, (unsigned long)exchangeUs,
                          (unsigned long)cycleUs, uwb.lastErrorName());
        }
        if (!last && kGapMs > 0) {
            delay(kGapMs);  // 前アンカーが TX→RX に戻る猶予 (ds-twr-design.md §3.3)
        }
    }

    // 10 秒ごとにサマリ(capture.py は '#' 行をメタデータとして扱う)
    if (now - lastReport >= 10000) {
        const uint32_t trials = seq * kAnchorCount;
        float rate = trials ? (100.0f * okCount / trials) : 0.0f;
        Serial.printf("# summary cycles=%lu ok=%lu err=%lu success=%.1f%%\n",
                      (unsigned long)seq, (unsigned long)okCount, (unsigned long)errCount,
                      rate);
        lastReport = now;
    }
}

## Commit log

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2026-08-14 Add Step 1 DS-TWR measurement firmware and analysis tools (refs #1)
    - firmware/lib/rtls_common: shared pin/address/timing constants
    - firmware/anchor: DS-TWR responder loop with periodic stats
    - firmware/tag: 1:1 ranging with exchange-time instrumentation, CSV output
    - tools/step1: serial capture (pyserial) and stdlib-only stats analysis
    (success rate, bias vs true distance, sigma, exchange-time percentiles)
    - firmware/README.md: build/flash and measurement procedure
2026-08-14 Add positioning server (Plan A) with simulator, replay, MQTT, and web UI (refs #3)
    Hardware-free development line per server-design.md §15 (steps 1-3):
    - server/: models, pydantic config, solver pipeline (height correction,
    gating, linearized LSQ + soft_l1 refine, leave-one-out outlier removal,
    CV Kalman), cell manager with hysteresis handover, recorder, replay
    - server/simulate.py + tools/simulate.py: walking-model synthetic ranges
    with noise/NLoS/dropout injection
    - server/app.py + mqtt (aiomqtt) + FastAPI/WebSocket + Canvas floor map UI
    - tools/virtual_tag.py: real-time MQTT publisher standing in for real tags
    - tests: 22 passing incl. e2e regression (CEP50=0.044 m, CEP95=0.24 m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
    [config.yaml]
2026-08-14 Switch package management to uv; add CI status badge to README
    - pyproject: move pytest to PEP 735 dependency-groups (uv default)
    - CI: astral-sh/setup-uv + uv sync/run, commit uv.lock
    - README/firmware docs: uv-based commands
2026-08-15 Add production tag firmware: anchor rotation, TDMA slots, SNTP, MQTT (refs #6)
    - rtls_common: hardware-independent TDMA slot logic (rtls_slots.h) and
    MQTT payload build/parse (rtls_msg.h), host-tested via test_native/run.sh
    - firmware/tag: split into env:tag (production: Wi-Fi + SNTP smooth sync
    5-min interval, per-slot 4-anchor DS-TWR cycle, ranges publish, retained
    anchors subscribe for cell handover) and env:tag_step1 (Step 1 CSV mode)
    - CI: add firmware-native job running host tests
2026-08-15 Add rtls_solver: C++ port of positioning pipeline with Python parity test (refs #8)
    - firmware/lib/rtls_solver (header-only, Arduino-free): geometry (centered
    2x2 normal-equation linear init + soft_l1-weighted IRLS Gauss-Newton with
    divergence guard), gating, fixed-size CV Kalman, pipeline with identical
    state machine and defaults to server/positioning
    - native unit tests mirroring server-design §13-1 cases
    - parity harness + pytest test feeding simulator output to both
    implementations: epoch sets identical, states 100% match,
    diff median 0.0 mm / p99 0.34 mm / max 16.9 mm
    - tag-design.md §10-2: parity tolerance updated to measured criteria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
2026-08-15 Enhance visualization: quality overlay, monitoring panel, truth overlay (refs #10)
    - Position now carries used/rejected anchors (bookkeeping only — numeric
    behavior unchanged, parity test unaffected); exposed in position JSON
    - app: periodic stats broadcast over WebSocket; forward rtls/sim/truth
    (dev mode) to UI
    - virtual_tag: publish ground truth alongside ranges (--no-truth to disable)
    - UI: lines to used anchors, 2s flash for rejected anchors, residual ring,
    anchor health coloring (>30% fail rate warning), stats tables, truth
    overlay with error vector and rolling median error per tag
    - tests: 29 passing incl. web API (TestClient), truth forwarding, stats
    broadcast; live smoke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
2026-08-15 Re-shoot README GIF with single tag; add on-map legend; truth-first publish (refs #10)
    - UI: persistent legend below the floor map explaining markers (estimate,
    ground truth, used ranging lines, rejected-ranging red dashes, anchors)
    - virtual_tag: publish truth before ranges — the UI matches positions
    against the latest truth, so publishing after inflated the displayed
    error by one epoch of walking (~0.6 m); now shows true cm-level error
    - docs/assets/rtls-ui.gif: single-tag capture, palette-optimized, 156 KB
2026-08-15 Add ground-truth trail to floor map; update README GIF (refs #10)
    - UI: dotted GT trail per tag alongside the solid estimate trail (dev
    mode only), legend entry added; truth-item toggles generalized
    - README GIF re-captured with estimate vs GT trails visibly paired
2026-08-15 Add algorithm/application/configuration dev guides, runnable examples, unofficial-project note
    - docs/algorithm-guide.md: simulate->replay->evaluate loop, per-change-type
    guidance, quality gates, Python/C++ parity workflow
    - docs/application-guide.md: position message spec, state/quality handling
    conventions, interface comparison (MQTT/WS/REST/UART)
    - docs/configuration.md: anchor/tag count and placement customization,
    TDMA slot capacity, common failure modes
    - examples/: mqtt_subscriber.py and geofence.py (both verified live
    against the virtual-tag stack; geofence ENTER/EXIT confirmed)
    - README: unofficial personal project note, guide links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
2026-08-15 Add SS-TWR verification firmware envs and tooling (refs #14)
    - rtls_common: makeSsRangeConfig with SS-TWR timing constants
    (ss-twr-design.md §3, official sample defaults)
    - step1 tag FW and anchor FW support DS/SS via build envs
    (tag_step1_ss / anchor_ss, -DUSE_SS_TWR); CSV format shared,
    mode emitted as metadata
    - analyze.py: shows ranging mode per file for DS/SS side-by-side
    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
2026-08-15 Add TDoA PoC firmware and clock-sync analysis tool (refs #16)
    - firmware/tdoa_poc: blink_tx (periodic broadcast blink) and listener
    (receiveFrame + direct qm33120w_sdk dwt_readrxtimestamp read, 40-bit
    CSV output). Compiling this is itself the pre-check for PoC-1 gate
    (SDK symbol reachability from a sketch)
    - tools/tdoa/sync_analysis.py: two-listener clock offset/drift estimation
    with 40-bit wrap unwrapping and corrected-delta stats; PASS/FAIL against
    the 2 ns PoC-2 target; synthetic selftest (recovers 3 ppm drift exactly,
    sigma 0.42 ns from 0.3 ns injected jitter, wrap-crossing case included)
    - tests/test_tdoa_sync.py: 4 host-only regression tests (34 total passing)
    - CI: build f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
    [main_blink.cpp, main_listener.cpp]
2026-08-15 Fix dwt_readrxtimestamp call: pass DWT_COMPAT_NONE segment selector
    The bundled SDK's signature is dwt_readrxtimestamp(uint8_t*, dwt_ip_sts_segment_e);
    DWT_COMPAT_NONE is the documented value for the QM33xxx/DW3xxx dwt_uwb_driver.
    [main_listener.cpp]
2026-08-15 Add browser replay controls and occupancy/residual/error heatmap (refs #26)
    - server/replay_ctrl.py: ReplayController plays recorder/simulator JSONL
    through dedicated pipelines, broadcasting positions (src:'replay') and
    status over the WS hub; pause/resume/stop, speed 0=max, path-traversal
    guarded log resolution
    - REST: /api/replay/{logs,start,pause,resume,stop,status}
    - UI: replay panel (file/speed/progress + header badge) and 1 m-grid
    heatmap overlay (occupancy log-scaled in accent, mean-residual and
    mean-error green->red, reset button); heat accumulates from both live
    and replayed positions
    - tests: 5 new (46 total) incl. full playback, pause/resume, traversal
    rejection; ver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
2026-08-15 Replay: optional truth log selection to feed the error heatmap (refs #26)
    The error heatmap needs ground truth, which replay never delivered
    (truth only flowed live from virtual tags), so 平均誤差 stayed empty
    during replay. ReplayController now accepts a truth JSONL (resolved
    from the same listed dirs), broadcasting each epoch's truth just
    before its position; UI gains a 真値なし/truth-file selector.
    Verified in browser: error heatmap renders green with red hotspots
    at NLoS epochs. Tests updated (47 passing).
2026-08-15 Embed obstacle metadata in simulator logs; restore walls on replay (refs #26)
    Walls were only drawn during live virtual-tag runs (MQTT retained),
    so replays showed none. tools/simulate.py now writes a first-line
    {"meta":{"obstacles":[...]}} record; ReplayController broadcasts it
    at playback start (and an empty list for meta-less logs so stale
    walls from a previous session are cleared). Verified in browser:
    wall rendered during replay with error-heatmap hotspots clustered
    around it. Tests: 48 passing.
2026-08-15 Persist replay obstacles into server state so they survive page reload (refs #26)
    Replay walls were only sent once over WS; a reload re-initialized the
    UI from /api/floor, which the ReplayController never updated. Add an
    obstacles_sink callback wired to RtlsServer.sim_obstacles, and restore
    the replay badge/progress from /api/replay/status at page init.
    Verified in browser: play -> reload -> wall and badge persist.
    Tests: 49 passing.
2026-08-15 Clarify replay file selection: labels, content-based log classification (refs #26)
    - ReplayController classifies logs by content (first data line):
    'ranges' / 'truth' / 'unknown' — independent of filename conventions,
    so recorder logs from real devices classify correctly
    - ranges selector lists only ranging logs; truth selector lists only
    truth logs (plus 真値なし), and shows a disabled
    '真値ログなし (実測ログには真値は存在しない)' state when none exist
    - start() rejects kind mismatches (truth file as ranges and vice versa)
    - explicit labels 測距ログ / 真値ログ(sim) and an explanatory hint that
    real logs have no truth (use the residual heatmap inst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
2026-08-15 Freeze trails while replay is paused: age by data time, not wall clock (refs #26)
    Trail/truth/reject lifetimes were filtered against Date.now(), so a
    paused replay aged everything out within 30 s. Lifetimes now reference
    each tag's latest position t_ms: paused replays freeze completely, and
    any replay speed shows a consistent 30 s of data time. Verified in
    browser: pause -> 38 s wall time -> scene unchanged.
2026-08-15 Draw ground-truth trail whenever truth exists, independent of estimates (refs #26)
    Truth rendering lived inside the per-tag block that was skipped for
    tags with no position (or LOST), and aged against the estimate clock —
    so a truth-only tag was invisible. Truth trail/marker now render before
    the estimate guard using their own time reference (lastTruthTms); the
    error vector still requires an estimate. Verified in browser with a
    truth-only tag: dotted trail + hollow marker render, no error vector.
2026-08-15 Integrate on-tag solver, config distribution (NVS), and UART output (refs #28)
    - rtls_common/rtls_config_msg.h (dependency-free, host-tested): canonical
    parsers for rtls/config/anchors + tuning, onboard cell selection with
    hysteresis, 30-byte UART frame builder (tag-design §7), position JSON
    builder with src:'tag'
    - tools/publish_config.py: publishes canonical retained config from
    server/config.yaml; format locked by tests on both sides
    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
2026-08-16 Add 3D-printable CAD models for anchor mount and tag case (OpenSCAD)
    [anchor_mount.scad, anchor_mount.stl, common.scad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]
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2026-08-18 Fix doc errors and improve beginner readability across docs
    Corrections (docs vs implementation):
    - Replace stale test count "30 tests" with wording that won't go stale
    - Update server-design WebSocket payload example to match models.py to_json
    - Python 3.11+ -> 3.12+ (matches pyproject requires-python)
    - Add missing 4=LOST to the UART frame state table in tag-design
    - Fix DS-TWR residual clock-drift example (2 ps / 0.6 mm, not 4 fs / 1 um)
    - Sync timing defaults with rtls_common.h (kDsFinalTxDelayUus 1800 us,
    kSsRxTimeoutUus 4500 us) and cite the constants as source of truth
    - Update rtls-design repo layout sketch to the actual tree (server/web etc.)
    Consistency:
    - Unify anchors-per-cell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
2026-08-18 Polish Japanese wording in docs (remove calques and misused words)
    - "出版" -> "publish" for MQTT publishing, matching the English term
    used everywhere else in the docs
    - "露出" (calque of "exposed") -> "参照できる"
    - Bare "壁時計" (wall clock) -> "日時そのもの(壁時計時刻)"
    - "姉妹文書" (sister document) -> "関連文書"
    - Fix broken grammar "動作確認を未実施です" -> "動作確認をまだ行っていません"
    - Fix nonexistent verb "抑まる" -> "抑えられる"
    - "機械化" -> "自動化" for sweep automation
    - Table header "向き先" -> "主な用途"
    - Clarify slew correction: contrast step vs slew and gloss the term
    so "スルー" is not mi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
2026-08-18 Clarify antenna note in tag assembly SVG
    "ケース設計時注意" was a crammed noun pile that did not say what to
    watch for; spell out the actual requirement (the case needs an opening
    for the antenna end).
2026-08-18 Polish Japanese wording in code comments
    Apply the same wording fixes as the recent docs pass to comments and
    docstrings (no behavior change):
    - "出版" -> "publish" for MQTT publishing (server/app.py)
    - "機械化" -> "自動化" (tools/sweep.py)
    - Bare "壁時計" (wall clock) -> "実時刻" (rtls_slots.h, main_prod.cpp)
    - "§6-1"-style references to numbered list items -> "§6 の 1." so they
    match how the referenced docs are actually structured (8 places)
    [analyze.py, main_prod.cpp, main_step1.cpp]
2026-08-24 Polish wording and spacing in Markdown docs
    - Fix misleading phrases: "A案の弱点"→"A案に劣る点" (tag-design),
    "SS-TWR のように"→"SS-TWR と違って" (ds-twr-design)
    - Split long sentences and reorder reason clauses for readability
    (rtls-design §4.9/§5, configuration §4, hardware intro)
    - Remove stray half-width spaces between adjacent Japanese words
    (document titles, "かつ 有効距離" etc.)
    Claude-Session: https://claude.ai/code/session_017B3p7a7TTEj9YbU1xeyqcY
2026-08-24 Remove spaces between alphanumerics and Japanese text in docs
    Drop the half-width space on both sides of Latin/digit runs adjacent to
    Japanese (e.g. "Stamp C5 の" -> "Stamp C5の", "4 台" -> "4台"). Fenced
    code blocks, heading numbers and checkbox markers are left untouched.
    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
2026-08-24 Restore spaces around bold markers adjacent to punctuation
    CommonMark cannot treat "**" as a delimiter when the outer side is
    Japanese and the inner side is punctuation (e.g. "は**[link](…)**を").
    Re-add the space on the Japanese side for those cases only.
    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
2026-08-24 Count RangeFrameMismatch as ignored in anchor stats
    respondDSRange() returns RangeFrameMismatch whenever the anchor hears a
    Poll addressed to another anchor, which happens every cycle in a
    multi-anchor cell. Report it separately from real errors (#43).
    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
    [main.cpp]
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2026-10-01 Add purchase and assembly cautions to the hardware guide
    Note the Switch Science SKUs matching the assumed setup, that the DIP
    pin headers need not be soldered (and may not fit the 3D-printed
    parts), the Wi-Fi IPEX antenna required for tags, and the FPC cable
    orientation warning from the product page.
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2026-10-01 Add a Wi-Fi antenna recess to the tag case lid and match the default LiPo
    Place the C5's bundled 14.3x5.3 mm FPC Wi-Fi antenna in a lid recess
    above the C5, away from the UWB antenna and the battery. Change the
    default battery size to the 400 mAh cell listed in the hardware guide
    and note that the DIP pin headers must not be soldered.
    [common.scad, tag_case.scad, tag_case_body.stl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]
2026-10-01 Align the CAD models with the official dimension drawings
    Use the Stamp-C5 DIP and Stamp UWB F Model Size drawings: C5 is
    17.6 x 19.06 mm including the 1.06 mm USB-C overhang, and the UWB F
    antenna sits at an end of the 11.53 mm side (width/length were
    swapped). Recess both back FPC connectors, push the C5 against the
    USB wall with a wider slot, route the FPC over the C5 into a fold bay,
    and keep the floor channel out from under the UWB antenna. Document
    that the battery is soldered to the VBAT/GND pads.
    [anchor_mount.scad, anchor_mount.stl, common.scad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]
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2026-10-01 Pin the pioarduino platform to 55.03.311
    The stable download URL now resolves to 55.03.312, which requires
    PlatformIO Core >= 6.2.0, so a fresh setup on Core 6.1.x fails with
    IncompatiblePlatform. Pin the release the firmware has been built and
    tested with (Arduino core 3.3.11) and note the pinned versions in the
    firmware README.
2026-10-12 Skip the firmware build on documentation-only changes
    Move the ESP32-C5 build matrix out of ci.yml into firmware.yml, which
    only runs when code under firmware/ (excluding Markdown) or the
    workflow itself changes. Each build takes a few minutes and adds
    nothing for doc-only PRs. No status check is required by the main
    ruleset, so a skipped workflow does not block merging.
2026-10-12 Send Serial output over the USB-Serial/JTAG port
    The M5Stamp C5 connects its USB-C straight to the ESP32-C5's
    USB-Serial/JTAG controller. The generic esp32-c5-devkitc-1 board
    does not enable HWCDC, so Serial went to UART0 and the USB serial
    monitor showed only the ROM boot log. Enable ARDUINO_USB_MODE=1 and
    ARDUINO_USB_CDC_ON_BOOT=1 in every project (CDC_ON_BOOT alone fails
    to build because it then expects the TinyUSB USBSerial).
    Verified on hardware: the anchor prints its startup header and stats
    over /dev/cu.usbmodem*.
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2026-10-12 Record hardware results for upload and USB serial in firmware README
    On the M5Stamp C5 the port shows up as /dev/cu.usbmodem*, upload works
    without holding BOOT, and the board resets into the firmware afterwards.
    Also explain the USB CDC build flags and that serial output is dropped
    when no host reads it. Keep BOOT only as a last resort.
2026-10-12 Fail CI on firmware build errors and narrow the README caution
    The esp32-c5-devkitc-1 board definition now flashes and boots on a real
    M5Stamp C5 (#54), so drop continue-on-error from the firmware build.
    Say in the README caution what has been checked on hardware so far.
2026-10-12 Use 850 kbps PHY for the TDoA PoC firmware
    At 6.8 Mbps most blinks failed in the data part (Reed-Solomon sync
    loss) even though preamble and SFD were always detected. Crystal
    offset, preamble length, TX power and pgDelay were ruled out on
    hardware; 850 kbps raised the good-frame rate from 10-72% to 84-93.5%.
    Record the PoC-1 result, the PHY decision and the air time / ALOHA
    capacity estimate in tdoa-design.md section 7.
2026-10-12 Compensate clock offset in SS-TWR on the tag side
    The library's requestRange() computes ToF as (T_round - T_reply) / 2
    with no clock offset correction. On hardware this made SS-TWR read
    73 cm longer than DS-TWR at the same placement (offset -1.285 ppm,
    T_reply 3 ms).
    Add rtls::ssCfoCorrectedMm() and apply it in tag_step1_ss using
    dwt_readclockoffset() right after the response. Corrected SS now
    agrees with DS within about 2 cm. Record the measurements in
    ss-twr-design.md section 7.
2026-10-12 Switch the UWB PHY to 850 kbps with a 256-symbol preamble
    With the library default (6.8 Mbps, preamble 128) DS-TWR succeeded
    only 15-20% of the time at 0.75 m, mostly from data-part decode
    failures. 850 kbps / preamble 256 / PAC16 raised it to about 87%
    (preamble 512 gave 88% but needs a longer final delay and adds 1 ms).
    Distances agree within about 1 cm across PHY settings.
    Also record that a 1500 us response delay fails to schedule
    (TX_START_FAILED, 35% success), so 3000 us stays, and the measured
    8.3 ms exchange time for the TDMA slot budget. The TDoA PoC keeps
    its measured preamble 128 explicitly.
2026-10-12 Extend the DS-TWR final TX delay to 2600 us
    With 1800 us the tag's delayed Final transmission missed its slot
    (TX_START_FAILED) in some antenna orientations, dropping the success rate
    to 2%. 2600 us removed the failures; the exchange grows by about 1 ms
    (success p95 9.3 ms). Update the timing table and slot budget in
    ds-twr-design.md accordingly.
